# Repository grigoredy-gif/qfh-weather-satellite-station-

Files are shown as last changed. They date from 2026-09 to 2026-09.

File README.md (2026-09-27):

# QFH weather-satellite station: my own antenna and an all-discrete receiver

I'm Edy Grigore, an Electrical Engineering student at the University of
Twente. This is my personal project to receive weather satellites on 137 MHz
with hardware I designed myself: a QFH antenna and a superheterodyne receiver
built only from discrete parts (transistors, diodes, coils and capacitors, no
ICs in the signal path).

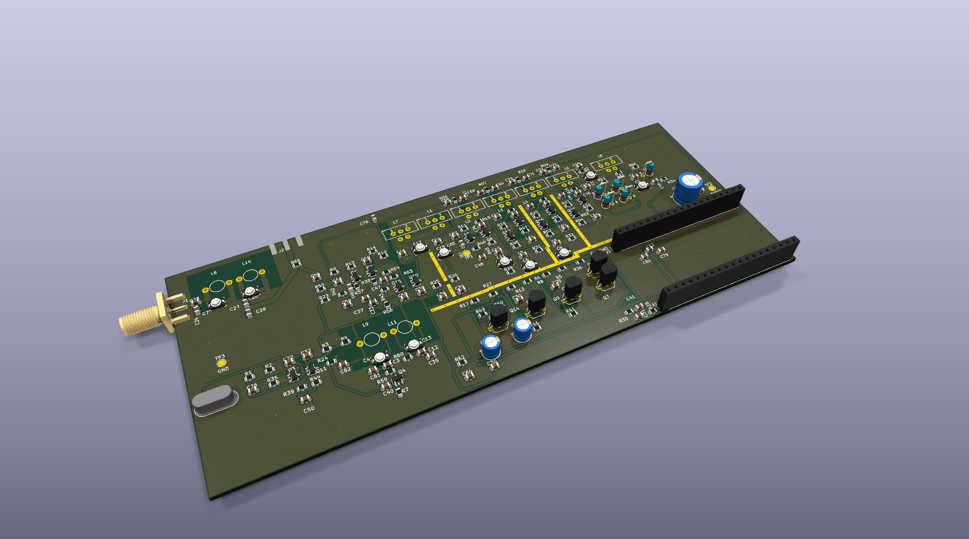
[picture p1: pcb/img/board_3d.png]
3D render of the receiver PCB


## Why I'm doing this

In my first year, the Module 4 project was to design an antenna and a
transmitter PCB. I really enjoyed that field, together with the High Frequency
Electronics, Electromagnetostatics and Electrodynamics courses, so I wanted to
go deeper: design my own antenna and my own receiver, and do the receiver fully
analog so I have to understand every stage at component level.

The NOAA satellites the receiver was designed for were switched off in 2025,
and the remaining Meteor-M satellites send a digital signal an analog FM
receiver cannot decode. So I test the antenna and the receiver separately: the
antenna with an SDR on Meteor-M, the receiver with recorded NOAA passes played
back through an ADALM-Pluto. More in the
[receiver README](fm_receiver/README.md#motivation).

## What's in here

| Folder | What it is | Status |
|---|---|---|
| [`qfh_matlab`](qfh_matlab) | MATLAB toolchain that designs the QFH antenna, exports it to NEC2 and prints a drilling template | antenna designed, simulated and built |
| [`fm_receiver`](fm_receiver) | the receiver design and its LTspice simulations, block by block up to the full chain | simulated from RF input to the ADC |
| [`pcb`](pcb) | the KiCad board for the receiver | designed and checked, ready to order |
| [`lrpt_decoder`](lrpt_decoder) | my own MATLAB analysis chain for Meteor-M LRPT recordings | working; taught me my signal was too weak |
| [`baseband_tools`](baseband_tools) | tools to check an SDR recording before decoding it | working |

## Highlights

- A superheterodyne receiver with about **130 dB** of gain: band-pass filter,
  LNA, mixer, a 25 MHz crystal oscillator multiplied ×5 to 125 MHz, a 12.9 MHz
  IF with four cascode stages, a limiter and a slope detector.
- Every block **simulated in LTspice** on its own, then connected, then the
  whole receiver from an FM input to the audio at the ADC.
- A **2-layer PCB** (180 × 75 mm, 196 parts) with the layout built around RF
  rules: an unbroken ground plane, a straight IF strip, tight tuned circuits
  and test points for block-by-block bring-up.
- The antenna toolchain reproduces its reference program **exactly** (all 127
  NEC wire cards identical) and adds a frequency correction found in simulation.

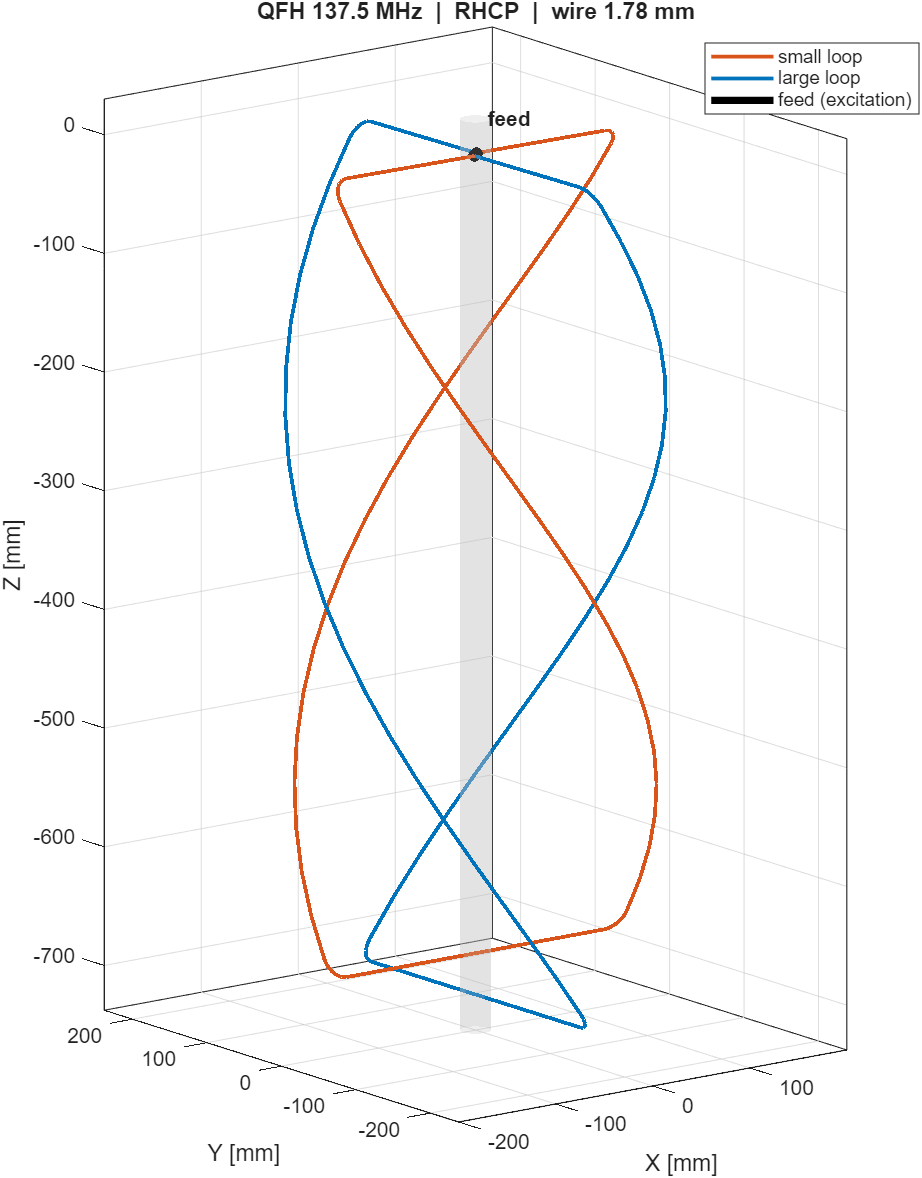
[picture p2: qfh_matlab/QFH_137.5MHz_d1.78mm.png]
QFH antenna model


## What's next

Order and build the PCB, align it one block at a time, and feed it a recorded
satellite pass. On the reception side: an LNA and a 137 MHz SAW filter in
front of the SDR, then another try at Meteor-M.

After that, I want to close the loop with my own hardware on both ends: build
a second QFH antenna and an FM transmitter on my own PCB, and send information
between the two stations, on a frequency I'm allowed to transmit on.

## Tools

LTspice, KiCad 10, MATLAB R2025a, 4nec2 / NEC2, SatDump, an ADALM-Pluto SDR
and a miniVNA Tiny.

## Credits and license

This is my project. I used Claude (Anthropic) as an AI assistant along the
way; each folder's README says exactly what it helped with. The antenna code
is a MATLAB port of John Coppens' online QFH calculator and of QFH2nec, both
GPL-licensed, so `qfh_matlab` is GPL-3.0. Everything else is MIT licensed
(see [LICENSE](LICENSE)).

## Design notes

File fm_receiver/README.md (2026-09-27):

# Discrete FM receiver for 137.9 MHz weather-satellite signals

This is the receiver half of my weather-satellite project. The antenna half (a
QFH antenna with a MATLAB design toolchain) is in [`../qfh_matlab`](../qfh_matlab),
and the circuit board for this receiver is in [`../pcb`](../pcb).

**Goal:** a superheterodyne receiver for the 137.9 MHz weather-satellite band,
built **entirely from discrete parts**: transistors, diodes, coils and
capacitors, with no ICs in the signal path. It demodulates the FM signal down
to the 2400 Hz APT audio tone, and an ESP32's ADC digitizes that audio so
software can turn it into an image. The NOAA satellites that sent APT were
switched off in 2025, so I test with recorded passes played back through an
ADALM-Pluto SDR.

## Motivation

In my first year of Electrical Engineering at the University of Twente, the
Module 4 project was to design an antenna and a transmitter PCB. I really
enjoyed that field, together with the courses that went with it: High Frequency
Electronics, and Electromagnetostatics and Electrodynamics. After the module I
wanted to go deeper than the project allowed, so I decided to design my own
antenna and my own receiver for the 137 MHz weather satellites.

I wanted to do everything analog, without any integrated circuits in the signal
path. That way I have to understand every stage at component level, instead of
letting a chip do the work for me.

The plan had to change along the way. The NOAA satellites whose analog APT
signal this receiver was designed for were switched off in 2025, and the
Meteor-M satellites that are still up send a digital signal that an analog FM
receiver cannot decode. So I test the two halves separately: the antenna with
an SDR on the Meteor-M satellites, and the receiver (once it is built) with
recorded NOAA passes played back into it through an ADALM-Pluto.

The next step is to close the loop with my own hardware on both ends. I want to
build a second QFH antenna and a transmitter, which should be easier than the
receiver, and send information between the two stations with frequency
modulation, using my own PCBs and my own antennas at both ends. That link has
to run on a frequency I'm allowed to transmit on, because 137 MHz is
receive-only for me.

## How it works

```
antenna
   |
band-pass filter 137.9 MHz ---- two coupled air coils, rejects the 112.1 MHz image
   |
LNA (BFR92P) ------------------ about 15 dB of gain, 50 ohm input
   |
mixer <---- LO 125 MHz <------- 25 MHz crystal oscillator > buffer > x5 multiplier
   |
IF filter 12.9 MHz ------------ two coupled toroid tanks, about 200 kHz wide
   |
IF amplifier ------------------ four tuned cascode stages, about 96 dB
   |
limiter > slope detector ------ FM becomes the 2400 Hz audio tone
   |
audio low-pass + level shift -> ESP32 ADC (44.1 kHz) -> APT image in software
```

| Parameter | Value | Why |
|---|---|---|
| RF input | 137.9 MHz | weather-satellite band |
| Crystal | 25 MHz | cheap and standard |
| LO | 125 MHz (25 × 5) | low-side injection |
| **IF** | **12.9 MHz** | 137.9 − 125 |
| Image | 112.1 MHz | lands in the quiet gap between FM broadcast (< 108 MHz) and airband (> 118 MHz) |
| FM deviation | ±17 kHz | APT specification |
| Audio | 2400 Hz subcarrier | the picture is in its envelope |

**The stages, in short:**

- **Band-pass filter.** Two tuned circuits with 82 nH air coils, coupled
  magnetically by their spacing. At 137.9 MHz a coil tap would sit at 0.65 of a
  turn, so a capacitive divider (8.2 pF over 56 pF) does the 50 ohm matching.
  Its main job is to remove the image at 112.1 MHz before it reaches the mixer.
- **LNA.** One BFR92P with shunt feedback and emitter degeneration. It sets
  the noise figure of the whole receiver.
- **Local oscillator.** A 25 MHz crystal Colpitts oscillator, a buffer, and a
  class-C stage that picks out the 5th harmonic (125 MHz) with two coupled
  tanks. A crystal plus a multiplier replaces a PLL: the crystal gives the same
  stability, and I avoid the programmable divider, which is the one block you
  cannot build without ICs.
- **Mixer.** One transistor turns the RF voltage into a current, and a
  transistor pair switched by the LO steers that current into the IF tank. It
  gives about 20 dB of conversion gain.
- **IF filter and amplifier.** Two coupled toroid tanks set the bandwidth, then
  four cascode stages with tapped toroids give about 96 dB of gain. The cascode
  blocks the feedback path through each transistor's collector-base
  capacitance, which is what makes four tuned stages at the same frequency
  possible at all.
- **Limiter and slope detector.** Diodes clip the IF so only the frequency is
  left. A tank tuned slightly off the carrier turns the frequency swing into an
  amplitude swing, and a Schottky diode (1N5711) recovers the audio.
- **Audio chain.** Two Sallen-Key sections built around emitter followers (a
  4th-order Butterworth low-pass), a gain stage, and a divider that centres the signal at 1.26 V in the ESP32 ADC's
  linear range (GPIO36). It has its own RC-filtered supply, so the ESP32's
  current bursts stay out of the audio.
- **Supply.** The ESP32-DevKitC's 5V pin, which is really about **4.6 V**
  (USB VBUS minus a Schottky diode on the module), through a ferrite bead and a
  1000 µF bulk capacitor. The whole receiver draws about 40.7 mA.

## Key design decisions

1. **IF = 12.9 MHz** so the image falls where nothing strong transmits. A simple
   two-resonator filter is then enough, instead of a complex front end.
2. **Crystal × 5 instead of a synthesizer**, to keep the "no ICs" rule without
   losing frequency stability.
3. **Capacitive dividers instead of coil taps** at 137.9 MHz, because the tap
   would need a fraction of a turn.
4. **Cascode IF stages**, because 96 dB of gain at one frequency oscillates
   easily, and the cascode removes the main internal feedback path.
5. **Limiter + slope detector** as the FM demodulator: the simplest discrete
   option, and the one I most wanted to understand.
6. **A fixed capacitor plus a trimmer in every tank**, split so that the trimmer
   lands mid-range even with ±10 % coils and the board's own parasitics.
7. **Design for the real rail.** When I found out the supply is 4.6 V and not
   5.0 V, I re-centred every bias network instead of accepting ~8 dB less IF
   gain.

## Simulations (LTspice)

I simulated every block on its own first, then the connections between blocks,
then the whole receiver. All files are in [`simulations/`](simulations); each sheet has a short
header saying what it tests.

| Sim | What it checks | Key result |
|---|---|---|
| SIM 1 | slope detector | S-curve peak at 12.95 MHz; ~60 mVpp of 2400 Hz, THD 0.78 % |
| SIM 2 | audio filter and ADC interface | flat to 0.70 dB, 45.7 dB down at 22 kHz |
| SIM 3 | IF filter | 200.5 kHz bandwidth at critical coupling |
| SIM 4 | IF amplifier + limiter | 95.8 dB gain; +20 dB in gives only +1.6 dB out |
| SIM 5 | ×5 multiplier | 1.68 V of 125 MHz; 4th and 6th harmonics −36.7 / −42.1 dB |
| SIM 6 | crystal oscillator + buffer | starts and limits at 409.7 mVpp; 2.33 Vpp from the buffer |
| SIM 7 | input band-pass filter | 39.5 dB image rejection, 2.4 dB loss |
| SIM 8 | mixer | 22.8 dB conversion gain |
| SIM 9 | LNA | S21 15.8 dB (about 14 dB expected with the board layout) |
| SIM 10–11 | block interfaces | +20.6 dB from the mixer to the first IF stage |
| SIM 12 | the full receiver on one rail | every bias point matches the block sims; 40.7 mA at 4.6 V |
| SIM 13 | FM in, audio out | a 20 dB input change becomes 0.5 dB at the detector; clean 2400 Hz at the ADC |

End to end the gain is about **130 dB** (−2.2 dB filter, +15.8 dB LNA,
+20.6 dB mixer and IF filter, +95.8 dB IF strip), so the limiter is fully
driven from about −106 dBm at the input. A QFH antenna delivers roughly
−90 dBm from a satellite pass. Most block simulations were run at 5.0 V
before I found the real rail; `sim12` is the one re-centred for 4.6 V and is the
design authority for the PCB.

## Status

- **Done:** every block simulated, the interfaces checked, and the full receiver
  simulated from FM input to the ADC.
- **Done:** the PCB is designed and checked (see [`../pcb`](../pcb)).
- **Next:** order the board, build it, align it one block at a time, and feed it
  a recorded APT pass from the Pluto.

## What I learned

- **A testbench only answers the question you ask it.** Blocks that looked
  finished on their own changed once they were connected: the IF tap had to be
  re-sized and the mixer delivered 4 dB more than the numbers on paper.
- **Check the real supply.** The "5 V" pin on the ESP32 board is 4.6 V, and that
  alone moved the transistor currents by about 16 %.
- **A catalogue beats a schematic.** Trimmer ranges I had specified do not exist
  as real parts, and the transistor I first picked (BFR93A) is obsolete.
- **At VHF the layout is part of the circuit.** A few nanohenries of copper
  moved a filter's trimmer out of range, and 20 mm of track in the LNA's
  emitter would have cost 4–5 dB of gain.
- **Tuned collectors swing above the supply rail.** My first multiplier design
  swung past the transistor's voltage rating.
- **Read the right number.** The wanted spectral line, not the raw
  peak-to-peak; and on the reception side, the mean SNR, not the peak.
- **Predictions can be wrong.** I expected over-coupling the input filter to
  improve image rejection. It made it worse, and I understood why only after
  the simulation.

## Files

| File | What it is |
|---|---|
| [`simulations/`](simulations) | the LTspice simulations `sim*.asc` (short header on each sheet) |
| `simulations/sim12_full_receiver.asc` / `.net` | the full receiver, the design authority for the PCB |
| [`DESIGN_LOG.md`](DESIGN_LOG.md) | the complete step-by-step design log, with every result and revision |
| [`sim_notes.md`](sim_notes.md) | the notes I first wrote on the simulation sheets |

## License / attribution

This is my project. I set the goals and the requirements (a fully discrete
receiver with no ICs in the signal path), I made or approved every design
decision, and the building and bench testing are mine. It builds on
well-documented amateur-radio practice; the references are in the design log.

I used Claude (Anthropic) as an AI assistant. It drafted most of the LTspice
schematics and testbenches from my requirements and helped me analyse the
results. I checked the results and decided what went into the design.

The antenna half of the project (`../qfh_matlab`) is different, because its
code is not originally mine. It is a MATLAB port of two programs that are
freely available online: John Coppens' QFH calculator
([jcoppens.com](https://www.jcoppens.com/ant/qfh/calc.en.php), `qfhcalc.js`,
released under GPL-2.0) and QFH2nec
([github.com/oceantrotter/QFH2nec](https://github.com/oceantrotter/QFH2nec),
GPL-3.0), which itself adapts the Coppens calculator code. That is why
`qfh_matlab` is published under GPL-3.0. The full credits are in its README.

Edy Grigore

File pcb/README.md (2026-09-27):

# PCB — discrete 137.9 MHz FM satellite receiver

This is the circuit board for the receiver I simulated in
[`../fm_receiver`](../fm_receiver). The board is built from that simulation:
its schematic was generated from the full-receiver netlist `sim12`, and if the
board and that netlist ever disagree, the netlist wins.

3D render of the receiver board

## The board at a glance

| | |
|---|---|
| Size | 180 × 75 mm, 2 layers, FR4 1.6 mm |
| Parts | 196, all on the top side |
| Bottom layer | one ground plane |
| Controller | ESP32-DevKitC V4 on a socket (its ADC digitizes the audio) |
| Supply | the DevKitC's 5V pin (really about 4.6 V), about 41 mA |
| Checks | KiCad DRC clean at a 0.254 mm clearance floor; schematic and board match pad for pad |

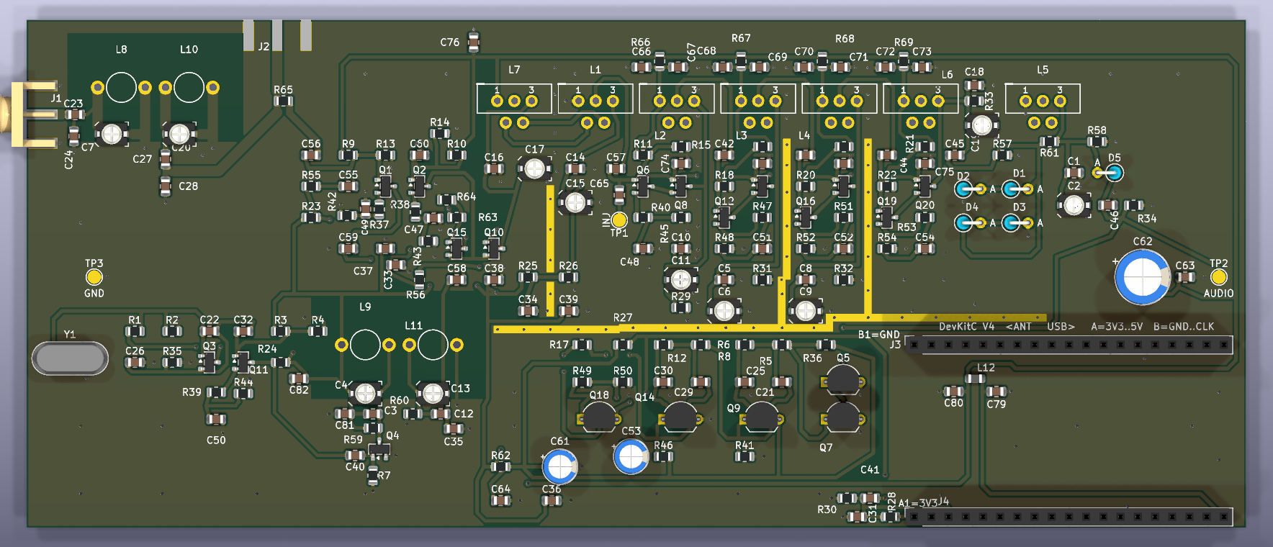
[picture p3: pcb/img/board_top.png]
Top view


## Floorplan

```
+--------------------------------------------------------------------------+
| [SMA ant] BPF (2 air coils, | LNA | MIXER | == IF STRIP, 96 dB, straight |
|  plane cutouts) [SMA test]  | SMD | +T1   |  T2 [1][2][3][4] lim | DET T7 |
|-------- via wall ----------------------------------------------- via wall|
| LO CHAIN: xtal 25MHz | buffer | x5 (2 air coils) -> up into mixer LO port |
|                      AUDIO chain (2400 Hz, folds freely) <- from detector |
|  power entry / bulk filter          ESP32 module socket [USB over edge] > |
+--------------------------------------------------------------------------+
```

The weakest signals (microvolts) start at the left edge and the strongest
(volts) end at the right. The IF strip runs in a straight line with its input
and output at opposite ends, because with 96 dB of gain even a little coupling
from the output back to the input would make it oscillate.

## Layout rules I followed

- **The bottom layer is ground.** Everything is routed on top. A few short
  bottom-layer hops were unavoidable where a trace had to cross another; each
  one is listed and justified in the design log.
- **Shielding provisions for free.** Rows of ground vias between the IF stages
  and between the RF and the LO/audio sections, with exposed ground strips so a
  brass shield can be soldered on later if the strip oscillates.
- **Tight RF loops.** Every tuned circuit's parts sit right at its coil, and the
  LNA's emitter bypass is within about 5 mm of copper of the transistor. At VHF
  a few nanohenries of track change the tuning and the gain.
- **A real 50 ohm antenna input.** The SMA feeds the filter through a 1.5 mm
  coplanar line with ground on both sides.
- **Decoupling everywhere.** Every IF stage has its own 100 nF capacitors on its
  supply and on its cascode bias, fed through its own 10 ohm resistor, so the
  stages cannot talk to each other through the supply.
- **Test points for bring-up.** A second, unfitted SMA with a 0 ohm link at the
  filter→LNA seam (to measure the filter and the LNA separately on a VNA), an
  injection pad at the first IF stage, and a monitor pad on the audio.
- **No parts on the back and no mounting holes**, both on purpose.

The toroids (T37-6, 27 turns) and the air coils (5 mm diameter) use my own
footprints in `qfh_receiver.pretty`. The air-coil footprint keeps copper away
from under the coil, because a ground plane there would kill its Q.

## How I checked it

KiCad's design-rule check is clean at a 0.254 mm clearance floor. The
schematic was generated from the simulation netlist and compared with the board
pad by pad (418 connections, no differences). Every part value was checked
against a real catalogue part at Farnell. I also had the board reviewed by
independent AI review passes, which is how several of the issues below were
found.

## Issues found and fixed

- **Two TO-92 transistor types had base and emitter swapped** because a
  generic symbol used the wrong pin order. Lesson: check each footprint's pinout
  against the datasheet, not against the symbol library.
- **The ESP32 socket would not have powered anything.** The 5 V feed landed on
  a GPIO pin and the enable pin was grounded. I fixed it after checking the
  DevKitC pinout from several sources and every way the module could be
  plugged in.
- **The "5 V" supply is really 4.6 V**, because the DevKitC puts a Schottky
  diode after USB. I re-centred every bias divider in the simulation for 4.6 V
  instead of accepting lower gain.
- **Some specified trimmers did not exist as real parts.** Together with the
  board's own parasitics this pushed three tuned circuits to the end of their
  trimmer range. I re-split the fixed capacitor and the trimmer in each one so
  the trimmer now lands mid-range.
- **The LNA's emitter bypass capacitor was 20 mm from the transistor.** That
  is about 12 nH, which would have cost 4–5 dB of gain. It is now within 5 mm.

## Bring-up plan

1. Power only: check every DC voltage against `sim12`.
2. Local oscillator: 25 MHz at the crystal, then 125 MHz at the mixer.
3. Filter and LNA: fit the test SMA, remove the 0 ohm link, sweep them on the
   VNA. Expect about 39 dB of image rejection and an LNA gain of at least
   13.5 dB.
4. IF strip: with no signal, the limiter output should show only noise (a
   steady tone means it oscillates). Then inject 12.9 MHz at the test pad and
   align the tanks.
5. The whole chain: a recorded APT pass from the Pluto into the antenna input.

Expected trimmer settings: band-pass filter about 6.5 pF, ×5 multiplier about
5.4 pF, LO output about 5.8 pF. If one lands far from that, its coil probably
came out wrong.

## Ordering

The bill of materials with Farnell order codes is `fabrication/qfh_receiver_bom.csv`, and the gerbers for JLCPCB are `fabrication/qfh_receiver_gerbers_jlc.zip`.
Every pF-range capacitor must be NP0/C0G, and the crystal must be a
fundamental-mode part. Both SMAs are edge-launch parts whose pads run to the
board edge on purpose, so the board house may ask about copper at the edge.

## Files

| File | What it is |
|---|---|
| `qfh_receiver.kicad_pro` / `.kicad_sch` / `.kicad_pcb` | the KiCad project, schematic and board |
| `qfh_receiver.kicad_dru` | custom design rules (edge clearance at the two SMAs) |
| `qfh_receiver.pretty/` | my footprints for the toroids and air coils |
| `fabrication/` | the bill of materials and the gerbers for ordering |
| `img/` | board renders |
| [`DESIGN_LOG.md`](DESIGN_LOG.md) | the complete step-by-step design log |

## Attribution

This board is my project: I set the requirements and the layout rules, and I
approved every change. I will assemble, align and measure it myself. I used
Claude (Anthropic) as an AI assistant for the KiCad work: following my
requirements and reviews, it did most of the placement and routing by script,
ran the design checks and did independent review passes. The full step-by-step
record is in [`DESIGN_LOG.md`](DESIGN_LOG.md). The motivation for the project is
in the [receiver README](../fm_receiver/README.md).

Edy Grigore

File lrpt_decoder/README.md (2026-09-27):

# lrpt_decoder — a from-scratch Meteor-M LRPT analysis chain in MATLAB

I wrote these tools in August 2026 to answer one question my station kept
raising: *SatDump's Viterbi locks on Meteor-M N2-3 (137.9 MHz) with BER 0.03,
so why does the deframer never sync and why are there no images?*

> **Correction (9 August 2026):** the first conclusion I drew from these tools
> was wrong. The satellite was fine. My signal was too weak. Details below.

## What I thought at first

Working one tool at a time, I found a fully standard CCSDS link layer (OQPSK
72k, K=7 r=1/2 convolutional coding 171/133 octal, NRZ-M, per-frame CCSDS
randomizer, ASM `1ACFFC1D`, AOS headers ver 1 / SCID 0 / VCID 5 with live
counters). But the frames seemed to come 424 bytes (counter +1) and 1148 bytes
(counter +2) apart instead of in standard 1024-byte CADUs, and the payload
looked like random data. So I concluded that the satellite was sending a
nonstandard mode that no public decoder could turn into images.

## What was actually going on

After searching some forums (r/meteorsatellites), I found out that the
satellite was online and working: other people were receiving images from
Meteor-M N2-3 and N2-4 in the same weeks. Several fellow enthusiasts gave me
the same answers:

- **My signal was too weak and too inconsistent.** The "~10 dB SNR" I trusted
  was SatDump's *peak* SNR, which includes noise spikes. The *mean* SNR was
  only **1.763 dB**, below the ~3–4 dB the deframer needs to lock. "Viterbi
  but no deframer" is the typical sign of a very inconsistent signal.
- **The strange frame sizes were not real.** The 424/1148-byte spacings were
  artifacts of an error-ridden stream, where many ASM detections were simply
  missed.
- **My gain was set badly.** The advice was to start low and raise the gain
  during the pass until the mean SNR is at its best.
- **My location was bad for reception, and the ADALM-Pluto is not ideal for
  this use.** Its input is unfiltered, so FM broadcast (88–108 MHz) overloads
  it and creates intermodulation products, and without an LNA it is quite deaf
  at 137 MHz. The fix is an LNA plus a 137 MHz SAW filter in front of it, which
  is exactly what the input stages of my own receiver do (see
  [`../fm_receiver/`](../fm_receiver/), SIM 7 and SIM 9).
- On top of that, N2-3 was reported to have a degraded antenna, so it is a
  weak satellite to start with.

So the station software and SatDump were fine; the signal was the problem.
The tools themselves still work and are useful for looking inside a weak or
strange recording. Only the conclusion I first drew from them was wrong.

## The tools (run them in this order)

| # | Tool | Question it answers |
|---|---|---|
| 1 | `lrpt_sync.m` | baseband → synchronized symbols. Doppler tracking, open-loop symbol timing from the 72 kHz clock line, OQPSK + plain-QPSK branches, constellation quality metrics |
| 2 | `lrpt_frame_hunt.m` | do CCSDS frames exist? Correlates the encoded-ASM 52-chip template across 96 demod-ambiguity variants; self-tests the encoder against SatDump's correlator constant |
| 3 | `lrpt_loop_test.m` | is it a repeating test loop or changing data? |
| 4 | `lrpt_viterbi_peek.m` | state-seeded Viterbi decode after each ASM; reads the AOS headers |
| 5 | `lrpt_deep_peek.m` | long decodes through whole periods; frame accounting via counters |
| 6 | `lrpt_hdr_scan.m` | exhaustive header scan (every byte offset × both randomizer conventions) |
| 7 | `lrpt_walk.m` | walks the frame chain with a size/step rule; M-PDU/APID census |
| 8 | `lrpt_frame_dump.m` | aligned hex dumps per frame class; finds constant fields by eye |
| 9 | `lrpt_prbs_test.m` | is the payload a modem test pattern? (all ITU O.150 polynomials) |

Everything is base MATLAB (R2025a, no toolboxes). The companion folder
`../baseband_tools/` has the recording-health tools (`baseband_check.m`,
`signal_id.m`, `cut_segment.m`). Run those on any capture first.

## Method notes (learned the hard way)

- **Check the mean SNR before anything else.** If the stream is below the
  decoding threshold, a deep analysis will find "structure" in its own errors.
  That is exactly what happened to me here.
- Never trust a single measurement window or a single timestep. Prove
  convergence/settling with two spaced windows.
- Anchor the analysis in the **densest-detection** region, not at the
  "strongest" correlation peak. Correlation saturates wherever the signal is
  good, so picking the strongest peak first lands on the noisy edge of the pass.
- When a decoder disagrees with the RF evidence, measure one layer deeper
  instead of re-running the decoder with one more setting. But first make sure
  the RF evidence is strong enough to mean something.

## Attribution

I (Edy Grigore) developed these tools together with **Claude (Anthropic)**,
which I used as a coding and DSP-reasoning assistant. The AI drafted the
scripts from hypotheses we came up with together, I ran them on my own
recordings, and each result decided the next step (including throwing out
several of our own wrong hypotheses along the way). The receptions, hardware,
measurements and accept/reject decisions are mine.
Protocol facts were cross-checked against: CCSDS 131.0-B / 732.0-B,
SatDump (Analog Devices / SatDump project sources), dbdexter's
`meteor_demod`, artlav's `meteor_decoder`, USRadioguy's Meteor-M pages and
the happysat status history. The correction of my first conclusion came from
the r/meteorsatellites community.

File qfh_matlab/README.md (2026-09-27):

# qfh_matlab — QFH antenna generator for 137 MHz weather satellites

This is a MATLAB toolchain that designs a **QFH (Quadrifilar Helix) antenna**.
It draws the antenna in 3D and exports a **`.nec` file for electromagnetic
simulation in [4nec2](https://www.qsl.net/4nec2/)**. I made it to receive
137 MHz weather-satellite images (RHCP) with an ADALM-Pluto SDR.

> **Satellite status (2026):** the NOAA POES satellites (analog APT) were
> switched off in June–August 2025 and **no longer transmit**. The
> 137 MHz satellites to target now are **Meteor-M N2-3 / N2-4 (digital LRPT)**
> on 137.1 and 137.9 MHz. They are also RHCP, so the antenna itself does
> not change. The decoding is done with SatDump. A 137.5 MHz design covers
> both frequencies without problems.

## Motivation

In my first year of Electrical Engineering at the University of Twente, the
Module 4 project was to design an antenna and a transmitter PCB. I really
enjoyed that field, together with the courses that went with it: High Frequency
Electronics, and Electromagnetostatics and Electrodynamics. After the module I
wanted to go deeper than the project allowed, so I decided to design my own
antenna and my own receiver for the 137 MHz weather satellites.

For the receiver I wanted to do everything analog, without any integrated
circuits in the signal path, so that I have to understand every stage at
component level. This toolchain is the antenna half of the project. The
receiver half is in [`../fm_receiver`](../fm_receiver).

The plan had to change along the way. The NOAA satellites whose analog APT
signal my receiver was designed for were switched off in 2025, and the
Meteor-M satellites that are still up send a digital signal that an analog FM
receiver cannot decode. So I test the two halves separately: this antenna with
an SDR on the Meteor-M satellites, and the receiver with recorded NOAA passes
played back into it through an ADALM-Pluto.

The next step is to close the loop with my own hardware on both ends. I want to
build a second QFH antenna and a transmitter, which should be easier than the
receiver, and send information between the two stations with frequency
modulation, using my own PCBs and my own antennas at both ends. That link has
to run on a frequency I'm allowed to transmit on, because 137 MHz is
receive-only for me.

## Attribution

This toolchain is my project, but I did not invent the design method, and the
original code is not mine. It is a MATLAB port of programs that are freely
available online:

- **[John Coppens' QFH calculator](https://www.jcoppens.com/ant/qfh/calc.en.php)**:
  the online QFH calculator on John Coppens' website. Its JavaScript source
  (`qfhcalc.js`) is released under **GPL-2.0**. The empirical design formulas,
  the conductor-diameter compensation tables and the dimension conventions all
  come from there. My printable mast-drilling template is also directly
  inspired by the one his design tool generates (wrap-around strips with
  real-size hole circles).
- **[QFH2nec](https://github.com/oceantrotter/QFH2nec)** (`QFH2nec.c`,
  **GPL-3.0**): the wire-by-wire geometry and the NEC2 card export are a
  direct port of this program, which itself adapts the Coppens calculator
  code.
- **[helix2nec](https://uuki.kapsi.fi/qha_simul.html)**: the original
  bifilar-helix-to-NEC generator that QFH2nec is based on.
- **NEC2**: the simulation engine underneath, developed by G. Burke and
  A. Poggio at Lawrence Livermore National Laboratory.

The port was validated against the original: `QFH2nec.c` was compiled with
gcc and the generated NEC geometry was compared line by line. **All 127 GW
cards match with exactly zero coordinate difference** (with
`freq_cal = 1.0`, `c_kms = 299792`, `feed_len_mm = 2`).

The MATLAB code was mostly written with **Claude (Anthropic)** as an AI coding
assistant: the port itself, the plotting/export code, the self-test suite and
the drilling-template generator. I checked the results against the compiled C
original, the output of the Coppens website and, in the end, the antenna I
built from these drawings and measured with a VNA. The antenna itself, its
construction, the measurements and every accept/reject decision are mine.

Edy Grigore

The code comments were first written in Romanian during development and later
translated to English for publication.

## What this port adds on top of the originals

- A modular MATLAB pipeline with parameters (each step is its own `.m` file)
- A 3D view of the antenna in MATLAB (+ PNG export)
- **Frequency calibration** (see the section below). The original
  formulas give a resonance ~2.2% below the requested frequency, and
  this port can correct for it
- A printable 1:1 A4 **drilling template** for the mast. MATLAB makes
  the PDF itself, with wrap-around strips, real-size hole circles and a
  calibration bar. The layout is inspired by the template of the Coppens
  design tool
- An automatic **self-test suite** with 62 checks. It reproduces the
  reference values from the Coppens website, checks that the geometry is
  continuous, validates the .nec structure, and checks the calibration
  math and the drilling-template geometry
- Extra geometry checks that the C original does not have (guards
  against degenerate geometry: `H > 2R`, feed length vs. loop size)
- Two bugs in `QFH2nec.c` that came up during porting (fixed here and
  described below)

## Frequency calibration (`freq_cal`)

**The problem.** The Coppens design formulas are empirical. When I
simulate the geometry they give in NEC2 (free space), the real resonance
is about **2.2% below** the design frequency. For example, a 137.5 MHz
design has its SWR minimum at ≈134.5 MHz.

**The fix.** The whole geometry scales with the wavelength. So if I
design at a slightly *higher* frequency, the resonance moves up
linearly. The `freq_cal` parameter does this internally:

```
effective design frequency = freq_mhz × freq_cal
freq_cal = 137.5 / 134.5 ≈ 1.0223     (derived from the NEC2 sweep)
```

**Verification.** With `freq_cal = 1.0223`, the 4nec2 simulation of the
137.5 MHz target design gives **SWR ≈ 1.05 at 137.5 MHz** (reflection
coefficient ≈ −33 dB), and the SWR minimum sits right on the target. I
checked the factor for both 1.78 mm and 7 mm conductors.

**Why I did not change the Coppens formulas themselves.** They were
calibrated on real, built antennas. Those include effects that a
free-space NEC2 model does not see (feedline, mast, insulation, real
corner shapes). So the difference is a *modeling offset*, not just an
error in the original formulas. I kept the correction as a separate,
documented factor (default **1.0** = the same output as Coppens/QFH2nec).
This way you can choose either convention, and `qfh_selftest` still
checks the port against the website values with `freq_cal = 1.0`. For a
real build, the final trim should be based on a VNA measurement at the
feedpoint.

## Usage

1. Open MATLAB and `cd` into this folder.
2. Edit the parameters in `qfh_main.m` (target frequency, wire diameter…).
3. Run:

   ```matlab
   qfh_main
   ```

   This gives you the dimension table in the Command Window, the 3D
   figure (+ PNG) and the `QFH_137.5MHz_dX.XXmm.nec` file.

4. Open the `.nec` file in 4nec2 (`File > Open 4nec2 in/out file`) and
   run the simulation with `F7` (choose *Far Field pattern*). Then check:
   - impedance / SWR at 137.5 MHz (main window + the SWR plot);
   - the far-field pattern: the main lobe should point to zenith (theta = 0);
   - polarization: the **RHCP** gain must be the strongest toward zenith
     (in 4nec2: *Far field > Polarization > LHCP/RHCP*).

## Files

| File | Role |
|---|---|
| `qfh_main.m` | main script, set your parameters here |
| `qfh_defaults.m` | fills in / validates parameters |
| `qfh_design.m` | dimension computation (port of `compute_design` / Coppens) |
| `qfh_report.m` | construction dimension table |
| `qfh_geometry.m` | 3D geometry: wire list (port of `make_helix`) |
| `qfh_plot3d.m` | 3D visualization in MATLAB |
| `qfh_write_nec.m` | `.nec` export (GW/FR/EX/RP cards) |
| `qfh_selftest.m` | automatic tests (design vs. website, geometry, .nec, calibration) |
| `qfh_drill_marks.m` | drill positions on the mast (wire + support-tube holes) |
| `qfh_write_template.m`| printable 1:1 A4 drilling template (PDF, Coppens-inspired) |
| `qfh_run_template.m`  | generates the template for your mast/support diameters |
| `qfh_wire_compare.m`  | generates two .nec files to compare conductor diameters |

## Verification

```matlab
qfh_selftest
```

Test A reproduces the exact values of the Coppens website calculator for
the reference configuration (137.5 MHz, 7 mm conductor): H1=731.8,
Di1=315, H2=695.8, Di2=299.1, etc. Tests B–E check geometry continuity,
the exported `.nec` structure, the frequency-calibration math and the
drilling-template geometry. As an extra check, the uncalibrated drill
depths (`freq_cal = 1.0`, 1.78 mm wire) match the values in the template
PDF that the Coppens website generates itself, to within 0.1 mm (e.g.
bottom station 687.8 mm, middle station 343.9 mm).

## Conductor diameter (solid copper installation wire)

| Cross-section (FY / H07V-U) | Diameter |
|---|---|
| 1.5 mm² | 1.38 mm  |
| 2.5 mm² | 1.78 mm  |
| 4.0 mm² | 2.26 mm  |
| 6.0 mm² | 2.76 mm  |

Measure your wire with a caliper (without the insulation) and set
`params.wire_d_mm`. The diameter goes into the compensation factor, so
all dimensions are recomputed correctly for your wire. When I simulated
1.78 vs 2.76 mm, the electrical difference was negligible for this
design. So you can choose the wire for mechanical reasons.

## Notes

- **Polarization**: weather satellites transmit RHCP. The QFH radiates
  in *backfire* mode (the lobe comes out of the feed end, upward), so
  the winding direction is opposite to the polarization. The code
  handles this automatically (negative `turns`), the same way as
  QFH2nec.c. You can switch to `LHCP` with `params.polarity`.
- **Bugs found in `QFH2nec.c` while porting** (fixed in this port):
  1. the wire radius is halved twice (once in `compute_design`, once in
     `main`), so the C program writes a radius of `d/4` instead of `d/2`
     into the .nec file;
  2. `h[0].Theta` is used uninitialized (stack garbage). The reference
     build used for the validation was patched with `Theta = 0`.
- **Speed of light**: the Coppens website uses c = 300000 km/s and the C
  code uses 299792. Here the website value is the default (0.07%
  difference). You can change it with `params.c_kms`.
- **Other intentional differences from the C original**: the diameter
  check also accepts thin wires (0.5–50 mm; C requires ≥ 1 mm). The feed
  length can be set (`feed_len_mm`, default 10 mm; C hardcodes 2 mm).
  There are also guards against degenerate geometry (H > 2R etc.) that
  do not exist in C.
- **Template top-hole convention**: the drilling template puts the top
  wire holes on the cardinal axes of the loops (0°/180° and 90°/270°).
  This matches the Coppens template and makes the build easier, and at
  the top the wires are bent a bit toward the offset feed point anyway.
  The *simulated* model keeps the exact QFH2nec feed geometry, where the
  slanted top radials cross the mast wall at ~11.6°/78.4° (default
  build). The difference is ~3 mm of arc at the mast wall (~0.0014 λ),
  which is electrically negligible. Set `params.top_marks = 'exact'` if
  you want to mark the simulated wall crossings instead.
- **Mast circumference**: measure it by wrapping a paper strip or a
  string around the mast. This is much more accurate than holding a
  ruler across a round pipe. Then set `params.mast_d_mm = circumference/pi`,
  and the template strips meet exactly on the seam.
- **Real feed**: when you build it, feed the antenna through an *infinite
  balun* (the coax goes up inside the mast) or add a common-mode choke
  (5–8 turns of coax, ~10–15 cm diameter, right below the feedpoint).
  The impedance of the antenna itself is close enough to 50 Ω, so no
  matching network is needed for reception.

## License

GPL-3.0. This project is a derivative work of GPL-licensed code
(`QFH2nec.c`, GPL-3.0; `qfhcalc.js`, GPL-2.0), so it is published under the
GPL as well. See [LICENSE](LICENSE).

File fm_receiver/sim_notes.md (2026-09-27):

# Simulation sheet notes (archive)

These are the long notes I originally wrote directly on the LTspice schematic sheets, while working through each simulation. In September 2026 I moved them here so the schematics are readable; each sheet now has a short header instead. The notes are kept as written at the time, so some numbers here are older than the current design (for example 5.0 V instead of the real 4.6 V rail, or old trimmer ranges). The current explanation and numbers are in `DESIGN_LOG.md` (full story) and `README.md` (overview).

## slope_tank_test.asc

*Now: Tank test - 12.9 MHz tank resonance sanity check. Explained in fm_receiver/DESIGN_LOG.md, table 'Simulation roadmap (LTspice)', row 0.*

Slope detector tank - .asc connectivity test Resonance ~12.90 MHz (L=2.2uH, C=69.2pF). Plot V(out): peak -6dB at resonance, BW ~210 kHz (Q~60).

## sim1a_slope_scurve.asc

*Now: SIM 1a - slope detector S-curve (rev 5). Explained in fm_receiver/DESIGN_LOG.md, section 'SIM 1 - slope detector'.*

SIM 1a rev2 - slope detector, static S-curve (detected DC vs carrier frequency) REV3: rev1 found the tank detuned low by the detector; rev2's -2.2p (datasheet Cjo) was not enough - measured peak 12.84 MHz -> total parasitic ~3.3p (junction plus diffusion capacitance while the diode conducts). C1 = 65.4p puts the tank at ~12.94 MHz, the optimum detune for the MEASURED Q~122. On the bench this is the trimmer alignment. Two stepped measurements now: Vtank (true tank resonance + drive level, separates tank problems from detector problems) and Vdet (detected DC = the S-curve). Run, then View > SPICE Error Log > right click > Plot .step'ed .meas data. Pass: Vtank peak clearly resolved; Vdet flank steep and quasi-linear through 12.90. REV4: maxstep 5n -> 1n + compression off + .save, after the timestep study (sim1c/1d) showed the 5n run inflated the response ~2x - the diode's conduction pulses and its nonlinear junction capacitance need ~80 points per carrier cycle to integrate honestly. REV5: the CONVERGED S-curve put the resonance at 13.08 MHz with a 520 mV peak - the diode really adds only ~1.9p (not the ~3.3p the coarse 5n run faked) and loads the tank lightly. C1 trimmed 65.4p -> 66.7p, target f0 = 12.955 MHz (+55 kHz above the carrier, the max-slope point for the measured Q ~80). Sweep narrowed to 5 kHz steps. Lesson kept for the README: never trim a design against an unconverged simulation.

## sim1b_slope_demod.asc

*Now: SIM 1b - slope detector FM demodulation (rev 4). Explained in fm_receiver/DESIGN_LOG.md, section 'SIM 1 - slope detector'.*

SIM 1b rev4 - slope detector, dynamic test: real FM in -> audio out REV4: C1 = 66.7p per the CONVERGED S-curve (sim1a rev5): the diode really adds only ~1.9p, so the tank sits at 12.955 MHz, +55 kHz above the carrier = max-slope point. maxstep 1n + compression off (the 5n/2n runs were shown unconverged by sim1d). Source: SFFM carrier 12.9 MHz, deviation +/-17 kHz at 2400 Hz (mod index 7.083). Expected on V(audio): ~0.24 V DC with ~45-55 mVpp of 2400 Hz on top. THD readout (.four, end of SPICE Error Log): use the PARTIAL figure = in-band harmonic distortion of 2400 Hz (target < 5 percent). The TOTAL figure also counts the residual 12.9 MHz ripple, which the stage-10 audio low-pass removes anyway.

## sim1c_debug_dc.asc

*Now: SIM 1c - debug run: modulated vs unmodulated carrier. Explained in fm_receiver/DESIGN_LOG.md, section 'SIM 1 - slope detector'.*

SIM 1c - A/B debug: why did sim1b read 88 mV DC when sim1a says ~245 mV at 12.9 MHz? Same circuit as sim1a/1b rev3. The source is stepped: M=0 (unmodulated carrier) vs M=7.083 (the real APT deviation). Measurement window = exactly one 2400 Hz period. Expected if everything is consistent: Vdc ~245m and Vtankpk ~420m for BOTH steps (the +/-17 kHz swing barely moves the average on the flank). If M=0 already gives ~88m -> file/version mismatch, re-open sim1b from disk. If M=0 gives ~245m but M=7.083 drops -> the modulation itself does it: plot V(tank) zoomed on 100 us to SEE the RF envelope and find out what the FM does to the tank.

## sim1d_timestep_check.asc

*Now: SIM 1d - solver timestep check. Explained in fm_receiver/DESIGN_LOG.md, section 'SIM 1 - slope detector'.*

SIM 1d - timestep convergence check. Same circuit, plain 12.9 MHz carrier. Context: identical circuit gave Vtank 412m / Vdc 245m at maxstep=5n (sim1a) but Vtank 224m / Vdc 87m at maxstep=2n (sim1c). One of them is a numerical artifact: at 5n only ~15 points resolve each carrier cycle and the diode's brief conduction pulses + its nonlinear junction capacitance (~40 uA reactive!) integrate poorly. REV: now at maxstep = 0.5n. Ladder so far: 5n -> 412m/245m, 2n -> 224m/87m,

1n -> 204m/76m. If 0.5n lands near the 1n values, 1n is converged enough.

If Vdc(1n) matches the 2n result (~87m) -> 2n was converged, the 5n run and the naive R_in=RE/2 theory were both optimistic, and the detector loads the tank much harder than designed -> lighter coupling or higher RE needed. Diode current avg/rms tell how.

## sim2a_audio_freq.asc

*Now: SIM 2a - audio low-pass filter (rev 3b). Explained in fm_receiver/DESIGN_LOG.md, section 'SIM 2 - audio filter and ADC scaling'.*

SIM 2a - audio low-pass filter and ADC scaling: FREQUENCY RESPONSE (.ac).

WHAT THIS STAGE IS FOR. The slope detector delivers ~60 mVpp of 2400 Hz on a 0.23 V pedestal, behind ~150k. That is the APT subcarrier, and its amplitude IS the picture: the ESP32 samples this audio at 44.1 kHz and software turns the envelope into pixels. So this block has exactly two jobs - anti-alias filtering before that sampler, and enough gain to use the ADC's range.

WHY ACTIVE AND NOT JUST RC. APT occupies 320-4480 Hz (2400 Hz subcarrier +/- the 2080 Hz pixel rate), and Nyquist for 44.1 kHz sampling is 22 kHz. Three cascaded passive RC poles at fc = 6 kHz only reach ~20 dB at 22 kHz - soft skirts, no resonant poles. Two Sallen-Key sections give a 4th-order Butterworth: ~-46 dB at 22 kHz with under 1 dB of passband ripple, using two transistors. Section 1 (Q2, NPN follower): 10k/10k with 2.7n/2.2n -> Q=0.55, fc 6.5 kHz. Section 2 (Q3, PNP follower): 7.5k/7.5k with 8.2n/1.2n -> Q=1.31, fc 6.8 kHz. Together: Butterworth, corner ~6.6 kHz.

WHY A DARLINGTON AT THE INPUT, AND WHY PNP. The detector's 150k source impedance is brutal: a single transistor's base current through it would shift the detector's own operating point by ~0.3 V - moving the carrier off the slope and wrecking SIM 1's linearity. A Darlington cuts that to ~2 mV. PNP because the chain is DC-coupled and a PNP follower shifts the level UP by one Vbe while an NPN shifts it DOWN. Alternating PNP-NPN-PNP keeps every stage biased inside a single 5 V rail with no coupling capacitors and no negative supply. Starting at 0.23 V: 1.36 V -> 0.74 V -> 1.41 V.

(Not 0.7 V per junction: Vbe = VT*ln(Ic/IS), and Q1a carries only Q1b's BASE

current - about 2 uA - so its Vbe is ~0.50 V while Q1b's, at 0.46 mA, is ~0.64 V. The Darlington shift is +1.13 V, not +1.30 V.)

NOTE ON THE DRAWING: LTspice's PNP symbol sits collector-up, so on Q1a, Q1b and Q3 the GROUND flag is above the device and the supply below it. That looks upside down next to the NPN stages but is electrically right - a PNP's emitter belongs at the positive end. Supply and ground are net labels throughout rather than long rails, which keeps the signal path readable.

GAIN STAGE Q4: common emitter, 150R unbypassed sets the gain by feedback. (REV 3b) Ic ~ 0.85 mA, re ~ 30 ohm, collector load 3.3k in parallel with the 10k/6.2k divider = 1.9k, so Av ~ 9.7. 120 mVpp in becomes ~1.17 Vpp at the ADC - about a third of the 3.3 V range, all inside the ADC linear window. Without this stage the ADC would see 60 mV out of 3.3 V: barely 6 effective bits. CC1/RD1/RD2 re-centre the signal on 1.26 V (the linear region of the ESP32's own 3.3 V rail) and CADC is the last anti-alias pole right at the pin.

CHANGED FROM THE .cir VERSION: supply 5 V -> 6 V, so the whole receiver runs off one rail, and RE4B 3.3k -> 2.7k. The second change came out of a review that actually ran the circuit: with 3.3k the collector sat at 3.69 V, high on a 6 V rail and lopsided for the swing. 2.7k lands it at 3.23 V and drops the in-band THD from 4.66 % to 3.73 % for free - the filter response is unchanged.

PASS (rev 3b): |V(adc)| flat within 1 dB over 400-4400 Hz; >= 30 dB down at 22 kHz (expect ~46-47); the 12.9 MHz IF ripple region annihilated (>100 dB). Gmid is the mid-band gain - it should read ~10-11 (~20 dB) into the ADC node.

REV 2 - BACK TO 5 V (see the README's supply-rail section: the .cir was 5 V, the .asc conversion inherited 6 V, and now the whole receiver runs 5 V). The bias ladder is anchored to the detector pedestal through junction drops, so it does not see the rail; only the PNP follower currents (0.46 -> 0.36 mA, harmless) and Q4's collector DC change. RE4B stays 2.7k rather than reverting to the .cir's 3.3k: THD is dominated by re modulation, which falls with bias current - 2.7k keeps Ic at 0.27 mA, and the swing still has 1.3 V of down-room against 0.76 V of need. Filter shape: rail-independent, unchanged.

REV 3 - THE ESP32 MODULE INTERFACE, and a re-characterization. Decision: the receiver feeds an ESP32 dev MODULE (USB, easy to program and procure), not a bare chip. Three consequences, all handled here. (1) ADC SOURCE IMPEDANCE. The old 47k/47k divider presented 23.5k. The ESP32 SAR ADC wants <10k: with 23.5k and CADC 470p the pin charges with tau = 11 us against a 22.7 us sample period - two time constants, i.e. a sample-dependent error landing straight on picture brightness. (2) ADC LINEARITY. On 1.65 V the old 1.5 Vpp swung to 2.4 V, hard against the ESP32 ADC nonlinear region above ~2.45 V. New divider 10k / 6.2k puts the pedestal at 1.26 V and the swing at 0.6-1.9 V - inside the linear part. Source impedance drops to 3.83k, and supply rejection at the ADC improves from 70 % to 28 % because the collector now works into a lower load. CADC 470p -> 2.2n: a bigger charge reservoir for the SAR, and a 26 kHz pole. (3) SUPPLY NOISE. The module 5 V pin is USB VBUS - laptop SMPS noise plus the ESP32 own 250-500 mA WiFi bursts through cable resistance, i.e. tens to hundreds of mV, with content in the audio band. This block has poor PSRR by construction (ripple reaches the collector through RC4), so it now gets its own rail: RSUP 100 + CSUP 100u = a 16 Hz corner, -43 dB at 2400 Hz, for 0.11 V of drop at the 1.1 mA this chain draws. On the PCB put 100n in parallel with CSUP (an electrolytic alone is useless above ~100 kHz), and keep WiFi off during a pass - record first, transmit afterwards. ALSO REV 3: the drive is now the level SIM 13 actually MEASURED at the detector with the real limiter driving it - 120 mVpp on a 0.31 V pedestal, not the 60 mVpp / 0.23 V that SIM 1 predicted from an idealized source. The real limiter drives the detector tank harder and the S-curve slope grows with drive. Gain therefore falls from ~28 to ~11, which is the point: the 2x overdrive found in SIM 13 is absorbed by the same divider change.

REV 3b - Q4 OPERATING POINT, after the rev 3 run measured 7.5 % THD. Root cause, from the numbers: with 120 mVpp in and re = 86 ohm against 150 ohm of degeneration, v_be swung +/-22 mV against a 25.8 mV V_T - the emitter current was modulated +/-85 %, so re itself swung 47..577 ohm. H2 7.46 % vs H3 0.78 % confirms re modulation, not clipping. WHAT IT ACTUALLY COSTS: the picture lives in the ENVELOPE of the 2400 Hz subcarrier, and H2 at 4800 Hz is outside the envelope band. The metric that matters is gain compression: 10.17 small-signal vs 9.83 large-signal = 3.3 % at full white, which the APT calibration wedge corrects anyway. So rev 3 was usable - but the operating point had become tight (V_CE fell to 0.46 V on negative peaks), so two resistors buy margin AND linearity: RC4 10k -> 3.3k and RE4B 2.7k -> 820. Q4 current rises 0.30 -> 0.81 mA, re falls 86 -> 32 ohm, v_be swing halves to +/-11 mV (0.43 of V_T), the collector sits at 2.2 V and V_CE bottoms at 0.83 V instead of 0.46. Gain is deliberately unchanged (~9.7, ~1.17 Vpp out) - this buys linearity and headroom, not level. Cost: 0.5 mA and 0.06 V more drop across RSUP.

## sim2b_audio_thd.asc

*Now: SIM 2b - audio levels, bias and ESP32 interface (rev 3b). Explained in fm_receiver/DESIGN_LOG.md, section 'SIM 2 - audio filter and ADC scaling'.*

SIM 2b - audio chain: LEVELS, BIAS AND DISTORTION (.tran).

Identical circuit to SIM 2a - see there for the full description. The .ac run proves the filter shape; this one proves the chain is actually biased and linear at the real signal level, which small-signal analysis cannot show.

DRIVE: the MEASURED SIM 13 detector output - 120 mVpp of 2400 Hz on a 0.31 V pedestal, behind 150k. The transient starts from the DC operating point (no uic), so the 100 uF emitter bypass and the 1 uF coupler are pre-charged and the run only needs 20 ms. Measuring from 10 to 20 ms is settled.

THE BIAS LADDER IS THE POINT OF Vef1/Vef2/Vef3. This chain is DC-coupled all the way, so every stage's operating point is inherited from the one before it - there are no coupling capacitors to hide a mistake. The alternating PNP/NPN followers should show the level bouncing rather than drifting: in ~0.31 V -> ef1 ~1.43 -> ef2 ~0.80 -> ef3 ~1.46 V. If any of those walks away, a later stage is starved or saturated and the distortion figure below is meaningless.

Vindc is the honesty check on the Darlington: it should read ~0.31 V, i.e. the amplifier has NOT dragged the detector's pedestal. A single transistor here would pull it by ~0.3 V and quietly move SIM 1's carrier off the straight part of the slope - the fault would look like distortion appearing in the detector, three blocks upstream of its real cause.

PASS (rev 3): Vadcavg ~ 1.26 V   (ESP32 ADC bias - see rev 3 note below) Vadcpp  1.1-1.6 Vpp (0.5-2.0 V window = the ADC's LINEAR region) THD at 2400 Hz < 5 % - read the PARTIAL figure, in band (expect 2-4 %, dominated by the CE stage's re modulation; if it fails, RE4A 150 -> 220)

Vcedc ~ 2.0-2.3 V  (gain stage, must stay >1.1 V for the negative peak) Vindc ~ 0.31 V     (detector pedestal undisturbed)

REV 2 - BACK TO 5 V. Only V2 changes: the DC-coupled ladder is anchored to the detector pedestal through junction drops and never sees the rail. RE4B stays 2.7k (not the old .cir's 3.3k): re modulation dominates the THD and falls with bias current, and Q4 still has 1.3 V of down-room for a 0.76 V swing. Expect the ladder within ~10 mV of the 6 V run, Vadcavg still 1.65 V (it comes from the ESP32's 3.3 V, not from VCC), and THD near 3.5-4.5 %.

REV 3 - THE ESP32 MODULE INTERFACE, and a re-characterization. Decision: the receiver feeds an ESP32 dev MODULE (USB, easy to program and procure), not a bare chip. Three consequences, all handled here. (1) ADC SOURCE IMPEDANCE. The old 47k/47k divider presented 23.5k. The ESP32 SAR ADC wants <10k: with 23.5k and CADC 470p the pin charges with tau = 11 us against a 22.7 us sample period - two time constants, i.e. a sample-dependent error landing straight on picture brightness. (2) ADC LINEARITY. On 1.65 V the old 1.5 Vpp swung to 2.4 V, hard against the ESP32 ADC nonlinear region above ~2.45 V. New divider 10k / 6.2k puts the pedestal at 1.26 V and the swing at 0.6-1.9 V - inside the linear part. Source impedance drops to 3.83k, and supply rejection at the ADC improves from 70 % to 28 % because the collector now works into a lower load. CADC 470p -> 2.2n: a bigger charge reservoir for the SAR, and a 26 kHz pole. (3) SUPPLY NOISE. The module 5 V pin is USB VBUS - laptop SMPS noise plus the ESP32 own 250-500 mA WiFi bursts through cable resistance, i.e. tens to hundreds of mV, with content in the audio band. This block has poor PSRR by construction (ripple reaches the collector through RC4), so it now gets its own rail: RSUP 100 + CSUP 100u = a 16 Hz corner, -43 dB at 2400 Hz, for 0.11 V of drop at the 1.1 mA this chain draws. On the PCB put 100n in parallel with CSUP (an electrolytic alone is useless above ~100 kHz), and keep WiFi off during a pass - record first, transmit afterwards. ALSO REV 3: the drive is now the level SIM 13 actually MEASURED at the detector with the real limiter driving it - 120 mVpp on a 0.31 V pedestal, not the 60 mVpp / 0.23 V that SIM 1 predicted from an idealized source. The real limiter drives the detector tank harder and the S-curve slope grows with drive. Gain therefore falls from ~28 to ~11, which is the point: the 2x overdrive found in SIM 13 is absorbed by the same divider change.

REV 3b - Q4 OPERATING POINT, after the rev 3 run measured 7.5 % THD. Root cause, from the numbers: with 120 mVpp in and re = 86 ohm against 150 ohm of degeneration, v_be swung +/-22 mV against a 25.8 mV V_T - the emitter current was modulated +/-85 %, so re itself swung 47..577 ohm. H2 7.46 % vs H3 0.78 % confirms re modulation, not clipping. WHAT IT ACTUALLY COSTS: the picture lives in the ENVELOPE of the 2400 Hz subcarrier, and H2 at 4800 Hz is outside the envelope band. The metric that matters is gain compression: 10.17 small-signal vs 9.83 large-signal = 3.3 % at full white, which the APT calibration wedge corrects anyway. So rev 3 was usable - but the operating point had become tight (V_CE fell to 0.46 V on negative peaks), so two resistors buy margin AND linearity: RC4 10k -> 3.3k and RE4B 2.7k -> 820. Q4 current rises 0.30 -> 0.81 mA, re falls 86 -> 32 ohm, v_be swing halves to +/-11 mV (0.43 of V_T), the collector sits at 2.2 V and V_CE bottoms at 0.83 V instead of 0.46. Gain is deliberately unchanged (~9.7, ~1.17 Vpp out) - this buys linearity and headroom, not level. Cost: 0.5 mA and 0.06 V more drop across RSUP.

## sim3_if_filter.asc

*Now: SIM 3 - IF filter at 12.9 MHz. Explained in fm_receiver/DESIGN_LOG.md, section 'SIM 3 - the IF filter'.*

SIM 3 - IF filter, 12.9 MHz double-tuned with MAGNETIC coupling. The two tanks share NO galvanic path - the only link is the K statement. That is deliberate: SIM 5 proved capacitive top-coupling has a trap (the coupling cap resonates in series with the below-resonance, inductive-looking second tank and peaks the transfer exactly where rejection was wanted).

DESIGN MATH. Target: 12.9 MHz centre, ~200 kHz -3 dB bandwidth. That is far wider than the 43 kHz the APT signal occupies (Carson: 2*(17k dev + 4.4k audio)), on purpose - the extra room absorbs the Doppler baked into the recording (+/-3.5 kHz), crystal tolerance and alignment error, and a slope detector needs the whole FM spectrum undistorted. L = 2.2 uH -> Z0 = w0*L = 178 ohm; C = 1/(w0^2 L) = 69.2 pF. Coil Q_unloaded ~ 178 (toroid) = Rser 1 ohm -> its own parallel loss is Q*Z0 = 31.7k. With 33k of source/load in parallel, each tank ends up at Q_loaded ~ 91, and BW(-3dB) = sqrt(2)*f0/Q = 201 kHz. Critical coupling is k = 1/sqrt(Q1*Q2) = 1/91 = 0.011.

THE .step IS THE POINT: k = 0.005 (undercoupled - narrow, low transfer), 0.011 (critical - flat top, maximum transfer), 0.022 (overcoupled - two humps, wider with steeper skirts). Plot all three on one graph: this is the coupled-resonator behaviour, measured instead of taken on faith, and it tells us how touchy the coupling adjustment will be on the bench.

REAL BOM (this is a PCB, so nothing exotic): L1,L2  = 27 turns of 0.4 mm enamelled wire on a T37-6 toroid (AL = 3.0 nH/N^2). Toroids are SELF-SHIELDING - important with 75 dB of IF gain on one board. Leads go straight through two PCB holes. C1,C2  = 56 pF NP0 fixed + 5-30 pF trimmer (target 69.2 pF, aligned). RS     = the mixer drain's own output resistance (~33k for a dual-gate MOSFET); no physical part, it is what loads tank 1. RL     = the first IF stage TAPPED DOWN, not a resistor: a 2N3904-class stage at 2 mA has r_pi ~ 1.3k, so the base connects to a tap at ~20% of the turns. SUPERSEDED at integration (SIM 11): the real cascode input is ~6.1k, so the BUILD tap is 13/27 = 48% (the same 0.507u+0.588u coil as every SIM 4 tank). Tapping down is what keeps a low-impedance transistor from destroying the Q. k      = a link winding of ~3 turns on each toroid, the two links wired together (still no galvanic path between the tanks). Turns are trimmed at alignment: one peak = critical, two peaks = too many.

PASS: centre within ~50 kHz of 12.9 MHz and symmetric; BW at k=0.011 in the 150-250 kHz band; >= 20 dB down at +/-500 kHz and >= 30 dB at +/-1 MHz; the three k values reproduce the three coupling regimes. Record V129 for the gain budget - the insertion loss here is paid back by the IF amplifier. If the BW measurement errors out (it references Vpk), read the -3 dB points off the plot with the cursors instead - the FIND measurements stand alone.

## sim4a_if_gain.asc

*Now: SIM 4a - IF amplifier chain (rev 3: four cascode stages, 5 V). Explained in fm_receiver/DESIGN_LOG.md, section 'SIM 4 - the IF amplifier and limiter'.*

SIM 4a rev 3 - IF amplifier chain: FOUR cascode stages on a 5 V rail.

TWO CHANGES FROM REV 2, made together on purpose.

(1) 6 V -> 5 V. Honest history: 6 V was never an architectural choice, it was a repair. In SIM 5 the multiplier's collector swung 17.5 Vpp, past a real BFR93A's 12 V Vceo (a tuned collector swings ABOVE the supply - flywheel effect), so the rail came down to 6 V and then got copied everywhere without being reconsidered. 5 V is the better rail: it is what USB delivers and what the ESP32 already runs on, so the whole receiver takes one cable and no extra regulator. Nothing in this block wanted 6 V.

(2) A FOURTH stage, +23 dB. With the mixer measured at 22.7 dB (not the 12 dB originally assumed), the end-to-end budget becomes -2.2 +15.9 +22.7 -6.2 +93 = ~123 dB at design time (SUPERSEDED: SIM 11 measured the seam in situ; final budget 130 dB / -106 dBm) - i.e. what a QFH actually collects from a decent Meteor pass. That closes the 23 dB gap rev 2 documented. A second LNA stage was considered and REJECTED: it would drop the threshold to -115 dBm, below the ~-113 dBm noise floor, so the limiter would be fully driven by noise alone. Gain past the noise floor buys nothing and costs stability margin.

WHY THE BIAS DIVIDERS CHANGED. This is the block that made 5 V risky: a cascode stacks two Vce plus the tank swing. Keeping rev 2's dividers at 5 V would have left the LOWER transistor only ~0.69 V of Vce - too close to saturation to trust. Two changes fix it, both toward standard values: cascode bias 22k/18k -> 8.2k/10k: unloaded 2.75 V, and a stiffer divider (4.5k Thevenin instead of 9.9k) so the four upper base currents only pull it down 0.19 V -> vb2 = 2.56 V, upper emitter 1.84 V. base bias 47k/13k -> 33k/12k: at 5 V the old divider gave only 0.53 mA; this restores Ic ~1.04 mA, so gm_eff = 4.9 mS, slightly BETTER than rev 2. Result: lower Vce = 1.84 - 0.53 = 1.31 V, MORE headroom than the 6 V version had (1.24 V), and upper Vce = 3.14 V with +/-2.4 V of tank swing available against the ~1.5 V the limiter needs.

PASS: peak within ~100 kHz of 12.9 MHz; total gain (Gout - Vb1) 88-98 dB; -3 dB bandwidth 120-250 kHz (four cascaded tanks narrow it vs three - expect ~200 kHz, still 3x what the signal needs); the four stage gains within a few dB of each other; and Vb1 BELOW 0 dB - the regeneration tell-tale that condemned rev 1 and that the cascode fixed.

STABILITY WARNING, louder than before: 93 dB at one frequency on one board is a lot. The cascode removes the in-device feedback path, but layout, shielding and supply decoupling now decide the outcome, and no simulation can tell you about those. Plan on a shielded compartment for the IF strip with filtered supply feed-through - the classic construction, and at this gain not optional.

## sim4b_if_limiting.asc

*Now: SIM 4b - IF chain + limiter (rev 3). Explained in fm_receiver/DESIGN_LOG.md, section 'SIM 4 - the IF amplifier and limiter'.*

SIM 4b rev 3 - four cascode stages on 5 V: DOES IT STILL LIMIT? (.tran)

Same circuit as SIM 4a rev 3. Limiting is a large-signal effect - an .ac run cannot show it. A limiter's whole job is to make the OUTPUT AMPLITUDE INDEPENDENT OF THE INPUT LEVEL, so the slope detector converts frequency only and fading or AM noise is thrown away instead of becoming picture content.

THE STEP LIST MOVED DOWN BY 26 dB. Rev 2 (3 stages, 70.5 dB) needed ~400 uV to reach the diodes; rev 3 (4 stages, 95.8 dB) needs only ~22 uV. That 26 dB IS the whole point of the fourth stage - it is what moves full limiter drive from -77 dBm to -102 dBm on paper (-106 dBm with the SIM 11 measured seam) at the antenna, i.e. from "bench playback only" to "what a QFH actually collects from a Meteor pass".

Expected: 1 uV -> ~0.05 V (linear), 5 uV -> ~0.27 V (linear), 30 uV -> ~1.2 V (limiting), 300 uV -> ~1.2 V (hard limiting, early stages saturating too). THE LAST TWO BEING NEARLY EQUAL IS THE PASS CRITERION: 20 dB of input change must produce about 1 dB of output change.

The run starts from the DC operating point (no uic), so the 100 nF bypasses and 1 nF couplers are pre-charged and only the RF settles - four tanks of Q ~ 34, tau = Q/(pi.f) ~ 0.84 us each. Two spaced measurement windows PROVE settling rather than assuming it (the SIM 5b rule). NOTE: .tran must start at Tstart = 0 - a non-zero Tstart makes every .meas silently FAIL in LTspice, which cost one full debugging round earlier in this project.

PASS: Voutpp at 30 uV and 300 uV within ~1 dB and >= 2 Vpp; Voutpp_mid == Voutpp; Vc1pp scaling perfectly linearly with the input (limiting belongs at the END of the chain, not the start); the four emitter DC voltages steady across the range - one that walks under overdrive is rectifying, not amplifying; and Vc1adc ~1.85 V, unmoved, which is the cascode holding its job - that node standing still is exactly why there is no Miller feedback.

## sim5_multiplier_x5.asc

*Now: SIM 5 - x5 frequency multiplier (rev 4, 5 V). Explained in fm_receiver/DESIGN_LOG.md, section 'SIM 5 - x5 frequency multiplier (the LO chain)'.*

SIM 5 rev3 - class-C x5 multiplier with MAGNETICALLY coupled double-tuned output. REV3: rev2's capacitive top-coupling barely helped H4 (-18.3 dB): the series coupling cap + the below-resonance (inductive) second tank form a spurious series resonance near ~117 MHz that peaks the transfer right where H4 needs rejection - a classic double-tuned-circuit trap. Fix: transformer coupling (K1 L1 L2 0.03, near-critical k = 1/sqrt(Q1*Q2)), no galvanic path - on the bench this is a link winding / two adjacent coils, exactly like a vintage IF transformer. RP2 raised to 6.8k (Q2~58) for margin on H6, the spur that would convert 137.1 MHz straight onto the IF. PASS: H5 >= 200 mV on V(lo); H4 <= -35 dB (got -36.7; the 40 dB paper target is waived - system-covered by the front BPF, see README), H6 <= -38 dB vs H5; Vt1pp < 12 V. Netlist check: Q1 tank1 base 0 QRF, K1 L1 L2 0.03 present, and tank2 (L2/CT2/RP2 on node lo) has NO wire to tank1 - the only link is the K (mutual inductance) statement.

REV 4 - THE 5 V RAIL. No bias divider here (self-bias), so the only change is V2. The rail cuts BOTH headroom edges: the flywheel top peak moves 1 V further from the 12 V Vceo (good), but the bottom of the swing moves 1 V closer to SATURATION - a class-C collector that touches saturation clips the tank and reshuffles the harmonic balance H5 lives on. Hence the new Vt1min measurement: it must stay well above ~0.5 V at nominal drive. The settled verdict comes from SIM 5b; this file is topology/spurs.

## sim5b_multiplier_drive.asc

*Now: SIM 5b - multiplier drive robustness (rev 3, 5 V). Explained in fm_receiver/DESIGN_LOG.md, section 'SIM 5b - multiplier drive robustness'.*

SIM 5b - drive-robustness check of the class-C x5 multiplier (SIM 5 rev3 circuit, unchanged) driven the way the real buffer drives it: RSRC = 330 ohm source impedance (the rev-2 buffer's collector resistor) instead of an ideal 0-ohm source, and the amplitude stepped 0.65 / 0.75 / 0.95 / 1.15 V around the buffer's measured 2.33 Vpp (A = 1.15 ~ nominal, 0.95 ~ the -20 %

corner). A class-C base is not a polite load - it draws

current pulses on the positive peaks only, and every pulse through 330 ohms bites into the peak exactly when it matters. Vdrvpp measures the actual (sagged) drive after RSRC. REV2: rev1 measured at 4 us and caught the self-bias mid-charge (tau ~ CC*RB = 10 us): the LO was still drifting 10-12% between windows - and it exposed that SIM 5's own 2 us figure (H5 = 4.65 V) was itself measured mid-transient. Rev1's real finding: H5 collapses 8x between A = 0.95 and A = 0.75 - a conduction cliff (self-bias keeps the base at the edge of conduction; the resistive sag itself is a mild 4-8%). Rev2 runs 40 us = 4 tau (settled) and adds A = 0.65 to map the knee. PASS (rev2): Vlopp_mid (20-25 us) == Vlopp (35-40 us) within ~2%, i.e. settled; then judge the H5-vs-drive curve: the operating point must not sit on the cliff - if it does, the fix is more buffer drive and/or softer self-bias (smaller RB), decided from the curve, not guessed. Netlist check: RSRC between nodes in and drv, V1 = SINE(0 {A} 25Meg), the

REV 3 - THE 5 V RAIL. No divider to recompute (self-bias), so V2 is the only electrical change - plus RSRC 270 -> 330, because the rev-2 buffer's actual collector resistor is 330 now (the 270 premise went stale; the curve stays comparable because it is read via the MEASURED Vdrvpp, not via A). The 5 V question is the BOTTOM of the collector swing: the flywheel top gains 1 V of Vceo margin, but the swing minimum drops 1 V toward saturation, and a saturating class-C collector clips the tank and reshuffles the harmonics H5 lives on. Hence Vt1min: at nominal drive it must stay well above ~0.5 V. PASS (rev3, 5 V): settled (mid == final <= 2%); nominal off the cliff; H5 at the -20% corner >= 3x (accepted: 3.4x = 1.02 V) the mixer's 0.3 V need; Vt1min > 0.5 V.

## sim6_xtal_oscillator.asc

*Now: SIM 6 - 25 MHz crystal oscillator (rev 2, 5 V). Explained in fm_receiver/DESIGN_LOG.md, section 'SIM 6 - 25 MHz crystal oscillator'.*

SIM 6 - 25 MHz Colpitts crystal oscillator (common collector, one transistor). The crystal is built from its EQUIVALENT CIRCUIT, visible on the schematic: LM = 2.0265 mH, CM = 20 fF, RSX = 15 ohm (series resonance exactly 25.000 MHz, Q ~ 21000) plus CP = 5p holder capacitance. The huge-L / tiny-C ratio IS the reason quartz is a frequency standard. LTspice's [Misc] xtal symbol is the same thing drawn prettier (a capacitor with Lser/Rser/Cpar). Feedback: C1/C2 capacitive divider (82p/180p) around the emitter follower; the crystal parallel-resonates with the ~61p effective load. Bias: 11k/10k, Ie ~ 3 mA.

REV 2 - THE 5 V RAIL (see the README's supply-rail section). One resistor: R1 15k -> 11k restores the base to 2.38 V so Ie stays at 2.8 mA - the old divider at 5 V would have dropped it 23%, and the limiting amplitude (which the whole LO chain's cliff margin hangs on) would have sagged with it.

STARTUP: simulators have no thermal noise, so a real oscillator sim can sit dead at its DC point forever. The .ic V(b)=0 line yanks the base at t=0 as a kick. Growth is SLOW because Q is huge - expect visible RF only after ~100-300 us and limiting near ~0.5-1 ms. The run takes minutes; that is the crystal's physics. PASS: Vpp_early clearly smaller than Vpp (growth); Vpp stable (limiting reached);

~2 Vpp drive - if the bare oscillator gives less, the next stage is a buffer.

## sim6b_osc_buffer.asc

*Now: SIM 6b - oscillator buffer / multiplier driver (rev 3, 5 V). Explained in fm_receiver/DESIGN_LOG.md, section 'SIM 6 - 25 MHz crystal oscillator' (SIM 6b part).*

SIM 6b - crystal oscillator (SIM 6, unchanged) + buffer/driver stage. The bare oscillator limits at 410 mVpp - deliberately gentle (real crystals carry a max drive-level rating, ~0.1-0.5 mW; overdriving ages them), but the class-C x5 multiplier (SIM 5) was characterized with ~2 Vpp of drive. REV2 (after SIM 5b): the settled drive-vs-H5 curve showed 1.9 Vpp parks the multiplier on its conduction cliff (-18% drive = -7x LO). Fix read off the curve: move the operating point one notch up. RC 270->330 (gain ~6, so 0.41 Vpp -> ~2.3 Vpp) and RE2 100->68 (Ic ~4.1->~5 mA, so the positive peak clears cutoff). Worst -20% corner then lands on the MEASURED 1.76 Vpp point of the curve: H5 = 1.18 V, still 4x what the mixer needs. The 47R unbypassed emitter resistor still sets the gain by feedback; RE2 is bypassed by CE2. The load CC2/RB2 replicates the multiplier's real input network (1n + 10k self-bias), so Vpp_buf is measured into the load it will actually drive. The buffer also ISOLATES the crystal: its ~2.2k input impedance barely touches the osc node (impedance there is tens of ohms), and the multiplier's nonlinear base-current pulses now land on RC, not on the crystal loop. maxstep is 1 ns here (40 pts/cycle) vs SIM 6's 2 ns - comparing Vpp_osc with the earlier 410.6 mVpp doubles as a free convergence check (standing rule: never trust a single timestep). PASS (rev3, 5 V): Vpp_buf ~ 2.2-2.4 Vpp, stable (mid == final window); 25 MHz dominant in .four V(drv) with H2 no worse than rev1 (~-10 dB, else the peak is clipping); Vpp_osc unchanged vs SIM 6; Vbufc_dc ~ 3.2-3.6 V.

REV 3 - THE 5 V RAIL (see the README's supply-rail section). Two resistors, both dividers recomputed to hold the operating points: R1 15k -> 11k keeps the oscillator's Ie at 2.8 mA, and R3 15k -> 12k keeps the buffer's Ic at ~4.9 mA. The buffer one is NOT cosmetic: at 5 V the old divider would give Ic = 3.4 mA, but the positive peak of 2.35 Vpp into the 330||10k load needs 3.7 mA - the stage would clip through cutoff, exactly the defect rev 2 fixed. Headroom at 5 V is fine: collector at ~3.4 V swinging +/-1.2 V stays between 2.2 and 4.6 V, far from both rails.

## sim7_input_bpf.asc

*Now: SIM 7 - input band-pass filter, 50 ohm in and out (rev 2, Sept 2026). Explained in fm_receiver/DESIGN_LOG.md, section 'SIM 7 - the input filter'.*

SIM 7 - input band-pass filter, 137.9 MHz, 50 ohm in and 50 ohm out.

WHAT IT IS FOR. Two jobs, and only one of them is obvious. The obvious one: keep strong out-of-band transmitters out of the LNA - FM broadcast sits at 88-108 MHz and airband at 118-137, both far stronger than a satellite. The one that decides the frequency plan: IMAGE REJECTION. With LO = 125 MHz and IF = 12.9 MHz, the mixer converts BOTH 125+12.9 = 137.9 (wanted) and 125-12.9 = 112.1 (the image) onto the same IF. Nothing downstream can tell them apart afterwards - whatever arrives at 112.1 MHz is inside the receiver forever. This filter is the ONLY defence, which is why 112.1 MHz was chosen to land in the quiet gap between FM broadcast (ends 108) and airband (starts 118) - see the frequency plan in the README.

DESIGN MATH. L = 82 nH -> Z0 = w0*L = 71 ohm at 137.9 MHz; the tank needs 16.24 pF total. That total is split on purpose: 7.15 pF comes from a CAPACITIVE DIVIDER (8.2 pF in series with 56 pF) and ~8.7 pF from a trimmer (~6.7 on the board). The divider does double duty - it is part of the tuning AND it is the impedance transformer: the 50 ohm port sits at the junction, where the tap ratio is 8.2/64.2 = 0.128, so 50 ohm appears across the tank as 50/0.128^2 = 3.05 k (rev 1 had 15p/100p, ratio 0.130, 2.94 k). (A tapped COIL would need a tap at 13% of five turns - i.e. 0.65 of a turn, which does not exist. Capacitors divide continuously, so at VHF the divider replaces the tap. Same idea as SIM 3 and SIM 4, different hardware.)

With coil Q_unloaded ~ 150 (air core, Rser = 0.47) contributing 10.6 k, each tank ends up at Rp = 2.94k || 10.6k = 2.30 k, so Q_loaded = 32 and the coupled-PAIR bandwidth ~6 MHz (sqrt2*f0/Q; measured 6.0). Enormous next to the 43 kHz the signal occupies - deliberately: this filter is not there to be selective, it is there to reject a band 26 MHz away. A narrow front end would only add loss where loss costs noise figure directly, and would need retuning to move anywhere else in the 137-138 MHz satellite band. Critical coupling for Q = 32 is k = 1/Q = 0.031.

MAGNETIC coupling again, no galvanic path between the tanks - the SIM 5 lesson. The .step through k = 0.015 / 0.031 / 0.062 shows under-, critical and over-coupling, exactly as in SIM 3. A prediction written here before the run - that overcoupling would buy image rejection for free through steeper skirts - turned out WRONG: measured rejection at 112.1 MHz was 42.0 dB undercoupled, 37.6 dB critical, 31.6 dB overcoupled. Far from centre the attenuation is set by LOADED Q, not by skirt shape; overcoupling widens the response, which is the same as lowering the effective Q, so the whole curve moves outward. The skirts really are steeper - they just start further out. CHOSEN: critical coupling. Undercoupling buys 4.4 dB more rejection but costs 1.9 dB more insertion loss, and loss ahead of the LNA goes straight into the noise figure. 37.6 dB is already past the 30 dB target.

REAL BOM: L1, L2 = ~5 turns of 0.8 mm enamelled copper wound on a 5 mm former, air core, then squeezed or spread to trim (that is how you tune a VHF coil). Mount them about one coil diameter apart and with axes aligned; that spacing is what sets k ~ 0.03, and it is adjustable by sliding them. Ct1, Ct2 = 3-10 pF trimmer (Murata TZC3; ~8.7 pF here, ~6.7 pF on the board where the layout adds ~8.6 nH + 0.5 pF). C1a/C2a = 8.2 pF NP0, C1b/C2b = 56 pF NP0 - same 0.128 tap ratio as the 15p/100p of rev 1 (Sept 2026, README SIM 7 rev 2).

THIS ONE YOU CAN MEASURE. It is 50 ohm in and 50 ohm out, which is exactly what a miniVNA presents. Build it, sweep it, and compare the trace with this simulation directly - the first block of the receiver that can be verified on the bench with instruments you already own, instead of taken on trust.

PASS: centre within ~2 MHz of 137.9; IMAGE at 112.1 MHz down >= 30 dB from centre; 137.1 MHz (the other Meteor) within ~1 dB of centre; FM broadcast (108) and airband (118) well down; insertion loss at centre small enough that it does not eat the noise figure - record V1379 for the budget.

## sim8_mixer.asc

*Now: SIM 8 - mixer (rev 2, 5 V). Explained in fm_receiver/DESIGN_LOG.md, section 'SIM 8 - the mixer'.*

SIM 8 - the mixer: a single-balanced SWITCHING mixer (half a Gilbert cell, i.e. the top half of the classic SA602), built from three of the same QRF transistors validated in six other simulations.

WHY NOT A BF998 MODEL. The plan called for a dual-gate MOSFET, but LTspice has no BF998 model, and writing one by hand would make the simulation confirm whatever number was typed into it. A switching mixer's conversion gain comes from STRUCTURE instead: chopping the signal current with the LO multiplies it by a square wave whose fundamental is (4/pi)*0.5, so conv gm = gm_eff/pi,  Av_conv = gm_eff*Rp/pi with gm_eff = 1/(re+100) = 8.7 mS and Rp = 6.8k: ~19x = ~25 dB. A formula checkable against the run, not a datasheet act of faith. On the PCB either build it as drawn (3 transistors) or drop in a BF998 - RF, LO and IF interfaces are the same.

HOW IT WORKS. Q1 is a degenerated common-emitter transconductor: RF voltage in, RF current out of its collector (100R unbypassed keeps it linear and predictable, same philosophy as every stage in this receiver). Q2/Q3 sit on top as a differential SWITCH: the LO on Q2's base (Q3's base is the same DC bias, AC-grounded through Cb2) steers Q1's current left-right 125 million times a second. The signal current arrives at the IF tank chopped by the LO - and chopping IS multiplication: 137.9 x 125 -> 12.9 (+262.9, killed by the tank). Q3's collector goes straight to VCC: that half of the current is thrown away (the -3 dB a single-balanced design accepts for simplicity).

THE TANK stands in for SIM 3's first filter resonator: 2.2u + 69.2p at 12.9 MHz, damped to Rp 6.8k (loaded Q ~30, settles in ~0.7 us). The switch collector looks like tens of k - consistent with the 33k source SIM 3 assumed for the real filter.

THE DOUBLE .step ANSWERS TWO QUESTIONS IN ONE RUN (8 combinations): (1) ALO 0.1..0.8 V maps conversion gain vs LO drive. Expect a rise, then a PLATEAU once switching is complete (~0.2-0.3 V) - the SIM 5b lesson: park the operating point on the flat part, not on a cliff. Our LO chain delivers 1.68 V nominal on 5 V (1.02 V at the -20% corner), tapped to ~0.39 V on the board. (2) FRF 137.9 vs 112.1 MHz is the IMAGE demonstration: both are 12.9 MHz away from the 125 MHz LO, so both convert onto the IF with nearly EQUAL gain. The mixer cannot tell them apart, no mixer can - which is the entire reason SIM 7's front filter exists and why its 37.6 dB is the receiver's whole image defence.

BIAS (5 V rail): Q1 base 1.33 V (33k/12k), Ie ~1.7 mA through 100+220 (220 bypassed by 10n - low X at 137.9 AND 12.9 MHz); pair bases at 2.5 V (15k/15k, bypassed), so e23 sits near 1.8 V and Q1 keeps ~1.2 V of Vce. RLO 10k isolates the LO injection from the bypassed bias node.

PASS: conversion gain (from .four: fundamental amplitude / 5 mV) reaching ~19x = 25 dB and FLAT for ALO >= 0.4 (plateau, not cliff); image gain at 112.1 within ~1 dB of 137.9 (proves the point); Vifpp_mid == Vifpp (settled); Ve23dc ~1.8 V and steady across ALO (bias not rectifying).

REV 2 - THE 5 V RAIL. The 6 V figure was never a design decision (see the README); the whole receiver now runs from 5 V. In a STACKED stage the rail change cannot just be typed into V2: both dividers are ratios of VCC, so at 5 V the old values would drop Q1's base to 1.08 V (Ie down ~35%, conversion gain down ~2 dB) and the pair bases to 2.1 V (Q1's Vce squeezed under 0.9 V, flirting with saturation on LO downswings). Fix: recompute the dividers to hold the OPERATING POINT, not the resistor values - RB 47k/13k -> 33k/12k (1.33 V, the same pair used by every IF stage in SIM 4) and RT 18k/13k -> 15k/15k (2.5 V exactly). Same currents, same gm, same Vce as before.

## sim9_lna.asc

*Now: SIM 9 - LNA (rev 2, 5 V). Explained in fm_receiver/DESIGN_LOG.md, section 'SIM 9 - the LNA'.*

SIM 9 - LNA, 137.9 MHz, an EMRFD-style FEEDBACK AMPLIFIER: 50 ohm in and out.

WHY THIS TOPOLOGY AND NOT ANOTHER TUNED STAGE. Two reasons. (1) The SIM 7 filter was designed AND will be aligned against 50 ohm terminations - so whatever follows it must actually present 50 ohm, or the filter's response (and its image rejection) warps. This amplifier's input impedance is set by RESISTOR feedback, not by transistor parasitics, so it holds near 50 ohm across the band and from part to part. (2) Stability by construction: SIM 4 showed what parasitic feedback does to tuned gain stages. Here the deliberate NEGATIVE feedback through Rf swamps the parasitic path - the classic homebrew building block from EMRFD (Hayward/Campbell/Larkin), used by the dozen in every design in that book.

HOW IT WORKS. Two feedbacks set everything: Rf = 470 (collector to base, through Cf so it carries only RF, the DC bias staying independent) and RE1 = 2.2 unbypassed in the emitter. Gain ~ sqrt-of-neither: with the 120 ohm collector load and 50 ohm output termination, Av ~ 33/5 ~ 6.6, and the shunt feedback makes Zin ~ Rf/(1+Av) ~ 63 ohm, trimmed toward 50 by the bias divider's ~347 ohm (910||560) across the input. Expected S21 ~ 16-17 dB into 50 ohm (a couple more into the mixer's high-Z gate).

BIAS (5 V rail): Ie ~ 21 mA (LNAs run hot - large-signal handling for the FM broadcast leftovers that make it past the filter). Divider 910/560 -> Vb 1.83 V loaded, Ve 1.03 V across RE1+RE2 = 49.2 ohm, collector at ~2.5 V (check the DC op point: hover the collector node - it should read ~2.4-2.6 V).

MEASUREMENTS. G1379 is the 137.9 MHz transfer; S21 = G1379 + 6.02 dB (the AC-1 source behind 50 ohm delivers 0.5 V to a matched load, so 0 dB gain reads as -6 dB here). Vb1379 is the INPUT MATCH gauge: exactly 0.5 means a perfect 50 ohm input; 0.42-0.58 keeps VSWR under ~1.5:1, good enough for the filter. Zin = 50*Vb/(1-Vb) if you want the number itself. G20/G300/G700 map the frequency response: a feedback amplifier should be broadband and MONOTONIC - Gpk noticeably above G1379 would mean peaking somewhere, i.e. a resonance that has no business existing in this circuit.

NOISE, honestly: a feedback amp is not the lowest-noise topology (~4-5 dB NF), and LTspice NF numbers would not be trusted anyway (see README). At 137 MHz the galactic background (>1000 K) exceeds the receiver's own noise, and the bench goal - decoding a REPLAYED recording through attenuators - does not depend on NF at all. Match, gain, stability: those it delivers.

REAL BOM: all E24 (470/120/2.2/47/910/560), Q = BFR93A, caps 1n + 100n NP0/X7R. 50 ohm in/out = the second block directly measurable with the miniVNA, sweep against this plot after building.

PASS: S21 15-18 dB at 137.9 (G1379 between 9 and 12 dB); Vb1379 0.42-0.58; response monotonic, Gpk within ~1 dB of the low-frequency plateau; smooth rolloff at 300/700 MHz with no resurgence.

REV 2 - THE 5 V RAIL (see the README's supply-rail section). One resistor: RB1 1.2k -> 910, restoring Vb to 1.90 V so Ie stays at 21 mA - the old divider at 5 V would have dropped it to ~15 mA, costing ~1 dB of S21 and, worse, shifting the 50 ohm input match the SIM 7 filter depends on. The price of 5 V is headroom: collector at 2.5 V, V_CE 1.47 V (was 2.5 V). That is >300x margin over the worst signal this stage ever sees (strong local FM broadcast after the filter's -40 dB: ~4 mVpp at the output), and 31 mW of dissipation - cool for a BFR93A. Compression drops but stays tens of dB above anything the front end can deliver.

## sim10_limiter_detector.asc

*Now: SIM 10 - integration: limiter into detector. Explained in fm_receiver/DESIGN_LOG.md, section 'Integration: SIM 10, 11, 12 - where the standalone testbenches lied'.*

SIM 10 - INTEGRATION: the real limiter driving the real slope detector. SIM 1 characterized the detector from an ideal sine behind an abstract 33k. The real source is SIM 4's limiter: a hard-clipped +/-1.2 V waveform behind the diode clamp (low impedance while clipping) in parallel with Rout 100k. INTERFACE DECISION UNDER TEST: RS 33k becomes a PHYSICAL series resistor between limiter and tank. Then the source impedance the tank sees is 33k + (clamp || 100k || 10k) ~ 33.2k - i.e. SIM 1's characterization holds by construction, and the S-curve centre should NOT move. THE DRIVE REPLICA: SINE 4 V behind RDRV 10k (stage 4's tank damping) into the exact clamp from SIM 4 (DX diodes, Rout 100k) - deep overdrive, like a limiting IF chain delivers. The clipped wave carries harmonics of 12.9 MHz; H3 lands at 38.7 MHz, far outside the tank's Q~80 window - the tank itself is the harmonic filter, which is why slope detectors tolerate square drive. PASS: Vlimpp ~ 2.3-2.7 V (clamp clipping as in SIM 4b); S-curve (Vdet vs F) peak at 12.95 MHz +/- one 5 kHz step (centre unmoved => C1 66.7p alignment target survives integration); Vtank at the peak >= 0.5 V (detector driven at least as hard as in SIM 1); flank through 12.90 quasi-linear. If the peak DOES move, the bench trimmer absorbs it - this sim documents the corrected alignment target, which is exactly its job.

## sim11_mixer_filter_if.asc

*Now: SIM 11 - integration: mixer into IF filter into first IF stage. Explained in fm_receiver/DESIGN_LOG.md, section 'Integration: SIM 10, 11, 12 - where the standalone testbenches lied'.*

SIM 11 - INTEGRATION: mixer -> real double-tuned IF filter -> tapped tank 2 -> first cascode IF stage. Resolves two interface questions the standalone sims left open. (1) TANK 1 IS THE MIXER'S COLLECTOR LOAD. SIM 8's standalone Rp 6.8k was a testbench convenience (fast settling, defined load). Here the filter's first resonator (Ltank/Ctank, the same parts) hangs directly on Q2's collector, loaded only by coil loss and the mixer's own output resistance - loaded Q ~100+, so settling takes ~2.5 us and the run is 12 us with spaced windows. (2) THE TAP WAS RE-SIZED - a real integration catch. SIM 3's BOM note assumed the IF stage input is r_pi ~ 1.3k (bare 2N3904 at 2 mA) and put the tap at 20% of the turns. The REAL SIM 4 stage input is the 33k||12k divider in parallel with a DEGENERATED cascode base (r_pi + beta*180 ~ 20k): ~6.1k total. Through a 20% tap that reflects 152k - the filter would sit nearly unloaded, Q2 ~147, bandwidth ~124 kHz: too narrow, wrong shape. Fix: tap at 13/27 (48%), i.e. THE SAME 0.507u + 0.588u split every SIM 4 tank uses - one coil recipe for the whole IF strip. 6.1k / 0.481^2 = 26k across the tank, Q2 ~81, geometric-mean Q ~95, k crit ~ 0.011 - the 3-turn link and the ~200 kHz design bandwidth survive. Tank 2 cold end grounds; its two sections carry Rser 0.5 each (~1 ohm total, the same Q_U ~178 budget as SIM 3). Coupling: K2/K3 tie tank 1 to both sections of tank 2 at k = 0.011 (one physical link winding); K1 = 0.999 makes the two sections one tapped coil. Stage 1's own tap (tap1) is left unloaded here - its gain reads slightly high, documented, irrelevant to the filter question. The cascode bias divider 8.2k/10k feeds ONE upper base instead of four, so vb2 sits at ~2.70 V (vs 2.56 in SIM 4) and c1a lands near 1.9 V - expected, not a fault.

PASS: Vifpp_mid == Vifpp within ~3% (settled); Ve23dc ~1.78 V and Ve1bdc ~0.328 V (mixer bias untouched by the new load); Vc1adc ~1.9 V, Ves1dc ~0.34 V = Ie 1.04 mA x 330 (stage bias healthy); V(b1) fund. at FRF=138.4 (IF 13.4 MHz, +500 kHz) at least 20 dB below the 137.9 run (SIM 3 alone said -27.9 dB). Record the 137.9 V(b1) fundamental: it is the MEASURED mixer+filter interface gain that replaces the -6.2 dB paper figure in the budget. Gear integrator: hard-switching mixer, the SIM 8 lesson.

## sim12_full_receiver.asc

*Now: SIM 12 - the full receiver: design authority, the PCB is built from this netlist (4.6 V rail since Sept 2026). Explained in fm_receiver/DESIGN_LOG.md ('Integration' and 'The supply rail') and in pcb/README.md.*

SIM 12 - THE FULL RECEIVER. Master schematic, assembled PROGRAMMATICALLY from the verified block files (each band is a pure vertical translation of its source; test sources removed; blocks joined by net labels, never wires). BAND MAP (dy): 0=sim7 BPF | +800=sim9 LNA | +1600=sim11 mixer+IF filter+IF1 | +2400=sim4a IF stages 2-4 + limiter + vb2 divider + V2 | +3300=sim10 detector | +4100=sim2b audio | +4900=sim6b xtal osc + buffer | +5700=sim5 x5. SEAMS (net labels): ant>BPF; n_rf1 BPF>LNA; n_rf2 LNA>mixer RF; n_lo x5-tank tap>mixer LO port; n_t1 IF1 tap>Cc1>IF2 base; out limiter>RS 33k>detector; audio detector>audio chain; bufc buffer>multiplier; vb2 = shared cascode bias, 8.2k/10k feeding FOUR upper bases (the SIM 4 design point); vcc/0. LO TAP (new here, from SIM 5b rev 3): the x5 output tank cap splits 14p (hot to tap) + 47p (tap to gnd): series 10.79p keeps 125 MHz, ratio 14/61 = 0.23 -> 1.68 V x 0.23 ~ 0.39 V at the mixer = its measured plateau point. Real BOM: 12p + 1-10p trimmer on top, 47p NP0 bottom. AUDIO SUPPLY (rev 3): the audio block hangs on net vaud behind RSUP 100 + CSUP 100u - a 16 Hz corner, -43 dB at 2400 Hz. That is not cosmetic: this receiver is powered from an ESP32 module 5 V pin (USB VBUS), and the module own 250-500 mA WiFi bursts would otherwise reach the ADC through RC4. RUN .op FIRST. Expected DC: vcc 5.000; LNA ln_b 1.82 / ln_c 2.58 / ln_e 1.01; mixer brf 1.20, e1b 0.328, e23 ~1.68 STATIC (no LO at .op), if ~5.0; IF strip b1..b4 1.243, c1a..c4a 1.855, es1/e2b/e3b/e4b 0.341, e2/e3/e4 0.527, taps and collectors ~5.0; limiter out 0.00; detector dtank 0, audio 0 - NO CARRIER AT DC, so the audio ladder sits ~0.31 V below its operating values; adc ~1.26 (from the ESP32 3.3 V through RD1/RD2, immune to VCC), adcref 3.30; oscillator o_b ~2.24, osc ~1.50, bufc ~3.42; multiplier DEAD at DC (class C with no drive): xbase ~0, xtank1 ~5.0, lo/n_lo 0. Total draw 41.6 mA measured (~208 mW). FOR TRANSIENT RUNS a full-chain tran is impractical (2400 Hz audio needs 400 us; 137.9 MHz needs 0.1 ns steps; the crystal needs ~1 ms to start). Substitute the crystal with SINE(0 0.205 25Meg) - the measured 410 mVpp - and run sub-chains; SIM 13 does exactly that for the IF-to-ADC half. NET-NAME NOTE: LTspice canonicalises each net to ONE name, so two seam labels are shadowed - the BPF>LNA node reads tapB (not n_rf1) and the IF1>IF2 node reads b2 (not n_t1). Connectivity is correct (see the generated

VERIFICATION: this file is checked with LTspice.exe -netlist and the netlist audited line by line - definitive, and it supersedes coordinate re-derivation. A wire spanning EXACTLY a part two pins is ABSORBED by the part, not a short.

## sim13_fm_endtoend.asc

*Now: SIM 13 - FM in, audio out (end to end). Explained in fm_receiver/DESIGN_LOG.md, section 'SIM 13 - the money shot: FM in, audio out'.*

SIM 13 - THE MONEY SHOT: a true APT-format FM signal in, audio out at the ADC. Source SFFM(0 A 12.9Meg 7.083 2400) = 12.9 MHz carrier, FM by 2400 Hz at +/-17 kHz deviation - exactly what NOAA APT puts on the IF after the mixer. Injected at the IF-chain input because FM survives frequency conversion untouched; the RF half (+20.6 dB) is already measured in SIM 11, and putting 137.9 MHz in a 2 ms run would need 0.1 ns steps = 4e9 points, impossible. Chain under test: 4 cascode IF stages -> limiter -> RS 33k -> slope detector -> full audio chain -> ADC node. 1 ns steps, 2 ms, two amplitude steps. THE POINT OF THE TWO STEPS: 100 uV and 1 mV are 20 dB apart, both far past the ~22 uV limiting threshold. If the receiver works, V(adc) reads the SAME 2400 Hz at the SAME amplitude in both - limiting has erased the AM, which is why FM survives fading and why this architecture exists at all. THE ACQUISITION TRANSIENT (found by rev 1, kept as a documented finding). Starting from the no-carrier DC point, the pedestal steps 0 -> 0.31 V; the audio gain stage 100 uF emitter bypass holds the old bias, the whole step lands on the emitter degeneration and the stage saturates for the entire window (rev 1 read V(adc) = -0.55 V) while everything upstream was perfect. That is REAL receiver behaviour - the first ~50-100 ms of audio after a carrier appears are garbage while CC1/CE4 find the new pedestal, irrelevant in a 10-minute pass. Here .ic V(audio)=0.31 presets the settled state. EXPECTED (audio chain at rev 3b): Voutpp ~2.3-2.5 V both steps (clamped); Vauddc ~0.31, Vaudiopp ~110-130 mVpp; Vadcpp ~1.1-1.3 Vpp EQUAL between the two steps within ~1 dB - that equality is the whole point; Vadcavg ~1.26.

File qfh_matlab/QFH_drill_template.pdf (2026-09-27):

# QFH mast drilling template - target 137.500 MHz

Layout inspired by the ON6JC/LW3HAZ QFH design tool by John Coppens - jcoppens.com/ant/qfh
Mast dia. 32.6 mm (circumference 102.5 mm) | support tube dia. 15.9 mm | wire dia. 1.78 mm | generated by qfh_matlab
1. Print at 100% / "Actual size" (never "fit to page"). Check: the calibration bar below must measure exactly 100.0 mm.
2. Draw a straight SEAM line along the mast. On it, mark the depth of every station (table below), measured from the antenna top plane (depth 0 = feed level).
3. Cut out each strip and wrap it around the mast, printed side out: 0-deg edge on the seam, station line(s) on the matching depth mark(s). The strip ends must meet on the seam.
4. WRAP DIRECTION MATTERS: seen from the TOP of the mast, angles must increase counter-clockwise. Wrapping the other way mirrors the antenna (LHCP instead of RHCP!).
5. SANITY CHECK after wrapping: deeper station lines must sit LOWER on the mast (large-loop middle below small-loop middle). If inverted, the strip is wrapped the wrong way.
6. Drill through the center of every circle: small circles = wire holes (dia. 1.78 mm), large circles = support-tube holes (dia. 15.9 mm).
7. Equal letters = same helix arm (A/B = small loop, C/D = large loop).

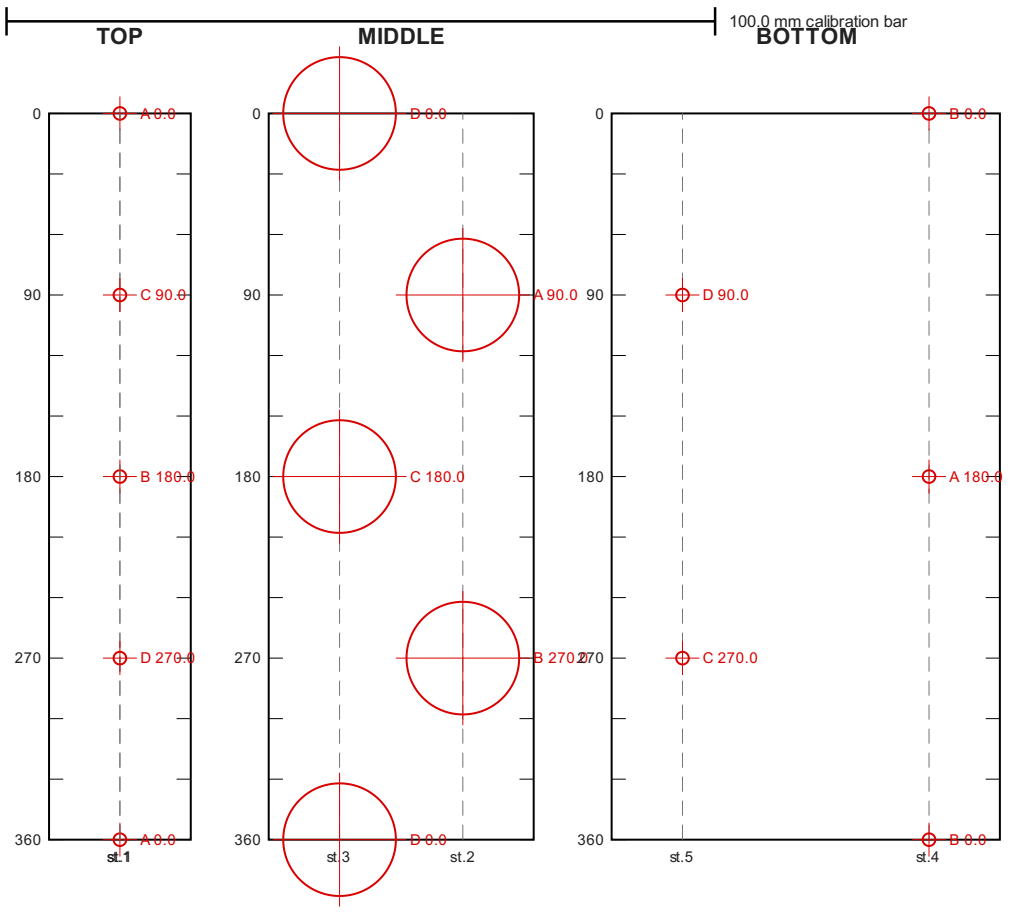
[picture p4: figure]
100.0 mm calibration bar TOP; MIDDLE; BOTTOM

st. loop | position | depth [mm] | hole dia. [mm] | angles [deg] | arms
1 | small | top | 0.0 | 1.78 | 0.0 / 180.0 | A / B
1 | large | top | 0.0 | 1.78 | 90.0 / 270.0 | C / D
2 | small | middle | 336.5 | 15.90 | 90.0 / 270.0 | A / B
3 | large | middle | 353.9 | 15.90 | 180.0 / | 0.0 | C / D
4 | small | bottom | 672.9 | 1.78 | 180.0 / | 0.0 | A / B
5 | large | bottom | 707.7 | 1.78 | 270.0 / 90.0 | C / D

Depths are to HOLE CENTERS, measured from the antenna top plane. Angles: 0 deg = seam line, increasing counter-clockwise seen from the top.

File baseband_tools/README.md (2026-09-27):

# baseband_tools — check the recording before you fight the decoder

Small base-MATLAB tools (no toolboxes) that came out of a hard lesson. When a
decoder says "no sync", it cannot tell you whether the signal is weak, the file
is broken, or the settings are wrong. These tools separate those cases in
minutes.

| Tool | What it does |
|---|---|
| `baseband_check.m` | health + signal check of a raw IQ recording (cs8/cs16/cf32): clipping, dead samples, quantisation vs dropout diagnosis, waterfall, in-band SNR vs time, Doppler signature |
| `signal_id.m` | identifies what a signal *is* without any decoder: occupied bandwidth, **symbol rate from the cyclostationary clock line** (|x|² spectrum), modulation hints from the x⁴ signature |
| `cut_segment.m` | cuts a time segment out of a recording for sharing (chunked, RAM-safe) |

What I learned in the field and built into these tools: on a Pluto, record
cs16, never cs8 (12-bit ADC + weak satellite signal + cs8 = 1.5 effective bits
and a dead file). Never record into a cloud-synced folder. Run `baseband_check`
right after every pass, before any decoding.

## Attribution

I (Edy Grigore) developed these tools iteratively with **Claude (Anthropic)**
as a coding/DSP assistant. All recordings, measurements and field debugging are
my own.

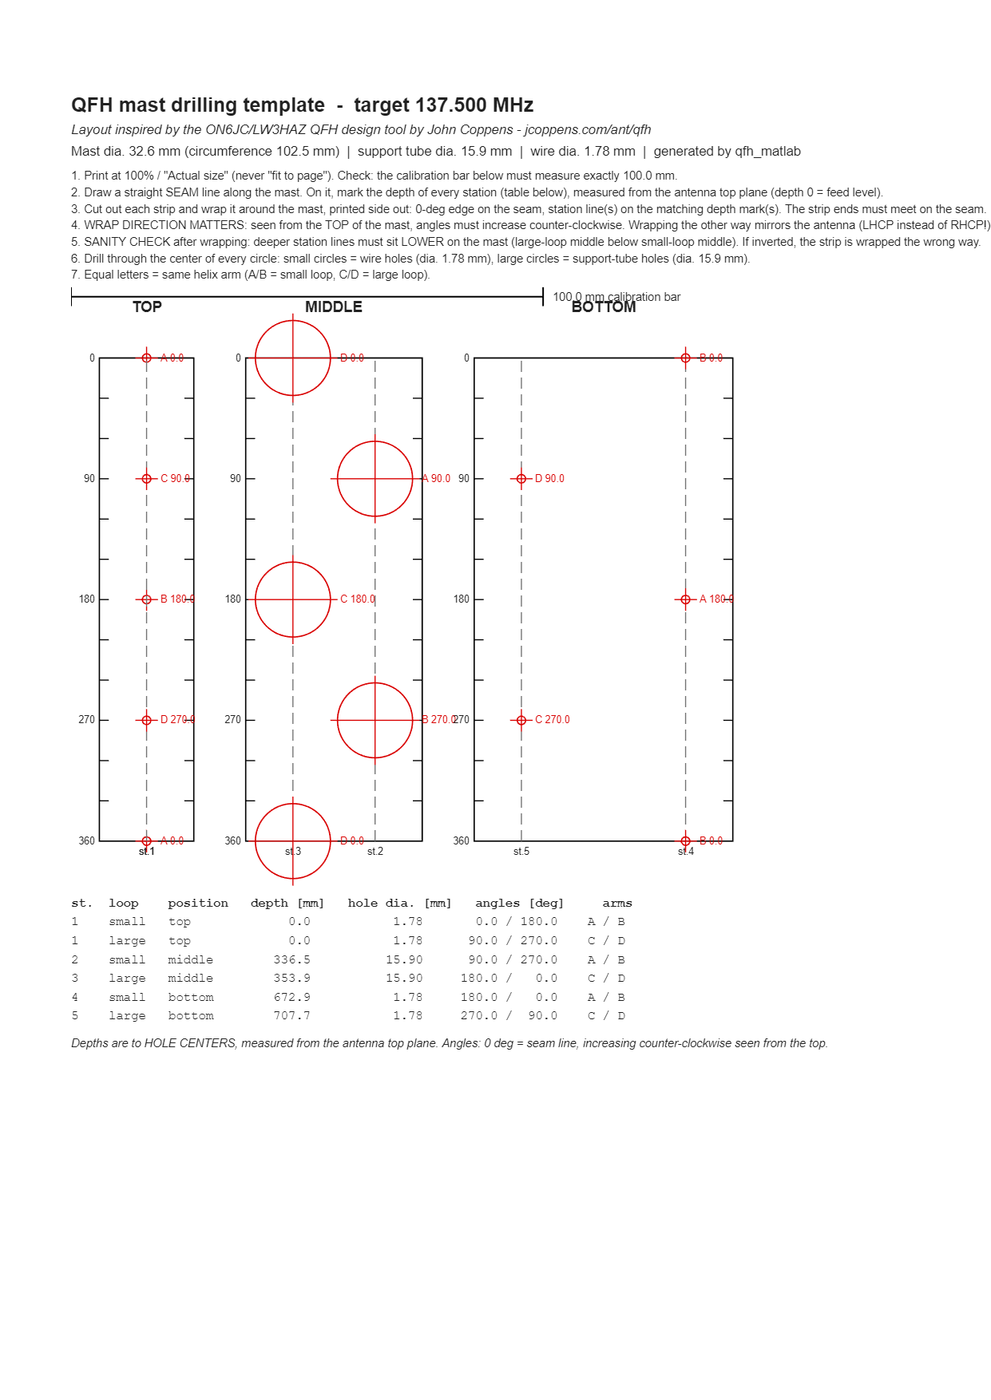
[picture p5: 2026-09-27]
qfh_matlab/QFH_drill_template_preview.png

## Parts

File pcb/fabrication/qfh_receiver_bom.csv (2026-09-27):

Refs | Value | Spec | Footprint | MPN | Farnell | Qty | DNP
C1,C5,C8,C10,C14,C16,C18,C24,C28 | 56p | NP0/C0G ceramic 0805, 50 V | Capacitor_SMD:C_0805_2012Metric |  |  | 9
C2,C6,C9,C11,C15,C17,C19 | 6.5-30p | Murata TZC3 film trimmer, top adjust | Capacitor_SMD:C_Trimmer_Murata_TZC3 | TZC3P300A110R00 | 2456139 | 7
C3 | 3.3p | NP0/C0G ceramic 0805, 50 V | Capacitor_SMD:C_0805_2012Metric |  |  | 1
C4,C7,C13,C20 | 3-10p | Murata TZC3 film trimmer, top adjust | Capacitor_SMD:C_Trimmer_Murata_TZC3 | TZC3R100A110R00 | 2456140RL | 4
C12 | 5.6p | NP0/C0G ceramic 0805, 50 V | Capacitor_SMD:C_0805_2012Metric |  |  | 1
C21 | 2.7n | X7R ceramic 0805, 50 V | Capacitor_SMD:C_0805_2012Metric |  |  | 1
C22 | 82p | NP0/C0G ceramic 0805, 50 V | Capacitor_SMD:C_0805_2012Metric |  |  | 1
C23,C27 | 8.2p | NP0/C0G ceramic 0805, 50 V | Capacitor_SMD:C_0805_2012Metric |  |  | 2
C25,C31 | 2.2n | X7R ceramic 0805, 50 V | Capacitor_SMD:C_0805_2012Metric |  |  | 2
C26 | 180p | NP0/C0G ceramic 0805, 50 V | Capacitor_SMD:C_0805_2012Metric |  |  | 1
C29 | 8.2n | X7R ceramic 0805, 50 V | Capacitor_SMD:C_0805_2012Metric |  |  | 1
C30 | 1.2n | X7R ceramic 0805, 50 V | Capacitor_SMD:C_0805_2012Metric |  |  | 1
C32,C33,C47 | 10n | X7R ceramic 0805, 50 V | Capacitor_SMD:C_0805_2012Metric |  |  | 3
C34,C36-C39,C48-C52,C54,C63,C64,C66-C82 | 100n | X7R ceramic 0805, 50 V | Capacitor_SMD:C_0805_2012Metric |  |  | 30
C35,C46 | 47p | NP0/C0G ceramic 0805, 50 V | Capacitor_SMD:C_0805_2012Metric |  |  | 2
C40,C42-C45,C55-C60,C65 | 1n | X7R ceramic 0805, 50 V | Capacitor_SMD:C_0805_2012Metric |  |  | 12
C41 | 1u | X7R ceramic 0805, 16 V or more | Capacitor_SMD:C_0805_2012Metric |  |  | 1
C53,C61 | 100u | electrolytic 10 V, radial D5 P2.5 | Capacitor_THT:CP_Radial_D5.0mm_P2.50mm |  |  | 2
C62 | 1000u | electrolytic 10 V low ESR, radial D8 P3.5 | Capacitor_THT:CP_Radial_D8.0mm_P3.50mm |  |  | 1
D1-D4 | 1N4148 | DO-35 | Diode_THT:D_DO-35_SOD27_P2.54mm_Vertical_AnodeUp |  |  | 4
D5 | 1N5711 | Schottky, DO-35 | Diode_THT:D_DO-35_SOD27_P2.54mm_Vertical_AnodeUp |  |  | 1
J1 | SMA antenna | Amphenol edge-launch SMA | Connector_Coaxial:SMA_Amphenol_132289_EdgeMount | 132289 | 2112467 | 1
J2 | SMA test (DNP) | Amphenol edge-launch SMA | Connector_Coaxial:SMA_Amphenol_132289_EdgeMount | 132289 | 2112467 | 1 | DNP
J3 | ESP32 row B | female header 1x19, 2.54 mm, 8.5 mm stand-off (socket for ESP32-DevKitC V4 38-pin) | Connector_PinSocket_2.54mm:PinSocket_1x19_P2.54mm_Vertical |  |  | 1
J4 | ESP32 row A | female header 1x19, 2.54 mm, 8.5 mm stand-off (socket for ESP32-DevKitC V4 38-pin) | Connector_PinSocket_2.54mm:PinSocket_1x19_P2.54mm_Vertical |  |  | 1
L1 | 2.2u tap13/27 | T37-6 toroid: 27 t 0.4 mm enamelled, tap at turn 13, plus 3 t link winding on pads 4/5; mount on edge | qfh_receiver:TOROID_T37-6_UNIVERSAL |  |  | 1
L2-L4 | 2.2u tap13/27 | T37-6 toroid: 27 t 0.4 mm enamelled, tap at turn 13; mount on edge | qfh_receiver:TOROID_T37-6_UNIVERSAL |  |  | 3
L5,L6 | 2.2u | T37-6 toroid: 27 t 0.4 mm enamelled; mount on edge | qfh_receiver:TOROID_T37-6_UNIVERSAL |  |  | 2
L7 | 2.2u | T37-6 toroid: 27 t 0.4 mm enamelled, plus 3 t link winding on pads 4/5; mount on edge | qfh_receiver:TOROID_T37-6_UNIVERSAL |  |  | 1
L8,L10 | 82n | air coil: 5 t 0.8 mm enamelled on a 5 mm former, one diameter from its pair | qfh_receiver:AIRCOIL_5MM |  |  | 2
L9,L11 | 150n | air coil: 7 t 0.8 mm enamelled on a 5 mm former, one diameter from its pair | qfh_receiver:AIRCOIL_5MM |  |  | 2
L12 | FB 600R@100MHz | ferrite bead 0805, 600 ohm at 100 MHz, >= 200 mA | Inductor_SMD:L_0805_2012Metric |  |  | 1
Q1-Q4,Q6,Q8,Q10-Q13,Q15-Q17,Q19,Q20 | BFR92P | Infineon SOT-23 (min 5, multiples of 5 at Farnell) | Package_TO_SOT_SMD:SOT-23 | BFR92PE6327HTSA1 |  | 15
Q5,Q7,Q14 | 2N3906 | TO-92, E-B-C pinout | Package_TO_SOT_THT:TO-92_Inline_Wide |  |  | 3
Q9,Q18 | 2N3904 | TO-92, E-B-C pinout | Package_TO_SOT_THT:TO-92_Inline_Wide |  |  | 2
R1 | 9.1k | thick film 0805, 1 % | Resistor_SMD:R_0805_2012Metric |  |  | 1
R2,R5,R7,R8,R26,R28,R29,R31-R33,R36,R46,R56 | 10k | thick film 0805, 1 % | Resistor_SMD:R_0805_2012Metric |  |  | 13
R3,R14,R15,R18,R20,R22 | 11k | thick film 0805, 1 % | Resistor_SMD:R_0805_2012Metric |  |  | 6
R4 | 5.1k | thick film 0805, 1 % | Resistor_SMD:R_0805_2012Metric |  |  | 1
R6,R12 | 7.5k | thick film 0805, 1 % | Resistor_SMD:R_0805_2012Metric |  |  | 2
R9,R50 | 820 | thick film 0805, 1 % | Resistor_SMD:R_0805_2012Metric |  |  | 2
R10,R11,R16,R19,R21 | 27k | thick film 0805, 1 % | Resistor_SMD:R_0805_2012Metric |  |  | 5
R13,R35 | 560 | thick film 0805, 1 % | Resistor_SMD:R_0805_2012Metric |  |  | 2
R17 | 1k | thick film 0805, 1 % | Resistor_SMD:R_0805_2012Metric |  |  | 1
R23 | 120 | thick film 0805, 1 % | Resistor_SMD:R_0805_2012Metric |  |  | 1
R24,R45,R48,R52,R54 | 330 | thick film 0805, 1 % | Resistor_SMD:R_0805_2012Metric |  |  | 5
R25,R60 | 6.8k | thick film 0805, 1 % | Resistor_SMD:R_0805_2012Metric |  |  | 2
R27 | 3.3k | thick film 0805, 1 % | Resistor_SMD:R_0805_2012Metric |  |  | 1
R30 | 6.2k | thick film 0805, 1 % | Resistor_SMD:R_0805_2012Metric |  |  | 1
R34 | 220k | thick film 0805, 1 % | Resistor_SMD:R_0805_2012Metric |  |  | 1
R37 | 2.2 | thick film 0805, 1 % | Resistor_SMD:R_0805_2012Metric |  |  | 1
R38,R62 | 100 | thick film 0805, 1 % | Resistor_SMD:R_0805_2012Metric |  |  | 2
R39,R42 | 47 | thick film 0805, 1 % | Resistor_SMD:R_0805_2012Metric |  |  | 2
R40,R47,R51,R53 | 180 | thick film 0805, 1 % | Resistor_SMD:R_0805_2012Metric |  |  | 4
R41 | 4.7k | thick film 0805, 1 % | Resistor_SMD:R_0805_2012Metric |  |  | 1
R43 | 220 | thick film 0805, 1 % | Resistor_SMD:R_0805_2012Metric |  |  | 1
R44 | 68 | thick film 0805, 1 % | Resistor_SMD:R_0805_2012Metric |  |  | 1
R49 | 270 | thick film 0805, 1 % | Resistor_SMD:R_0805_2012Metric |  |  | 1
R55 | 470 | thick film 0805, 1 % | Resistor_SMD:R_0805_2012Metric |  |  | 1
R57 | 100k | thick film 0805, 1 % | Resistor_SMD:R_0805_2012Metric |  |  | 1
R58 | 47k | thick film 0805, 1 % | Resistor_SMD:R_0805_2012Metric |  |  | 1
R59 | 2.2k | thick film 0805, 1 % | Resistor_SMD:R_0805_2012Metric |  |  | 1
R61 | 33k | thick film 0805, 1 % | Resistor_SMD:R_0805_2012Metric |  |  | 1
R63 | 13k | thick film 0805, 1 % | Resistor_SMD:R_0805_2012Metric |  |  | 1
R64 | 15k | thick film 0805, 1 % | Resistor_SMD:R_0805_2012Metric |  |  | 1
R65 | 0R link | thick film 0805, 1 % | Resistor_SMD:R_0805_2012Metric |  |  | 1
R66-R69 | 10R | thick film 0805, 1 % | Resistor_SMD:R_0805_2012Metric |  |  | 4
TP1 | inject 12.9M |  | TestPoint:TestPoint_Pad_D2.0mm |  |  | 1
TP2 | audio mon |  | TestPoint:TestPoint_Pad_D2.0mm |  |  | 1
TP3 | gnd |  | TestPoint:TestPoint_Pad_D2.0mm |  |  | 1
Y1 | 25.000MHz | HC-49/S, FUNDAMENTAL mode (not overtone), CL 18-20 pF | Crystal:Crystal_HC49-4H_Vertical |  |  | 1

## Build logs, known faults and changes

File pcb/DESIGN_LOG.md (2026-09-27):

# PCB — discrete 137.9 MHz FM satellite receiver

> This is the complete, step-by-step design log of the PCB, kept as I wrote it along the way. For the short overview, start with [README.md](README.md).

This is the board-level design for the receiver that is simulated and verified in
[`../fm_receiver/`](../fm_receiver/). The electrical reference for this board
is **`../fm_receiver/simulations/sim12_full_receiver.net`**. It is the LTspice-generated
netlist of the full receiver, and it was checked line by line against every block
simulation. If this folder and that netlist ever disagree, the netlist wins.

## Frozen decisions

1. **One board.** 180 × 75 mm (Edge.Cuts (50,50)–(230,125)), 2 layers, FR4
   1.6 mm. I planned it at ~70 mm, but the south 5 mm went to the ADC network
   and the socket row. I considered putting RF+LO on a shielded daughterboard
   and left it for later: coax joints and a two-stage alignment cost more than
   they give at rev 1. If bring-up shows an isolation problem, rev 2 can split.
2. **Bottom layer = unbroken ground plane.** No routing on the bottom in the
   IF-strip region. Every trace over the plane is a slot, and a slot under a
   96 dB strip is a shared-impedance feedback path. All routing goes on top, and
   the top ground pour is stitched to the plane.
3. **Via-stitching walls as free shielding provision.** A row of ground vias
   at ~5 mm pitch under an exposed top copper strip. One wall goes between the IF
   row and the bottom row, and one between the mixer and the IF strip. Nothing is
   soldered at assembly. If the strip oscillates at bring-up, I can solder a strip
   of brass sheet vertically onto the exposed copper and get a real shield wall
   without a respin. Cost: zero.
4. **A test SMA with a 0 Ω bridge.** The antenna SMA J1 is fitted, because it is
   the receiver input (net tapA, no link). A second SMA footprint J2 (DNP on
   board and schematic) sits at the BPF→LNA seam on tapB, with the 0 Ω link
   R65 (tapB → lna_in) in the signal path. At bring-up I fit J2, remove R65,
   and sweep J1→J2 on the miniVNA against SIM 7 (rev 2: 39.5 dB image
   rejection, 6.1 MHz passband). Then I drive J2 into the LNA and check it
   against SIM 9. After the step F emitter re-placement I expect S21 ≥ 13.5 dB
   and VSWR ≤ 1.3 (the layout's remaining ~4.4 nH of emitter inductance costs
   ~1.6 dB against the 15.8 dB of the ideal netlist). Then R65 goes back.
5. **Alignment pads.** An injection pad through 1 nF to the first IF base
   (drive it at 12.9 MHz, which skips the RF front end completely) and a monitor
   pad on the detector's audio output. The eleven trimmers get aligned with a
   procedure (inject, turn, maximize), not by guessing.
6. **ESP32 dev module on a socket header** in the bottom-right corner. The USB
   face is flush with the east board edge, and the module's WiFi-antenna end sits
   *over* the board at the socket's west end (x ≈ 174–180). The module ground is
   tied to the plane at two points (J3.1 by the socket's west end, J4.14 by the
   power pin). WiFi stays **off** during a pass: record first, transmit after.
   The 5 V comes from the module's `EXT_5V` header pin, which on the DevKitC V4 is
   **USB VBUS minus a BAT760 Schottky (D3)**. At the ~100–125 mA that the module
   and receiver draw together, that is 0.32–0.35 V, so I expect **4.6–4.7 V at L12**,
   not the 5.0 V the simulations used (checked, see the Sept 2026 audit note).
   The receiver takes it through a **ferrite bead (600 Ω @ 100 MHz) +
   1000 µF bulk + 100 nF**. I considered a series resistor and rejected it:
   4.7 Ω at 41.6 mA would drop the rail by 0.2 V and shift every ratiometric
   bias by ~4 %, while the bead costs ~12 mV and still blocks RF. The audio
   chain keeps its own RC-filtered rail (RSUP 100 Ω + CSUP 100 µF + 100 nF),
   as in SIM 2 rev 3.

## Generated schematic — `qfh_receiver.kicad_sch`

The schematic is **generated by a script** from the golden netlist, with
`assemble`-style tooling (see the project history). Every simulated part is
placed on a grid with **global labels bound directly at its pins**. On top of
that come the board-only additions: SMAs, 0 Ω link, trimmers, the real crystal in
place of the simulated equivalent circuit, ESP32 socket, supply filters and test
points. It is a *netlist-correct master*, not a drawing to read. The readable
schematics are still the LTspice files. To verify it, `kicad-cli sch export netlist`
was compared pin by pin against the transformed golden netlist: **376 pins, 0
mismatches**. Every part has a `SimRef` field with the name of its LTspice
instance, so every board part can be traced back to its simulation.
Tapped toroids are single 3-pin parts (`qfh:L_TOROID_TAP`). The two IF-filter
toroids have link-winding pins (4/5) joined by nets `lnk_a`/`lnk_b`.

## Floorplan (top view)

```
+--------------------------------------------------------------------------+
| [SMA ant] BPF (2 air coils, | LNA | MIXER | == IF STRIP, 96 dB, straight |
|  plane cutouts) [SMA test]  | SMD | +T1   |  T2 [1][2][3][4] lim | DET T7 |
|-------- via wall ----------------------------------------------- via wall|
| LO CHAIN: xtal 25MHz | buffer | x5 (2 air coils) -> up into mixer LO port |
|                      AUDIO chain (2400 Hz, folds freely) <- from detector |
|  power entry / bulk filter          ESP32 module socket [USB over edge] > |
+--------------------------------------------------------------------------+
```

- IF strip: 7 toroids on edge, alternating up/down, 12 mm pitch, input and
  output at opposite ends. It is never folded (96 dB = 63 000:1, and the straight
  layout keeps the limiter→input coupling ~24 dB below the oscillation
  threshold).
- Microvolts are on the left edge, volts on the right. The LO's 1.68 V at
  125 MHz enters the mixer over a ~5 mm trace.
- Audio (2400 Hz) does not care about layout and can be routed wherever it fits.

## Footprint library — `qfh_receiver.pretty`

| Footprint | Used for | Notes |
|---|---|---|
| `TOROID_T37-6_UNIVERSAL` | all 7 toroids | pins: 1 = cold end, 2 = tap (empty on plain coils), 3 = hot end, 4/5 = link (3 turns of 0.4 mm over the main winding, fitted on **L1 and L7 only**: the two IF-filter tanks, k = (3/27)² ≈ 0.012; drop to 2 turns if the filter comes out over-coupled, see SIM 3). One winding recipe for all: 27 turns of 0.4 mm, and L1–L4 get a twisted loop at turn 13. Which coil gets what is in the schematic symbol names (`L_TOROID`, `_TAP`, `_LINK`, `_TAP_LINK`) and in the BOM's Spec column. Mount on edge with nylon M3 or RTV, never hot glue. |
| `AIRCOIL_5MM` | BPF L8/L10 (5 turns = 82 nH), ×5/LO tanks L9/L11 (7 turns = 150 nH) | includes a copper-pour keepout on both layers, because a plane under an air coil kills its Q. Coupled pairs sit ~one diameter apart, and that spacing is what sets k ≈ 0.03. |

Everything else uses stock KiCad libraries: SOT-23 (BFR92P, because BFR93A is
obsolete, see the sourcing pass), TO-92 (2N3904/6), SOD-323/DO-35 (1N4148,
1N5711), 0805 R and C (every passive on the board is 0805), HC-49/S crystal,
Murata TZC3 trimmers,
`Connector_Coaxial` SMA, and two 1×19 socket rows for the ESP32-DevKitC.

## Known constraints carried from simulation

- **LNA emitter bypass is layout-critical**: RE1 (R37, 2.2 Ω) and CE2 (C49,
  100 nF) are soldered tight to the transistor, with CE2 on its own via straight
  into the plane. What series emitter inductance costs (SIM 9 with L stepped in
  the emitter): 1.2 dB of S21 at 3.5 nH, 2.4 dB at 6 nH, 4.2 dB at 10 nH. At
  10 nH it also turns the input from 35 − j15 Ω capacitive to 66 + j27 Ω inductive.
  The board as routed in August had CE2 20 mm from the emitter (~12 nH: S21 ~11 dB,
  not 15.8). Step F re-placed R37/C49/R42 so the emitter-to-plane copper is
  5.2 mm (~4.4 nH with the via and the cap's ESL). I expect S21 ~14.1 dB, Zin
  ~47 + j9 Ω, VSWR ~1.2.
- Every IF stage gets local 100 nF decoupling on **both** VCC and vb2. The
  shared cascode bias rail becomes a feedback path at 96 dB if it is only
  decoupled at one end.
- Tank trimmer targets (from simulation, taken up at alignment; the trimmers
  are the real Murata TZC3 parts, 6.5–30 pF and 3–10 pF): detector 66.7 pF,
  IF stages 68.7 pF, IF filter 69.2 pF (all built as 56 pF NP0 + 6.5–30 pF).
  BPF: 8.2 pF + 56 pF tap caps and a 3–10 pF trimmer that I expect at **6.3–6.7 pF
  on the board** (5.2–8.1 pF over ±10 % coils and 0.5–1 pF of stray). In the ideal
  netlist it reads ~8.7 pF, because the layout's 8.6 nH and 0.5 pF are not in it
  (see step E values). ×5 tank: 10.8 pF total as 3.3 pF fixed + 3–10 pF trimmer,
  expected at ~5.4 pF (4.6–6.5 over ±10 % coils). LO tap: 14 pF total as 5.6 pF
  fixed + 3–10 pF trimmer, expected at ~5.8 pF (4.6–7.5), over 47 pF fixed.
- Total draw: 40.7 mA from the real 4.6 V rail (~187 mW). It was 41.6 mA at the 5.0 V that the early simulations assumed.

## Routing — pass 1 (scripted, critical signal path)

This pass was routed by script (0.5 mm tracks, F.Cu only, as in frozen decision 2).
Every endpoint was checked against the extracted pad table before writing, and
the result was validated with `kicad-cli pcb drc --refill-zones`: **DRC identical to the
pre-routing baseline (65, all known waivers/cosmetics), zero new violations.**

Routed:

- **IF strip**: every tap → coupling cap → next base (tap1/b2, st2/b3,
  st3/b4), every cascode collector → tank toroid (c1–c4), and the c4 → output
  coupling. Where a tap trace and a collector trace would have to cross
  (the tap pad sits left of the hot pad on every toroid), the tap goes *over the
  toroid* through the empty y=58.8 strip and the collector takes a vertical
  channel beside the cluster. No bottom-layer hops, so the plane stays whole.
- **LNA → mixer**: LNA out → mixer RF coupling (n_rf2, routed around the
  *left* of the LNA cluster to avoid interleaving with ln_c), collector → Cout
  (ln_c), mixer base (brf), test-link input (lna_in).
- **LO → mixer**: the 21 mm LO delivery from the ÷tap (n_lo) up the free
  corridor at x=111.5, the mixer LO base (blo) with a dogleg that clears the
  SOT-23 emitter pad, and the bias-feed leg over the top of the transistor row.
- **11 ground vias** (0.8/0.4) with short stubs at every emitter bypass and
  tank cold end: CE2_L (the layout-critical LNA bypass), CE1i/CE2–4_S,
  Ct1–4 cold pads, Rout_S, Cbot_X.

Later passes finished the detector/limiter corner, the IF1 stage and mixer-filter
interface, and the mixer core. Each time the fix was to re-place a few parts along
the signal flow, not to bend traces around a bad orientation. Three findings kept
coming back:

- When a cluster is hard to route, the parts are usually facing the wrong way.
  Swapping the two IF1 transistors (the cluster was mirrored compared to stages
  2–4), swapping the limiter diodes, and rotating the LO bias resistor 90°
  (its two nets crossed *at the pad* while it lay horizontal) each solved a
  knot that no amount of trace shaping could.
- Courtyards, not pads, set the spacing: 3.3 × 1.9 mm for an 0805 against
  ~3.9 × 3.2 mm for a SOT-23. Column pitch under ~3.5 mm will not pass.
- Check the pad *edge*, not its centre. A bias trace cleared the vcc pad
  centre by 0.9 mm and still failed at 0.067 mm from its corner.

**One approved exception to decision 2**: the LO base feed (`blo`) and the LO
bias junction (`vb2n`) each take a ~6 mm hop on B.Cu with two vias. Q2's base
and emitter share one face of the SOT-23, but their nets arrive from opposite
directions, and the e23 corridor blocks the region. Eight single-layer
topologies were checked on coordinates (every rotation of Q2, moving it east,
moving the pair south, moving the injection cap to the base), and each one only
moved the crossing somewhere else. The two slots are in the mixer corner, >20 mm
from the 96 dB IF strip that the rule is there to protect, and they carry LO drive
and bias, not IF signal.

## Routing complete

Every signal and supply net is routed: 753 track runs (105 of them mitred to 45°),
183 vias and 188 footprints. Every footprint is on the front, and the back is a plane. The ratsnest went from 271 connections to 0, and DRC
is at 12 violations, all of them silkscreen cosmetics.

*(These counts include the post-verification fixes and the decoupling addition below.
Before them the board had 724 segments / 168 vias / 175 footprints. The
"619 / 170" figure in earlier versions of this file was from before the chamfer
pass, which splits segments at every mitre.)*

The same thing happened again and again: **when a cluster resists
routing, the parts are facing the wrong way.** Swapping the two IF1 transistors,
swapping the limiter diodes, rotating the LO bias resistor 90°, swapping both
audio divider pairs, and moving the ADC divider to the socket each solved a
knot that no amount of trace shaping could. Six clusters had the same cause.

### Bottom-layer exceptions

Decision 2 (unbroken bottom plane) holds everywhere except the vb2 bias rail
under the IF strip (see the caveat below). 27 segments across 11 nets take a
short B.Cu hop, 136.5 mm in total (state after step F; it was 35 segments /
14 nets before the September 2026 cleanup). I list them here so a reviewer does
not have to search for them:

| Net | Length | Why |
|---|---|---|
| `vcc` | 44.0 mm (8 segments) | Supply pockets fully enclosed by signal routing (LO pair, oscillator collector, ×5 damping resistor). Two of the hops run 10–16 mm; step D2 removed the mixer-tank hop and step E2 shortened the oscillator feed. |
| `vb2` | 27.9 mm | The collector channels form north–south walls every 12 mm along the IF strip, and a DC bias rail cannot cross them on the front. **See the caveat below: these four are the ones that are not clear of the strip.** Measured in step F: hop 1 (131.75,74.65)–(141.6,73.05) 10.5 mm under b1; hops 2–4 (148.9→153.9 / 159.7→165.9 / 171.7→177.9, y ≈ 73) 5–6.2 mm each under b2/b3/b4 and the c1/c2/c3 risers. Every crossing pairs a riser with the base that the riser's own tank already drives through its tap, so it is feed-forward, not a loop. No slot is crossed by both an early and a late stage node. The return-current detour is 1.3–4.3 mm per crossing (< 3 nH, < 0.03 Ω at 12.9 MHz). |
| `n_rf2` | 23.3 mm | Its original west detour was a wall that would have forced **five** LNA nets to hop. One hop for this net is better than five for the others. |
| `blo`, `vb2n` | 6.1 / 6.9 mm | Q2's base and emitter share one SOT-23 face, but their nets arrive from opposite sides, and the e23 corridor blocks the region. Eight single-layer topologies were checked on coordinates, and each one only moved the crossing. |
| `a_e4b` | 7.5 mm | Local: every gap in the audio component row already had a net through it. |
| `audio`, `ln_c`, `ef3`, `y4` | 2.5–4.3 mm each | Same reason, one hop each. |
| `a_ce` | 6.4 mm | Two hops (2.9 + 3.5 mm) under the ESP32 socket, outside the IF strip. Step E3 removed the `vin5`, `adcref` and `adc` hops when it rebuilt the power entry and the ADC divider. |

All are DC or audio except `n_rf2`. **One correction to what this section used to
say:** the four `vb2` hops are *not* clear of the 96 dB IF strip. They run
at y ≈ 73, inside the SOT-23 row, and each one passes under a stage's input and output
traces, so they cut the plane exactly at the stage interfaces. That is a real weakness
against frozen decision 2, and I write it down here instead of hiding it. The
decoupling half of the problem was fixed by the per-stage 100 nF of step C and
the `vcc_if` split of step E3. The four hops themselves stay, measured and
justified in the table above (routing vb2 on the front would need the whole
SOT-23 row moved, which is a rev 2 job).

## Finishing

- **Corners** mitred to 45° where two segments meet at a right angle and nothing is
  anchored at the vertex. At 137.9 MHz the wavelength in FR4 microstrip is ~1.2 m,
  so a 0.5 mm corner is λ/2400. This is convention, it does nothing electrically.
- **Silkscreen**: the toroid outline crossed its own link pads, and its pin labels
  were 0.7 mm against a 0.8 mm minimum. The air-coil outline circle sat on its pad
  ring. Both are fixed in the library files and in every placed copy. Reference
  designators flagged by DRC were moved by a solver that scores candidate spots
  against pads, tracks, vias, other labels *and* footprint silkscreen. This took
  the silkscreen violations from 71 down to 12.
- **DRC rules** (`qfh_receiver.kicad_dru`): edge-launch SMA pads and their launch
  tracks are allowed to reach the board edge, but only inside two small named rule
  areas, so the check still works everywhere else. Library-sync mismatch is set to
  ignore, because it is a housekeeping check, not a manufacturing one.

### The test SMA "self-short" — a real bug, not a waiver

For most of the layout's history DRC reported that the test SMA's centre pad was
shorted to its own shell pads, and this was dismissed as an edge-launch artifact.
That was wrong. When the actual pad rectangles were computed, the pads turned out
to be **90° off**: the placement script had rotated the footprint without updating
the pads' stored angles (which in KiCad are absolute). The antenna SMA has the same
hidden error, but it looks correct, because at its 180° placement the wrong angle
and the right one give the same rectangle. The test SMA at 90° was really broken:
the pads overlapped each other, lay along the edge instead of across it, and could
not be soldered as drawn. The fix was to set the five pad angles to 180°. Each
shell also has a via now, tying its front and back faces to the plane (before,
they were "connected" only through the short).

I took two things from this. First, a violation that survives every pass is not
automatically a waiver: compute the geometry before classifying it. Second, a
script that rotates a footprint must rotate the pad angles too (the same bug was
caught and fixed for two other parts earlier, but the SMAs were placed before that
fix).

**DRC now: 11, unconnected 0.** The board is fully connected. The eleven remaining items are silkscreen cosmetics (labels in the mixer's densest column and in the cascode column, where three labels per 12 mm stage do not fit, plus D5's polarity marker).

## Sourcing pass — the catalogue check that found two bugs

I order the components from Farnell NL. Checking the board against a real
distributor catalogue, instead of against the values written in the schematic,
changed four things, and two of them were hidden design errors, not supply
problems.

**BFR93A is obsolete.** NXP does not make it anymore, and Farnell NL gives no
exact match for it at all. That is 15 parts: the LNA, the mixer, the oscillator
and the whole 96 dB IF strip. I replaced it with **BFR92P** (Infineon, order code by
manufacturer part `BFR92PE6327HTSA1`): same SOT-23 package, same B-E-C pin order
on pins 1-2-3, 5 GHz f<sub>T</sub>, and 15 V V<sub>CEO</sub> instead of 12 V. The
simulations never modelled a BFR93A in the first place. They used a generic
`NPN(BF=100, CJC=0.7p, TF=28p)`, which is an RF NPN of about 5.7 GHz, so nothing had
to be re-simulated. BFR92P is actually the better fit: BFR93A was optimised for
5–30 mA, BFR92P for 0.5–20 mA, and this board runs about 2 mA per stage.

**The specified trimmer ranges do not exist as products.** The schematic asked
for 1–10 pF and 5–30 pF parts. The real Murata TZC3 ranges are 3–10 pF and
6.5–30 pF. Checking every tuned circuit against the ranges you can actually buy
showed two capacitors whose fixed value was chosen as if a trimmer could
remove capacitance as well as add it:

| Tank | Needs | Was | Reachable? | Now |
|---|---|---|---|---|
| ×5 multiplier, 125 MHz | 10.8 pF total | `C3` = 10p | no, the floor is 11 pF | `C3` = **4.7p** |
| LO output, 125 MHz | 14 pF total | `C12` = 12p | only at the stop | `C12` = **8.2p** |

*(Replaced on 2026-09-25 by the values pass after layout step E, once the
board's own parasitics were measured: `C3` = **3.3p**, `C12` = **5.6p**, and
the BPF tap caps `C23`/`C27` = **8.2p**, `C24`/`C28` = **56p**. Order these,
not the values in the table above. The reasoning is in the Step E section.)*

The ×5 tank could not be reached even with the idealised 1–10 pF part. This
error stayed invisible as long as the BOM had a trimmer that nobody sells.

With the real parts and the corrected fixed values, every tuned circuit ends up
mid-range:

| Tank | Tuning range | Target | Trimmer sits at |
|---|---|---|---|
| Input BPF ×2 | 115.8 – 138.8 MHz | 137.9 | 3.20 pF, near the low stop |
| ×5 multiplier | 107.2 – 148.1 MHz | 125.0 | 6.11 pF |
| LO output | 113.5 – 136.6 MHz | 125.0 | 5.83 pF |
| IF ×7 | 11.6 – 13.6 MHz | 12.9 | 13.19 pF |

*(Trimmer positions above are for the pre-step-E values and an ideal netlist. On
the built board I expect ×5 ~5.4 pF, LO ~5.8 pF, BPF ~6.5 pF, each ≥ 1.9 pF from
either stop (see "Known constraints" and step E).)*

**Ordering data lives on the symbols now (step F).** Every schematic symbol
has hidden `MPN` / `Farnell` fields where a catalogue part was confirmed
(Murata TZC3P300A110R00 = Farnell 2456139 for the seven 6.5–30 pF trimmers,
TZC3R100A110R00 = 2456140RL for the four 3–10 pF ones, but confirm the cut-tape
code before ordering; Infineon `BFR92PE6327HTSA1` for the 15 BFR92P; Amphenol
132289 = 2112467 for the SMAs). It also has a `Spec` field for what a distributor
needs beyond the value: **every pF-range capacitor is NP0/C0G** (an X7R 56 pF would
drift the IF tanks by ~±260 kHz over a room's temperature swing), nF-range
parts are X7R, the electrolytics 10 V (D5/P2.5 for the 100 µF, D8/P3.5 for the
1000 µF), the crystal is a **fundamental-mode** HC-49/S (a 3rd-overtone 25 MHz part
would run at 8.3 MHz in this Colpitts), and each coil has its winding recipe. The BOM
is exported from those fields: `pcb/fabrication/qfh_receiver_bom.csv` (71 lines; the
four toroid variants stay on separate lines).

The BPF pair was the only position still close to a mechanical stop. Its
trimmer is the *only* capacitance across the tank. The divider (13.04 pF then,
7.15 pF since step E) is fixed by the impedance match and cannot be traded
against it. So the coarse adjustment there is the coil, exactly as SIM 7 says:
wind five turns and squeeze or spread them. If a coil comes out with too much
inductance, the trimmer cannot compensate, and I have to stretch the coil instead
of turning the trimmer. This block can be swept on its own on a miniVNA, so it is
also the block where this problem is easiest to catch.

**Trimmer footprints unified.** Seven positions had a Sprague-Goodman SGC3
footprint and four a Murata TZC3, but only Murata is stocked. The two footprints
are geometrically identical apart from the pads (±1.8375 mm / 1.075 × 1.4 mm
versus ±2.075 mm / 0.85 × 1 mm) and 0.12 mm of courtyard. All eleven are now
TZC3. No re-routing was needed: the pads move 0.24 mm outward, and the existing
track endpoints stay inside the new rectangles with 0.188 mm of margin. This was
checked geometrically on all 22 pads and confirmed by DRC: 12 violations and 0
unconnected, the same as before.

**Not available from Farnell:** the T37-6 iron powder cores (7 needed). Micrometals
amateur-radio core sizes are not in the catalogue, so I get them separately from
kitsandparts.eu or rf-microwave.com. Avoid UK suppliers because of post-Brexit
customs into NL.

This is the same kind of mistake as the SMA one above. A value in a schematic is
only a guess until something outside the design confirms it. An idealised trimmer
range hid a tank that could never have been tuned, and I would only have found it
on the bench, after paying for the board.

## Independent verification pass — two board-killing defects

Before releasing gerbers, I had the finished board verified again from scratch by eight
independent checks that ran against the files, not against the design intent:
schematic↔PCB net consistency, board netlist versus the golden LTspice netlist,
raw copper geometry (shorts and connectivity computed without DRC), footprint
fidelity against the library sources, zones and keepouts, component values and
polarity, RF layout quality, and a DRC/ERC/gerber export dry run. Every finding
was then given to a separate check that tried to disprove it by recomputing the
numbers behind it.

Thirty-three findings came back. Two of them meant the board could not work.

### The TO-92 transistors had base and emitter swapped

The schematic was generated by a script using KiCad's generic
`Q_NPN_BEC` / `Q_PNP_BEC` symbols for **every** transistor. For the fifteen
SOT-23 parts that is correct, because a BFR92P really is base-emitter-collector on
pins 1-2-3. For the five TO-92 parts it is not: a 2N3904/2N3906 is pin 1 = emitter,
pin 2 = base, pin 3 = collector, which is why KiCad's own `2N3904` symbol extends
`Q_NPN_EBC`. So the board sent the base net to the left hole and the
emitter net to the middle one.

This cannot be fixed at assembly time. **The base is the middle lead on
every TO-92 transistor made**, so no insertion angle and no substitute part can
save it. Rotating the device 180° only puts the collector on the base net. All
five audio stages (the Q5/Q7 differential pair, Q9, Q14 and the Q18 output)
would have been in reverse-active bias, and the ESP32 would have received silence.

Three independent sources agreed before anything was changed: KiCad's
own symbol inheritance, the datasheets of the real parts, and the board's own topology
(pad 2 of each part runs to an emitter resistor: R41 and R49 to ground for the
NPNs, R36 and R46 to `vaud` for the PNPs).

The fix swaps pads 1 and 2 on all five and reroutes both nets at each one. Four of
the five could be rerouted on the front layer with no via and no bottom-layer copper.
The emitter nets at Q9 and Q14 pass *through* the transistor pad as a junction, so
deleting the stub would have split the net in two, and those were rerouted around
the package instead. The schematic symbols were changed to the `EBC` variants,
which fixes the root cause: the two symbols have **identical pin
positions** and differ only in pin numbering, so not one wire moved.

There was one trap here. The five reroutes were designed separately and in
parallel, and two of them share a net: `a_b1` ties Q5's emitter to Q7's base.
Each design assumed the *other* transistor stayed broken, so when both were applied
they shorted `a_b1` to Q7's pad and left a dangling stub. Parallel design is safe
when the geometry does not overlap, and unsafe as soon as two workers touch the same
net. The combined route had to be drawn once, by hand, afterwards.

### The ESP32 socket could not have powered anything

J3/J4 are a 2×19 header at 25.4 mm, the DevKitC 38-pin footprint. Only five pads
were wired, and two of them were wrong. The board's whole 5 V feed was on the
module's **GPIO23**, and a ground landed on **EN**, which keeps the chip in
reset all the time. The module's real 5 V pin (row-A position 19) was not connected.

Before anything moved, the pinout was checked against the Espressif ESP-IDF DevKitC
V4 guide, a second pinout reference and the ESP32-WROOM-32 module pin list. All four
possible insertion orientations were also listed. Only one is physically possible
for a socketed module, and with it the three remaining anchors (3V3, GPIO36, GND)
are all correct. So the defect was certain and did not depend on orientation.
`vin5` now lands on row-A pin 19 and a second ground on row-A pin 14, with EN left
floating (the DevKitC has its own pull-up).

The root cause is still visible in the file: J3 and J4 were labelled "row A" and
"row B" the wrong way round, and that is almost certainly how the two wrong pins were
picked. Those labels are corrected too, otherwise the bug would come back on the
next edit.

Two notes for the firmware, not the board. GPIO36 is on ADC1, which is the unit
that keeps working while WiFi is on (ADC2 does not), so the pin choice is right.
And the 10k/6.2k divider sits at 1.26 V quiescent, which needs
`ADC_ATTEN_DB_6` or `DB_11`, because the default 0 dB range tops out at 950 mV.

### Also fixed

The default netclass track width was 0.2 mm, but the board minimum is 0.25 mm, so
any track drawn by hand in the GUI would have failed DRC as soon as it was drawn.
J2 now has a real `dnp` attribute instead of only saying so in its value field.

## IF strip decoupling — the constraint that only existed in prose

The "Known constraints carried from simulation" section above has always said:
*every IF stage gets local 100 nF decoupling on BOTH vcc and vb2*. The board did
not do it, and neither does `sim12`: it has exactly one `Cbyp_S` and one
`Cb2_S`. In a lumped netlist, eleven ideal 100 nF in parallel are electrically
the same as one. That is how a layout rule can stay unimplemented in a document
for months without any simulation catching it. As built, the four tank cold ends
were 34–49 mm from the nearest vcc-to-ground capacitor, and the four cascode bases
were 30–62 mm from the nearest vb2 one.

**Thirteen 100 nF 0805 capacitors closed it** *(as first placed in August 2026;
this changed twice since. C74/C77/C78/C75 moved to the front at (146.6 | 158.6 |
170.6 | 182.6, 71.25) in step C, and C66–C73 moved to y = 57 at x = tap − 5.24 /
+ 0.16 on the new nets `vcc_if1..4` behind the series parts R66–R69 in step E3.
C76 is unchanged)*:

| Part | Where | Why there |
|---|---|---|
| C66–C73 | front, y = 53.35, straddling each stage's vcc drop | two per stage, at x = tap ± 1.1 mm, in the empty 5.5 mm strip between the board edge and the vcc trunk |
| C76 | front, x = 115.99 | the corner where the vcc feed to the mixer tank leaves the trunk |
| C74, C77, C78, C75 | **back**, directly under Q8/Q13/Q17/Q20 | the shortest possible loop from each cascode base to the ground plane |

Two things about how this was decided. First, the initial proposal put vb2
capacitors at stages 1 and 4 only, saying that stages 2 and 3 were "not worth
rerouting". But when the two skipped sites were measured, they were geometrically
identical to the two that were accepted, so leaving them out was a choice and not
a real limit. All four stages get one.

Second, the proposal said the back-side ground pads would connect to the plane
"by thermal spokes, which is what makes this the lowest-inductance mounting
available anywhere on this board." **Both ground zones on this board are
`connect_pads no`**: the plane never connects to a pad, and that is exactly why
every ground pad here has its own stub and via. Built as proposed, those
four capacitors would have had a floating ground terminal and done nothing at all.
Each one now gets a short back-side stub to its own via, at positions found by
searching for clearance, not assumed (margins 0.35–0.60 mm).

A note for the bench: with a single 0805 and its via, the mounting loop is about
3.5 nH, so a 100 nF is already past self-resonance at 12.9 MHz and looks like
roughly 0.16 Ω. Two in parallel per stage is what gives the margin. It is not the
capacitance that helps (it does not matter this far above resonance) but the
halved inductance.

### The vb2 hop under the strip

The first of the four `vb2` bottom-layer hops ran at y ≈ 73.05–73.45, straight
through the transistor row, and crossed **b1** twice (b1 is the strip input, a
microvolt-level node). It now drops to y = 74.65, below the row.

This one was close, and the numbers decided it: the reroute halves the crossings
of b1 from two to one, but makes the plane slot longer, from 7.01 mm to 10.51 mm.
A slot forces a return-current detour of about its own length, so two crossings of
a 7 mm slot cost more detour (≈14 mm) than one crossing of a 10.5 mm slot
(≈10.5 mm). On top of that, the broadside overlap with b1 falls about four times.
Hops 2, 3 and 4 stay where they are. With a 100 nF now at each cascode base, the
vb2 rail between stages carries almost no signal current, so only the plane slot
is left, and moving those hops would make the slots longer without removing
crossings.

### Still open

- **No mounting holes**, on purpose. A 180 mm board with an edge-launch SMA
  taking cable torque and a plug-in module taking insertion force has nothing to
  bolt it down. A four-corner pattern is possible geometrically, but the top-left
  candidate would put steel hardware 7 mm from the L8 tank coil, and every
  position near the module ends up underneath it once the module is plugged in.
  Left out at my request; I will revisit it if the board goes into an enclosure.

## September 2026 audit — step A (hygiene, no copper moved)

After the decoupling and socket fixes, a second independent audit by AI review
agents ran over the board (six of the eight review lenses finished before a usage
limit paused it). The free, deterministic items were applied right away:

- **Pad metadata** on Q5/Q7/Q9/Q14/Q18 now says E/B/C in the right order
  (the nets were already right; the labels were the last leftover of the BEC error).
- **J2 is DNP in the schematic too**, so an Update-PCB-from-Schematic no longer
  clears the board's flag. J3/J4 `SimRef` fields follow their corrected row
  labels.
- **ESP32 legend and envelope**: `B1=GND` / `A1=3V3` silkscreen cues at the
  socket's west end and a one-line row map north of J3 (a reversed module
  would short EXT_5V to GND, so the marking is cheap insurance). The module outline,
  WROOM antenna overhang, WROOM body and micro-USB position are on `Dwgs.User`
  and `F.Fab` for the assembly drawing.
- **Collinear runs merged**: only two existed (763 → 761 segments). The
  "stitched" look comes from jogs and stacked runs, not chains, and those are for
  the next pass.
- Socket geometry checked again against Espressif's DevKitC V4 drawing:
  2×19, 2.54 mm pitch, 25.40 mm rows, pin 1 square at the antenna end,
  1.0 mm holes for 0.64 mm square pins. Correct. Nothing under the module is
  taller than 1.4 mm, against an 8.5 mm stand-off.

**The rail is 4.6 V, not 5.0 V.** The DevKitC's 5V header pin is `EXT_5V` =
USB VBUS through a BAT760 Schottky. At the ~110 mA that the module and receiver
draw together, the diode drops 0.32–0.35 V. `sim12` was re-run at the real rail
(`.op`, LTspice batch):

| supply | Ic shift, median of 20 transistors | IF cascode Ic | vb2 | cascode mid-node |
|---|---|---|---|---|
| 5.0 V | — | 1.013 mA | 2.570 V | 1.855 V |
| 4.6 V (typical) | −16.5 % | 0.846 mA | 2.379 V | 1.669 V |
| 4.4 V (worst case) | −25 % | 0.763 mA | 2.284 V | 1.576 V |

This is more than the "0.2 V → 4 %" estimate in frozen decision 6, because V_BE is
not ratiometric. No stage loses headroom, but gain follows Ic: about −1.6 dB per IF
stage, roughly −8 dB over the chain, so full limiting moves from ~−106 dBm to
~−98 dBm, against a ~−100 dBm horizon signal. The pending decision was made, see below.

**Re-centred (my decision, same day).** Every bias divider hangs on `vcc`,
so the fix is ratiometric. Each upper resistor was recomputed so that the base
voltage at 4.6 V equals the 5.0 V design value, rounded to E24, and the whole
receiver was re-run. `sim12`, the design reference, now has `V2_S = 4.6` and
these values (schematic and board updated, old values in `.bak_recentre`):

| where | resistors (board) | was | now |
|---|---|---|---|
| IF stage bases b1–b4 and mixer RF base | R10 R11 R16 R19 R21 / R14 R15 R18 R20 R22 | 33k / 12k | **27k / 11k** |
| cascode upper-base rail vb2 | R25 | 8.2k | **6.8k** |
| mixer switch-pair bias vb2n | R63 | 15k | **13k** |
| oscillator base | R1 | 11k | **9.1k** |
| buffer base | R3 | 12k | **11k** |
| LNA base | R9 | 910 | **820** |

Result at 4.6 V: every current-setting stage is within +2.5 % of its 5.0 V design
current (IF cascodes 1.037 mA, mixer 1.504 mA, oscillator +2.3 %); LNA −3 %,
buffer −4 %. I left the audio pair on the RC-filtered `vaud` rail alone at
−10 %, because SIM 13 had already found the audio chain running at twice its
design drive, so a bit less gain there is good. Total draw 40.7 mA. The block-level
simulations (SIM 1–11, 13) still show 5.0 V. They were not re-run, because `sim12`
is the reference and now matches the hardware.

Still open after the audit, all of it needing copper to move (a design pass by AI
agents, then my go-ahead): the four back-side vb2 capacitors (done in step C below); IF tank capacitors 22–31 mm
from their toroids; the promised via-stitching walls; no capacitor at L12's own
pads; the ADC network under the WiFi antenna; BPF/×5/LO loop inductance
pushing trimmers to their 3 pF floor; the 57–72 mm BPF→LNA run; and the
cascade noise figure (6.6–7.8 dB, 8.5–9.9 dB with image noise). The receiver,
not the sky, sets the noise floor.
### Step C — the last parts leave the back side

My rule: no components on the back. The four vb2 decoupling capacitors
placed on B.Cu in September were the only ones there. There was no front-side spot
within 4 mm of the cascode bases without moving something, so the fix is the same
at every stage: **R15/R16/R19/R21 slide 1.25 mm north** (R16/R19/R21
also rotate 180° so the base pad faces west and the b_n trace leaves on a single
45° diagonal). The capacitor sits between resistor and cascode with its vb2 pad
2.4 mm from the base, and one GND via per stage serves both the resistor and the
capacitor. The vcc pass over each stage drops to y = 67.3, so the closest
rail-to-base-pad gap is 0.50 mm instead of 0.30.

The spec came from the audit. An independent adversary (an AI agent whose job is
to try to break a design) recomputed it against the live file. It found three
deletions the spec had forgotten (its new vcc horizontals would have been laid on
top of the old ones, which is exactly the "stitched over one another" look this
pass is meant to remove) and two deletions written in reverse orientation. It also
made the y = 67.3 variant the default, because it costs nothing. Before anything
was written to the file, each of the 48 deletions was checked to match exactly once.

Cost and benefit, measured: the base-to-plane loop goes 3.2 → 4.2 nH (remaining
base impedance 0.14 → 0.22 Ω at 12.9 MHz, ~1 % of the upper device's 1/g_m, so
negligible). In exchange, 8 vias and ~11.6 mm of bottom-layer slots leave the
plane under the 96 dB strip. Board: 753 segments, 183 vias, **0 footprints on
B.Cu**; DRC 12, all silkscreen, 0 unconnected.

Two more tooling traps showed up in this step, both of the same kind.
`R` and `Clear` are PowerShell aliases (`Invoke-History`, `Clear-Host`),
and an alias wins over a function with the same name. So a helper called `R`
never runs, and a placement solver whose test is called `Clear` rejects every
candidate without reporting anything. Also, `[regex]::Replace(s, p, r, 1)` has no
"count" overload: the `1` is `RegexOptions.IgnoreCase`, and it replaces
every match. Applied to a footprint block, it moved every pad onto the footprint
origin. DRC caught it, the file was restored from the pre-edit backup, and the fix
was a string edit that only touches the first match.
### Step D — the IF strip: measure first, then only what the numbers justify

**D1: tanks and risers.** The audit had asked for every tank capacitor,
trimmer and damping resistor to be pulled up to its toroid (they sat 22–31 mm
south, joined by long collector risers), because the risers ran 1.3–2.3 mm from
base nodes. The AI designer agent was told to measure again before designing, and
the numbers had changed. Step C had already put the base resistors' base pads on the
far side of the risers, so the same-stage riser→base coupling was 41–58 fF
(|T| 0.15–0.21), not the 81–119 fF / 0.43 the audit measured. In the remaining
1.85–2.25 mm parallel runs, each riser runs next to the *next* stage's base. Its
tank already drives that base through its tap, in phase, so this is feed-forward,
not a loop. Also, the full "tanks to toroids" pattern turned out to be impossible
on one layer for stages 1–3 (0.2 mm between consecutive toroid courtyards, and each
hot pad is boxed in on the north and east by its own tap line).

Only what the numbers justified was done. Stage 4 has a real free pocket east of
L6 and got the full pattern (c4 53 → 28 mm, tank loop 38 → 10.5 mm). Stage 1's
damping resistor R29 moved away from the injection leg (c1 copper now
≥ 8 mm from b1). The stage 2/3 risers were tucked into the resistor column, which
freed clean 2.55 mm corridors for the walls. Every collector stub now leaves
its SOT-23 along the pad axis, and the trimmer entries are centred. In total: 47
deletions, 32 additions, 4 vias, 4 moves, all reviewed by the adversary first (it
added a track endpoint at the stage-4 trimmer pad, where the spec's bus only
passed through it).

**D2: the walls, finally.** Frozen decision 3 promised via-stitching walls
with exposed copper strips for an optional brass sheet, and the audit found the
stitching was sparse exactly at the stage interfaces. Now they are built: an
east–west wall of 19 ground vias between the IF strip and the audio row (three
collinear runs at y 95.75 / 95.5 / 94.0, ≤ 5 mm pitch), a north–south wall of 10
between the mixer tank T1 and the IF filter T2, and stage-boundary columns of
9 / 8 / 9 vias at x ≈ 149.1 / 162.2 / 174.2. That is 60 new ground vias, each one
checked against **both** copper layers (a via through a bottom-layer signal hop is
a short) and against hole-to-hole spacing. Nine solder-mask openings expose the
ground pour along the walls. Each one was checked to lie on continuous ground and
to stay ≥ 0.5 mm from any signal copper, because a brass strip soldered over
an exposed signal track would short it.

The mixer|IF wall that the audit sketched at x = 117.5 could not be built (a 0.41 mm
corridor). Instead, the mixer-tank hot node was rerouted through the gap between
two toroid pads (51 → 39 mm), so that vcc can drop straight into the tank's
cold pad from the trunk. This also removed one more bottom-layer hop. The
b1 injection leg was also cut from 30 to 15 mm by moving C65 and TP1 next to the
first IF base. Together: **727 segments, 243 vias, bottom-layer exceptions
down to 30 segments / 144.7 mm, nothing on the back, DRC 11 (all silkscreen),
0 unconnected.**

### Step E — front end, LO chain and supply: the last copper pass

This step covered three regions, each with its own independent AI designer agent.
Each design was then reviewed by an adversary agent that recomputed every number
from the file before anything was applied (all three verdicts: sound with
corrections, none blocking). The changes were applied by script in the order
E1 → E2 → E3, with a DRC after each one. Every deletion was checked to match
exactly one existing item, so nothing could be removed by accident.

**E1: RF front end (x 50–96).** The two BPF tank loops were the largest
current loops on the board. The trimmer and 15 pF cap were 22 mm from their coil,
and the return went through the plane hole under the air coils (the keepout
forbids pour on *both* layers, so a via return must go around a 26 × 16 mm
hole). Now the trimmer + 15 pF sit directly south of each coil. A 1.5 mm hot run
drops from the coil's hot pad to the trimmer, and a 1.5 mm ground strap runs
from the trimmer's ground pad back to the coil's cold pad, with one reference
via per tank just outside the keepout. The loop is now a 7 × 6.9 mm rectangle of
1.5 mm strips, ~12.6 nH total (≈ 8.6 nH on top of the coil itself), against 20–25
nH before. Hot-node copper is 9.9 / 9.7 mm (was 32.5 / 29.6), and the stray is
~0.5 pF (was ~1.6). The antenna launch is now one straight 5.45 mm coplanar line,
1.5 mm wide with the pour 0.3 mm on either side (50.8 Ω; 68.9 Ω where there is no
pour), and C23 is turned so its pad faces J1. Before, it was 17.7 mm in seven
segments. The BPF → LNA seam keeps the 50 Ω line and the R65 / J2 test topology.
The J2 launch narrows to 1.0 mm where it enters R65's 1.025 mm pad. The minimum
clearance of all new copper is 0.575 mm. After the refill, the front pour was
confirmed on both sides of the launch (point tests at x 51–55, y 62.6 / 65.4),
broken only by C24's stub at the C23 end.

**Values decided: C23/C27 15p → 8.2p and C24/C28
100p → 56p.** The layout showed a problem. With the real 3–10 pF trimmer,
82 nH coils and the loop's 8.6 nH + 0.5 pF, the trimmer that centres the filter
is 0.7 pF, and a +10 % coil cannot reach 137.9 MHz at any setting. The
designer agents offered two ways out: wind 4-turn coils (~55 nH), or drop the top
tap cap to 10p. Both were run, together with three more options, through the SIM 7
circuit with the layout parasitics, at critical coupling and with ±10 % coils
(`fm_receiver/DESIGN_LOG.md`, SIM 7 rev 2, has the full table). The 4-turn coil
puts the trimmer at 6.8 pF, but it costs 0.7 dB of extra loss before the LNA
(loaded Q rises, and a 4-turn coil has less unloaded Q than the 150 assumed).
It also leaves only 1.3 pF to the top stop for a −10 % coil, and it changes the
winding recipe that the footprint, keepout and coupling spacing were designed
around. 10p over 100p changes the tap ratio to 0.091, and that has a price:
4.1 dB loss and the other Meteor frequency 3 dB down. Scaling *both* tap caps
keeps the ratio (8.2/64.2 = 0.128 against 15/115 = 0.130). So the loaded Q, the
5.5 MHz passband, the 2.2 dB loss and the 40 dB image rejection stay the same as
the rev 1 filter. The divider's series capacitance just falls from 13.0 to 7.15 pF
and gives the difference to the trimmer: **6.7 pF nominal (6.3 pF with the 1 pF of
stray that step F recomputed from the copper widths), 5.6–8.1 pF across ±10 % coils**.
That is at least 1.9 pF from either stop, with 1 pF still in hand if the stray
copper is 1 pF instead of 0.5 (the 10p/68p split, the other option that keeps the
ratio, would sit on the 3 pF floor in that case). sim12 and `sim7_input_bpf.asc`
have 8.2p/56p. Their ideal-netlist trimmer reads ~8.7 pF because the parasitics
are not in the netlist. A second-order note for alignment: the 56 pF tap caps'
ground returns through the plane around the hole (10.6–12.3 mm, ~1.5–2 nH in
series with −j20.6 Ω), so the effective tap-arm capacitance is ~60–61 pF and
the tap ratio is ~0.12 instead of 0.128.

**E2: LO chain (x 84–120).** Both LO tanks became mirror-image "two-rail"
stacks hanging straight off their coil pads, with every part just outside the coil
courtyard. The ×5 trimmer C4 is 7.3 mm from each coil pad (was 12.9 / 13.8),
C3 and R59 bridge the same two rails, and Q4 is turned so its collector points
2.2 mm up the hot rail. xtank1 copper went 35.7 → 15.1 mm, stray 1.96 → 0.85 pF,
and the closed tank loop 24.7 → 17.0 nH. There are two new parts. **C81** (100 nF,
`Cbyp_X`) sits on the ×5 tank's vcc node, so the class-C collector current now
closes in a ~6 × 9 mm loop instead of running 20 mm along vcc (12.4 nH, 9.8 Ω at
125 MHz) into the LNA's decoupling. **C82** (100 nF, `Cbyp_O`) sits where the
oscillator/buffer supply enters. The adversary caught a ground stub drawn 0.2 mm
short of C81's pad (the designer agent used the wrong 0805 pitch). That would have
been one unconnected pad on a supply bypass, and it was fixed before applying.
Minimum clearance is 0.53 mm; bufc grew from 11 to 25 mm (base network, accepted);
vcc's bottom-layer share fell 46.2 → 44.0 mm.

**Values decided: C3 4.7p → 3.3p, C12 8.2p → 5.6p.** The tank totals
that SIM 5/6 tune to (10.8 pF on the ×5 tank, 14 pF over 47 pF at the LO tap)
are what the trimmer is *turned to*, so the simulations do not change. Only
the split between the fixed cap and the trimmer changes, and that split has to
leave the trimmer inside its 3–10 pF window for any coil I actually wind. The
layout adds ~11 nH of coil legs (161 nH effective instead of 150), Q4's ~0.5 pF
Ccb and the 0.85 pF of stray copper measured in E2. Counting all of that, the ×5
tank needs 8.7 pF of external capacitance at 125 MHz. With C3 = 4.7p the trimmer
would sit at 4.0 pF (3.0 pF for a +10 % coil, on the stop). With 3.3p it sits at
5.4 pF, 4.6–6.5 pF across ±10 % coils. At the LO tap the same calculation gives
9.2 pF total through the 47 pF bottom cap, so 11.4 pF for the top arm. With
C12 = 8.2p the trimmer would need 3.2 pF (~2 pF for a +10 % coil, out of reach);
with 5.6p it needs 5.8 pF, 4.6–7.5 pF across ±10 % coils. One consequence for
alignment: the parasitics now supply part of the tank capacitance, so the top arm
at resonance is ~11.4 pF instead of the 14 pF the sim assumes. This makes the LO
tap ratio ~0.195 instead of 0.23, and the mixer sees ~1.4 dB less LO drive than
SIM 8 modelled. That is still inside the 0.1–0.8 V window SIM 8 stepped through.

**E3: power entry, ADC network, IF supply.** L12 is rotated 180°, so EXT_5V
comes straight up from the socket's run and vcc leaves the bead to the west. The
vin5 bottom-layer hop is gone. **C79** (100 nF, `Cbyp_in`, vin5) and **C80**
(100 nF, `Cbyp_L12`, vcc) sit as mirror images on either side of the bead, 2.2 mm
from its pads (4.4 mm apart), each with its own via. The ADC divider (R30, C41, C31, R28) had
been sitting *inside* the WROOM antenna rectangle. It moved to the strip
between the vcc feed and the south edge (two rows, y 120.65 / 123.4). The
`adc` net is now 21 mm, all on the front, the `adc` and `adcref` hops are gone, and
`a_ce` takes a second 3.5 mm hop under the socket instead.

The IF strip's supply was rebuilt around **four new nets, `vcc_if1..4`**. The vcc
trunk at y = 55.5 feeds each stage through an 0805 series part **R66–R69** (0 Ω when
E3 was drawn; **10 Ω since step F**, see there; a 22 Ω or a ferrite bead can
still go in at bring-up without a respin). Each net contains exactly the toroid cold end (L2/L3/L4/L6
pin 1), the bias divider top (R11/R16/R19/R21 pin 1), the stage's two 100 nF
(C66–C73 pin 1) and the series part's pad 2, nothing else. So the per-stage current
flows only through the series part, and the decoupling is downstream of it.
The eight caps moved up to y = 57, straddling their stage taps, with ground stubs at
y = 57.1 into the existing wall vias at x ≈ 149.1 / 162.2 / 174.2. *Straddle
rule:* a series part sitting on the trunk keeps the trunk as one segment, with its
pad 1 placed so the trunk runs inside the pad (centre 0.26 mm north). Centring
it would overlap the toroid courtyard by 0.09 mm. Every cold-pad continuation
was re-drawn as a true 45° piece (the designer agent's were 110–116°). Minimum
clearance is 0.325 mm (C41 vs the adc bus). The cap courtyards are 0.02 mm from the
toroid courtyards, on purpose.

**Keeping the schematic in sync.** The eight new parts (C79–C82, R66–R69) were
added to the schematic by script with their footprint UUIDs linked. The 16
`vcc` labels that became `vcc_if1..4` were renamed by finding the one label on
each pin. A pad-by-pad comparison of the exported schematic netlist against
the board gives 418 nodes, 0 mismatches (the 46 board-only pads are the socket's
unused pins and the toroids' empty tap/link pins). None of the board-only
parts (C66–C82, R66–R69: series resistors and 100 nF bypass) exist in sim12.
They have no effect there and stay on the whitelist. The full list of SimRefs
that do not name a sim12 element (step F count): the board-only parts above,
TP1–TP3, J1–J4, the eleven trimmer halves `*_TR` (sim total = fixed + trimmer),
the bulk/rail caps C62 `C_BULK`, C63 `C_B100`, C64 `C_VA100`, the injection cap
C65 `C_INJ`, the bead L12 `FB_5V`, the link R65 `R_LNK`, and Y1 `Y_XTAL` (the
sim uses the motional model LM_O/CM_O/CP_O/RSX_O); the toroids L1–L4 (`T_FILT2`,
`T_IF1..3`) stand for the coupled pairs La/Lb the sim uses for a tapped coil.
Everything else matches value for value (121 R/L/C, 0 mismatches).

**Silkscreen.** The label solver now knows the board edge, can place a label
vertically, treats the exposed-copper wall strips as obstacles, and searches up to
9.5 mm. Every label found a place except **Q13, Q17 and C77**, which are boxed in
the cascode column between two via walls. Their silk references are hidden (the
fab layer still has them). The `A1=3V3` marker moved above socket pin 1.
D5's anode marker, which had landed on C1 after the diode's 180° turn, was
moved above its pad and the duplicate was removed.

Together: **687 segments, 233 vias, 196 footprints (all front), bottom-layer
exceptions 27 segments / 136.2 mm across 11 nets, DRC 0, 0 unconnected.**
Still left for later: an image-noise trap between LNA and mixer (SIM 7's 39.5 dB is
enough for rev 1).

### Step F — the finished board, verified by strangers, and what it changed

I had the finished files checked by six independent AI verification agents, each
looking through one lens (connectivity and netlist truth; clearance
and manufacturability; RF, impedance and noise; document consistency; ESP32
and mechanical fit; assembly, silkscreen and fab outputs). Each one read the
files with its own parsers. Every finding rated major or above was then given to
two more agents, which were told to disprove it or to judge its consequence.
Result: 41 findings, none critical, for 3.3 M tokens. The checks that passed are as
useful as the defects, so I summarise them first.

**Confirmed clean (numbers recomputed from the files, not from this README):**
one B.Cu plane island (11 839 mm², 87.7 % of the board), zone fills current
(the `.kicad_pro`/`.kicad_dru` must travel with the board, because refilling without
them moves the plane edge by 0.2 mm); 117 nets each one copper component, 0
dangling ends, 0 shorts; every GND pad on its own stub and via (median 1.9 mm);
schematic ↔ board 418 nodes / 0 mismatches, the 46 board-only pads being the
socket's unused pins and the toroids' empty tap/link pins; `vcc_if1..4`
membership exact; 121 R/L/C values identical to sim12; no via in an air-coil
keepout; hole-to-hole ≥ 0.70 mm; copper ≥ 0.30 mm from the edge except inside
the two SMA rule areas; 0 courtyard overlaps; the nine F.Mask ground strips on
continuous ground only; the socket matches the DevKitC V4 38-pin pinout (3V3 /
EN / GPIO36 / GND / 5V on row A pins 1 / 2 / 3 / 14 / 19, GND on row B pin 1;
EN floats safely on the module's own pull-up); gerber, drill and BOM exports
run.

**What was wrong, and the fixes applied:**

- **The LNA emitter bypass was 20 mm from the transistor.** This was the one
  finding that changed the receiver. The "Known constraints" bullet asked for
  RE1/CE2 tight to Q1, but the August routing had C49 at (92,83.8) with 8.1 mm of
  emitter track to R37 and 10.3 mm more to the cap: ~12 nH in series with 3.5 Ω.
  SIM 9 with that inductance gives S21 10.6–11.6 dB instead of 15.75, and an input
  of 66–73 + j27–31 Ω (VSWR 1.7–1.9) instead of 35 − j13. The BPF would have been
  terminated wrongly, and the bench acceptance test of frozen decision 4 could not
  have been passed.
  Fixed: R37 rotated under the emitter at (102.06,78.0), C49 beside it at
  (100.05,77.96) with a new via at (100.05,75.35), R42 moved west to
  (97.3,78.91) with its own via at (96.39,77.3), and the old runs and stubs deleted.
  Emitter-to-plane copper is now 5.2 mm (~4.4 nH with via and ESL), so I expect
  S21 ≈ 14.1 dB and Zin ≈ 47 + j9 Ω. The numbers are in `fm_receiver/DESIGN_LOG.md`,
  SIM 9 layout note.
- **Both SMAs sat with the pad centre on the board edge**, so half of every 5.08 mm
  land was outside the board, and the connector's 4.45 mm legs would have reached
  C24's copper. J1 moved to (52,64) and J2 to (87,52), so the lands end 0.54 mm past
  the edge (JLC's ±0.2 mm outline tolerance never leaves a land short). C24
  moved to (57,67.2) with its via at (57,69.6) and a 45° stub from C23's pad.
  The J1 shell vias sit just past the pad ends at x = 55.0 (first placed at
  54.3, inside the pads, and moved in the re-check below). The SMA footprints'
  silk outlines were removed (they were off the board or over the launch parts),
  and the shell pads now connect solid to both pours (`zone_connect 2`) instead of
  through two half-wrapped vias. Expect a JLC DFM query about copper on the
  board edge at (50, 59–69) and (83–91, 50). The answer is "edge-launch SMA, by design".
- **Clearance floor raised to 0.254 mm** (project rules and Default netclass;
  hole-to-hole 0.5 mm; text stroke 0.15 mm). The eight gaps between 0.20 and
  0.25 mm that the old 0.2 mm rule allowed were cleaned up: the three vb2 vias
  beside R18/R20/R22 moved to (153.9 | 165.9 | 177.9, 73.2) with their hops
  re-anchored, the two vb2n segments past C37/C33 were narrowed to 0.35 mm, the
  lnk_b link route was re-drawn with true 45° jogs at y = 63.6 (0.45 mm to L1's
  pads), and C37's ground via moved to (103,82.4). The board-wide minimum
  different-net gap is now 0.269 mm, and DRC is 0 at the new floor.
- **Same-net notches** (sub-0.1 mm re-entrant gaps at width steps and chamfer
  corners that a fab's DFM flags as slivers) removed at seven places: a single
  straight vcc segment into the via at (116.5,89.3); the blo corner at R56
  re-drawn at 45°; the vcc corner at C63 rerouted from the corner instead of the
  pad; the bb entry at R3 made a pad stub plus a true 45° diagonal; the ef2 and
  vcc chamfers lengthened to 1.1 mm. The three "notches" at pads bridged by a
  narrower piece (R65, C7/C20, C23) are artefacts of the checker, so I left them.
- **R66–R69 fitted as 10 Ω, not 0 Ω.** The four `vcc_if` nets are fed from one
  0.5 mm trunk (0.6 Ω per 12 mm at 12.9 MHz). The reverse path stage-4 tank →
  trunk → stage-1 tank then has a loop gain of about −53 dB when each stage's cap
  pair looks like ~0.025 Ω, but only −10 dB if it were 0.2 Ω (a dry joint, a
  missing cap). With 10 Ω the trunk path no longer matters (−124 dB), and it costs
  only ~10–20 mV per stage, which is inside the ratiometric bias tolerance.
- **Silkscreen.** All 922 footprint silk lines were widened 0.12 → 0.15 mm (JLC's
  legend minimum), and the toroid pin labels "1"/"3" got a 0.15 mm stroke. The
  label solver learned two rules a fab cannot check: a reference may not sit inside
  another part's courtyard, and labels keep 0.3 mm from each other. With that, 62
  labels were re-placed (the IF caps' labels had been printing inside the toroid
  frames as "1 C67 3"; the re-check below found the solver had over-corrected
  and fixed 42 more). References with no legal spot are hidden: **Q13, Q17,
  C77, R16, R19, C78, C43** (the fab layer has them, and the custom toroid and
  air-coil footprints now have a `${REFERENCE}` on F.Fab too). Test-point
  legends added: GND at TP3, AUDIO at TP2, INJ (12.9 MHz injection) at TP1.
- **Fab settings.** Solder-mask expansion 0.05 mm (was 0; smallest mask dam
  left 0.555 mm); drill marks off in the plot parameters (they had put 114
  0.35 mm flashes on the paste and mask layers); assembly drawing:
  `kicad-cli pcb export pdf --layers F.Fab,Dwgs.User,Edge.Cuts`.
- **BOM.** See the sourcing section: MPN/Farnell/Spec fields on the symbols,
  `pcb/fabrication/qfh_receiver_bom.csv` exported from them.
- **Documents.** Frozen decisions 1 and 4, the footprint text (all 0805; the
  3-turn link on L1 and L7 only), the IF-decoupling table, the exceptions
  table (with the measured vb2 crossing inventory), the sourcing tables, the
  step E numeric drifts (LO tap 2 pF, C4 7.3 mm, C79/C80 2.2 mm) and the SimRef
  whitelist were corrected where the files contradicted them.

**Measured, recorded, not changed:**

- The ×5/LO coil pair (7 turns at 10 mm centre spacing) calculates to **k ≈
  0.05**, not the 0.03 the tanks were simulated with, because the coils are longer
  and their ends closer. SIM 5 re-run with K stepped: LO output 9.39 / 9.57 / 9.09 V pp at k =
  0.03 / 0.05 / 0.06 (±0.3 dB), while the ×5 collector swing *drops* 8.7 → 6.9 V
  pp, which means more breakdown margin, not less. The 5-turn BPF pair stays at k ≈
  0.03–0.04. If the LO tank shows a double hump at alignment, I can tilt or spread
  L11 on its legs.
- The WROOM antenna sits ~13 mm above both ground planes (Espressif asks for
  15 mm of clear space) and directly over the a_ce audio line and the vaud
  rail. The ADC parts are 1–4 mm south of its rectangle. This comes with frozen
  decision 6. WiFi stays off while recording, and if I ever want WiFi on during
  operation, a second 8.5 mm socket stack lifts the antenna to ~22 mm.
- Rail sharing with the ESP32: the bead + 1000 µF entry attenuates a 300 mA
  WiFi burst's ~0.2 V sag by only ~6 dB at 1–10 kHz (≈100 mV on vcc, 0.4 %
  of the rail, ~−48 dB AM-equivalent at the detector, a further −36 dB through
  the audio rail's RC). Fallback if a recording with a busy CPU shows kHz ripple:
  a low-ESR 1000 µF at C62.
- The four vb2 hops (27.9 mm) are still the only bottom copper under the IF strip
  (measured as feed-forward only, see the exceptions table). The n_rf2 hop (23.3
  mm, LNA → mixer) passes under two ground stubs whose return current goes
  around the slot. That is acceptable: one hop instead of five.
- BPF hot-node stray recomputed from the copper widths is 0.9–1.0 pF, not
  0.5 pF, so the trimmer nominal is 6.3 pF instead of 6.7, still ≥ 2 pF from either stop.
- No mounting holes (my decision). The board rests on adhesive standoffs
  or an edge-supported tray, and the micro-USB cable at x ≈ 229 needs strain
  relief at the enclosure, otherwise the socket pins would carry the lever load.
- The trimmer-position tables of the sourcing pass and the 37.6 dB of SIM 7
  rev 1 are kept as history. The current expectations are in "Known
  constraints".

**The re-check (26 September).** The AI agents that were supposed to review the
fixes above stopped on a spend limit, so at first the fixes were checked only by
the fix author's own scripts. Then one more independent AI agent recomputed every
changed area with its own parser and kicad-cli on copies. Its verdict: *ready with
minor fixes*. It confirmed with its own numbers: every net is one component; the
LNA emitter copper is 5.21 mm, with S21 **14.12 dB** at 4.4 nH in its own SIM 9 run
(15.75 at 0 nH, 10.71 at the old 12 nH); SMA lands 0.54 mm past the edge, legs
≥ 1.3 mm from foreign copper, shells joined to both refilled pours; board-wide
minimum different-net gap 0.269 mm; mask webs ≥ 0.555 mm; board, schematic and
sim12 values agree on every SimRef. What it found, and the fixes:

- **The BOM file was out of date.** It was exported before R66–R69 went to 10 Ω,
  so it would have bought 0 Ω links. Re-exported (and R49 is now 270 Ω, see below).
- **Labels.** The courtyard-aware solver had pushed 19 references 2.8–7.5 mm
  away from their parts (with another part nearer), six were still inside a coil or
  toroid outline (C7, C20, C4, C13, R15, C19), and three were off the board (R28,
  C31, J4). 35 were re-placed at the checker's positions. The four that its own
  positions made collide (R33/C19, C44 and R8 over a wall mask strip), plus three
  more found by a final audit (C18, C24, Q14), were placed by a nearest-legal-spot
  search. An audit of all 189 visible labels found none centred inside another
  part's outline, none with another part clearly nearer, and none off the board.
- **Solder wicking at J1:** the shell vias at x = 54.3 had their drills inside
  the exposed shell pads, under the leg tips. Moved to (55.0, 59.75 / 68.25),
  0.26 mm clear of the pad. J2 (DNP) has the same geometry, so move its vias to
  y = 55.0 if it is ever fitted.
- **Two re-drawn corners were not 45°** (37.7° and 43.6° vcc diagonals at
  (116.5,89.3) and (220.05,89.5)): re-drawn as true 45° pieces.

**R49 (RE4A) 150 → 270 Ω.** The TODO's "2× audio overdrive, raise RE4A to
330 Ω" turned out to be out of date, because SIM 2 rev 3b had already fixed that
in August. But at the real 4.6 V rail, Q4 came within 0.43 V of saturation at the
high end of the detector's level range. 270 Ω doubles the headroom (≥ 0.92 V worst
case) and keeps ≥ 380 ADC counts at the lowest drive. The full table is in
`fm_receiver/DESIGN_LOG.md` under SIM 13. SIM 13 re-run with 270 Ω: THD 1.1 / 1.8 %, 0.45 Vpp at the ADC.

**State after step F and its re-check: 683 segments, 235 vias, 196 footprints
(all front), bottom-layer exceptions 27 segments / 136.5 mm on 11 nets, DRC 0
at a 0.254 mm clearance floor, 0 unconnected, schematic ↔ board 418 nodes /
0 mismatches, every pad angle matching its library footprint.** Next: gerbers.

## Attribution

This board is my project: I set the requirements and the layout rules, and I
approved every change. I will assemble, align and measure it myself. I used
Claude (Anthropic) as an AI assistant for the KiCad work: following my
requirements and reviews, it did most of the placement and routing by script,
ran the design checks and did independent review passes, as described in the
sections above. The motivation for the project is in the receiver README.

Edy Grigore

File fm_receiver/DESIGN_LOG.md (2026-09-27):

# Discrete FM receiver for 137.9 MHz weather-satellite signals

> This is the complete, step-by-step design log of the receiver, kept as I wrote it along the way. For the short overview, start with [README.md](README.md).

This is the receiver half of my weather-satellite project. The antenna half (a
QFH antenna with a MATLAB design toolchain) is in [`../qfh_matlab`](../qfh_matlab).

**Goal:** an analog superheterodyne receiver for the 137.9 MHz weather-satellite
band, built **entirely from discrete parts**: transistors, diodes and LC
networks, with no ICs in the signal path. The demodulated audio is in NOAA APT
format. The NOAA satellites were decommissioned in 2025, so I play recordings
back through an ADALM-Pluto. A microcontroller ADC digitizes the audio and
software decodes it into an image.

**Constraints:** a student budget (~30–45 EUR of parts). The "no ICs" rule is on
purpose, because I want to learn every stage at component level. Test gear:
miniVNA Tiny, ADALM-Pluto (signal source / spectrum check), a homemade RF probe,
and sometimes access to the university RF lab (spectrum analyzer, calibrated
FM generator, noise-figure meter).
> **Supply-rail caveat (September 2026).** Every block simulation below
> (SIM 1–11, SIM 13) was run at **5.0 V**. The hardware rail is **4.6 V**,
> because the ESP32-DevKitC feeds its 5V pin through a BAT760 Schottky. `sim12`,
> the design authority, has been re-centred for that rail (bias dividers recomputed,
> all stages back within +2.5 % of their design currents, 40.7 mA total). So
> read the block-sim numbers as topology and behaviour, not as the exact
> operating point of the built board. The real numbers are in `sim12`. Details
> are in "The supply rail" section and in `../pcb/DESIGN_LOG.md`.

## Motivation

In my first year of Electrical Engineering at the University of Twente, the
Module 4 project was to design an antenna and a transmitter PCB. I really
enjoyed that field, together with the courses that went with it: High Frequency
Electronics, and Electromagnetostatics and Electrodynamics. After the module I
wanted to go deeper than the project allowed, so I decided to design my own
antenna and my own receiver for the 137 MHz weather satellites.

I wanted to do everything analog, without any integrated circuits in the signal
path. That way I have to understand every stage at component level, instead of
letting a chip do the work for me.

The plan had to change along the way. The NOAA satellites whose analog APT
signal this receiver was designed for were switched off in 2025, and the
Meteor-M satellites that are still up send a digital signal that an analog FM
receiver cannot decode. So I test the two halves separately: the antenna with
an SDR on the Meteor-M satellites, and the receiver (once it is built) with
recorded NOAA passes played back into it through an ADALM-Pluto.

The next step is to close the loop with my own hardware on both ends. I want to
build a second QFH antenna and a transmitter, which should be easier than the
receiver, and send information between the two stations with frequency
modulation, using my own PCBs and my own antennas at both ends. That link has
to run on a frequency I'm allowed to transmit on, because 137 MHz is
receive-only for me.

## Architecture

```
antenna ──► ESD ──► BPF 137.9 ──► LNA ──► mixer ──► IF filter ──► IF amp (~75 dB)
(or Pluto            LC, image    1x BF998/  ▲        12.9 MHz         │
 + attenuator)       rejection    BFR93A     │                         ▼
                                        LO 125 MHz               limiter ──► slope
                                        (25 MHz crystal                      detector
                                         oscillator + x5                        │
                                         multiplier)                            ▼
                                                            ESP32 ADC ◄── LPF + scaling
```

## Frequency plan

| Parameter | Value | Why |
|---|---|---|
| RF input | 137.9 MHz | Meteor-M / NOAA band |
| Crystal | 25 MHz | cheap, standard |
| LO | 125 MHz (25 × 5) | low-side injection |
| **IF** | **12.9 MHz** | 137.9 − 125 |
| Image | 112.1 MHz | falls in the quiet gap between FM broadcast (<108) and airband (>118), so it is easy to filter |
| FM deviation | ±17 kHz | APT specification |
| APT subcarrier | 2400 Hz AM | image brightness = subcarrier envelope |
| ADC sampling | 44.1 kHz, decimated in software | lets a cheap 3-pole anti-alias filter work |

I picked this exact plan because of the image frequency. With a 12.9 MHz IF the
image lands at 112.1 MHz, where nothing strong transmits, so a simple
2-resonator input filter is enough to reject it.

## Stages

1. **ESD protection**: antiparallel small-signal diodes + choke. It bleeds
   static from the antenna and is invisible at signal levels.
2. **Band-pass filter 137.9 MHz**: two coupled LC resonators. It rejects FM
   broadcast, airband, and most of all the 112.1 MHz image (target ≥30 dB).
3. **LNA**: one VHF transistor (BF998 dual-gate MOSFET or BFR93A). It sets the
   noise figure of the whole receiver, ~18 dB gain. Gate 2 of a dual-gate
   device can later also be the AGC control point.
4. **Mixer**: dual-gate MOSFET (RF on G1, LO on G2). It gives conversion
   *gain* (+10…15 dB) and needs only a few hundred mV of LO. Fallback: 4-diode
   double-balanced mixer (better linearity, −6 dB loss, needs +7 dBm LO).
5. **Local oscillator**: 25 MHz crystal Colpitts oscillator, then one
   class-C stage multiplying ×5, with the output tank tuned to 125 MHz. A
   crystal + multiplier replaces a PLL synthesizer. The stability is the same
   (the crystal sets it), and there is no programmable divider, which is the
   one block that cannot be built without ICs. We only need a single fixed
   frequency, so nothing is lost.
6. **IF filter**: 2–3 coupled LC resonators at 12.9 MHz. With practical LC
   values the realistic bandwidth is 100–200 kHz, not the ideal 40 kHz (that
   would need Q≈320). This costs ~5–7 dB of sensitivity, which is fine for v1.
7. **IF amplifier**: three tuned stages, ~25 dB each. The layout (ground
   plane, shielding between stages, per-stage supply decoupling) decides
   whether this is an amplifier or an oscillator. Simulation cannot check
   that part.
8. **Limiter**: antiparallel diodes clipping the last IF stage. It removes AM
   so the detector responds to frequency only. (This is safe for APT: the
   image information is *inside* the FM modulation and appears only after
   demodulation.)
9. **Slope detector**: the FM demodulator, and the part of the project I learn
   the most from. It is a tank detuned from the carrier on purpose, so the
   signal sits on the flank of the resonance curve. Frequency deviation →
   amplitude variation → a Schottky envelope detector recovers the audio.
10. **Audio LPF + scaling**: 3-pole low-pass (~6 kHz), DC offset and level
    matching into the ADC range, buffered by an emitter follower.

## Simulation roadmap (LTspice)

I ordered the simulations by *what they unblock*, not by build order. For
example, the detector defines the IF gain requirement and the multiplier
defines the mixer drive. I trust LTspice for topology, filters and audio. I do
**not** trust it for VHF gain figures, noise figure or stability, because
layout parasitics dominate at 137 MHz. Those get checked on the bench with the
miniVNA, an RF probe and the Pluto.

| # | File | What it proves | Status |
|---|---|---|---|
| 0 | `slope_tank_test.asc` | tank resonance sanity + schematic-generation test | ✔ passed (peak −6 dB @ 12.9 MHz, Q≈62, phase zero-crossing at resonance) |
| 1a | `sim1a_slope_scurve.asc` | detector S-curve, optimum detune, linearity window | ✔ closed (rev 5): peak 520.9 mV @ 12.95 MHz, carrier at 83 % of peak |
| 1b | `sim1b_slope_demod.asc` | actual FM→audio demodulation, recovered level + THD | ✔ closed (rev 4): ~60 mVpp of 2400 Hz, in-band THD 0.78 % |
| 1c | `sim1c_debug_dc.asc` | A/B debug: modulated vs unmodulated carrier | ✔ did its job: showed the modulation was not the problem |
| 1d | `sim1d_timestep_check.asc` | solver timestep convergence ladder | ✔ 5n/2n/1n/0.5n study; 1 ns adopted as the standard step |
| 2a | `sim2a_audio_freq.asc` (audio LPF) | anti-alias shape ahead of the ADC | ✔ closed (rev 3b): passband flat to **0.70 dB**, **45.7 dB** down at 22 kHz, 171 dB down at the IF |
| 2b | `sim2b_audio_thd.asc` (levels, bias, ESP32 interface) | DC ladder, ADC drive, distortion | ✔ closed (rev 3b): **1.02 Vpp on 1.26 V** (the ADC's linear window), in-band **THD 1.6 %** (1.45 % in situ, SIM 13), pedestal disturbed by **1.3 mV** |
| 3 | `sim3_if_filter.asc` (IF filter) | achievable bandwidth and shape at 12.9 MHz | ✔ closed: **200.5 kHz** at critical coupling (hand calculation said 201), −27.9 dB at ±500 kHz, −39.9 dB at ±1 MHz |
| 4a | `sim4a_if_gain.asc` (IF amplifier chain) | gain, bandwidth, stability margin | ✔ closed (rev 3: **four** cascode stages, **5 V**): **95.8 dB**, 164 kHz, peak exactly 12.9 MHz, stages within 1.2 dB |
| 4b | `sim4b_if_limiting.asc` (chain + limiter) | does the output stop following the input? | ✔ closed (rev 3): **+20 dB in → +1.6 dB out**, 2.51 Vpp delivered, limiting from ~22 µV |
| 5 | `sim5_multiplier_x5.asc` (×5 multiplier) | 5th-harmonic level, rejection of ×4/×6 | ✔ closed (rev 4, **5 V**): topology validated (magnetic coupling, H4 −36.7 dB, H6 −42.1 dB); absolute H5 figure superseded by the settled SIM 5b curve |
| 5b | `sim5b_multiplier_drive.asc` (multiplier drive robustness) | settled H5 vs realistic (330 Ω) drive | ✔ closed (rev 3, **5 V**): cliff unmoved, nominal H5 **1.68 V**, −20 % corner 1.02 V = 3.4× the mixer's need, **no saturation** (collector min 3.33 V) |
| 6 | `sim6_xtal_oscillator.asc` (25 MHz crystal oscillator) | startup, amplitude limiting, frequency | ✔ closed (rev 2, **5 V**): starts from the `.ic` kick, limits at **409.7 mVpp** (bit-stable between spaced windows), 25 MHz dominant |
| 6b | `sim6b_osc_buffer.asc` (oscillator buffer/driver) | drive for the multiplier, crystal isolation | ✔ closed (rev 3, **5 V**): **2.33 Vpp** into the replica load, cliff margin intact, no added clipping, oscillator untouched |
| 7 | `sim7_input_bpf.asc` (input BPF) | image rejection at 112.1 MHz | ✔ closed: **37.6 dB** image rejection, 6 MHz passband, 2.2 dB insertion loss, 50 Ω/50 Ω so it is miniVNA-measurable. **Rev 2 (Sept 2026):** tap caps 15p/100p → **8.2p/56p** (same 0.128 ratio; trimmer ~8.7 pF in the ideal netlist, ~6.5 pF on the board): 39.5 dB image rejection, 6.1 MHz passband, 2.4 dB insertion loss, so within 0.2 dB / 0.1 MHz of the rev 1 curve |
| 8 | `sim8_mixer.asc` (mixer) | conversion gain, LO drive plateau, image response | ✔ closed (rev 2, **5 V**): **22.8 dB** conversion gain, flat for LO ≥ 0.4 V, image converts within 0.04 dB of the wanted signal |
| 9 | `sim9_lna.asc` (LNA) | 50 Ω match and gain ahead of the mixer | ✔ closed (rev 2, **5 V**): **S21 15.8 dB**, Zin 38 Ω (VSWR 1.31), flat and monotonic to 1 GHz |
| 10 | `sim10_limiter_detector.asc` (integration: limiter → detector) | does the S-curve survive the real 100k/clamp source? | ✔ closed: **peak still exactly 12.95 MHz** with a physical 33k coupling resistor, so the C1 alignment target survives; carrier lands on a 1.96 mV/kHz linear flank |
| 11 | `sim11_mixer_filter_if.asc` (integration: mixer → IF filter → first IF stage) | interface gain, in-situ selectivity, tap sizing | ✔ closed: **+20.6 dB** measured to the first IF base (4 dB above the composed paper figure), −29.6 dB at ±500 kHz, tap re-sized 20 % → **13/27**, all biases untouched |
| 12 | `sim12_full_receiver.asc` (**the full receiver**) | one master schematic, every bias network on one rail (5.0 V originally; **4.6 V since Sept 2026**, dividers re-centred) | ✔ closed: `.op` verified, every node matches its block sim (cascode mid-nodes to **6 digits**), total draw **40.7 mA / 187 mW at 4.6 V** (41.6 mA / 208 mW at the original 5.0 V) |
| 13 | `sim13_fm_endtoend.asc` (**FM in, audio out**) | a true APT FM signal through IF chain → limiter → detector → audio → ADC | ✔ closed: **20 dB of input change → 0.5 dB at the detector**, 2400 Hz at the ADC; found the signal-acquisition transient and a 2× audio overdrive (fixed in SIM 2 rev 3b; Sept 2026: RE4A 150 → **270 Ω** for headroom on the real 4.6 V rail, giving THD **1.1 / 1.8 %** and **0.45 Vpp** at the ADC) |

## SIM 1 — slope detector

**Design math (final values, rev 5).** Tank: L = 2.2 µH, **C1 = 66.7 pF**.
The detector diode really adds **~1.9 pF** on top (its junction capacitance,
seen through the envelope cap acting as RF ground), so the tank lands at
**f₀ = 12.95 MHz**. That is ~55 kHz *above* the 12.9 MHz carrier on purpose:
it is the maximum-slope point of the flank for the measured loaded
**Q ≈ 80** (optimum detune = f₀/(2√2·Q)). Z₀ = √(L/C) ≈ 179 Ω. The measured
slope is ≈ 1.7 µV/Hz at the detector output with 1 V drive, so the ±17 kHz
APT deviation gives ~60 mVpp of recovered 2400 Hz audio on a ~0.23 V DC
pedestal.

Envelope detector: 1N5711-class Schottky (low junction capacitance, ~2 pF;
model included inline as `DSCH`), R = 220 kΩ, C = 47 pF → τ = 10.3 µs. That is
≫ the 77 ns carrier period (ripple ~2 mVpp) and ≪ 35 µs, so it tracks the
4.4 kHz envelope without diagonal clipping (worst-case required slew 0.7 V/ms
vs ~19 V/ms available).

**What the first run caught (why rev 2 exists).** The very first S-curve came
out monotonically falling instead of peaking at 12.95 MHz. The tank resonance
had been pushed ~200 kHz low. The cause: the detector diode's junction
capacitance (~2.2 pF) sits directly on the tank node. Behind the diode, the
envelope capacitor is almost a short at 12.9 MHz, so the tank sees the full
Cj. The fix is the same as on a real bench: **tune the tank with the detector
connected**. Here that means C1 goes 68.7 pF → 66.5 pF. Rev 2 also steps a
second measurement (`Vtank`, the true tank amplitude) next to `Vdet`, so tank
problems and detector-efficiency problems cannot be mixed up again. CE also
went 22 pF → 47 pF to cut the carrier ripple ~4×. This is exactly what the
simulation is *for*. Making this mistake on copper would have cost me an
evening of confused trimming.

**What the timestep study caught (why rev 4/5 exist).** The rev-2/3 runs used
a maxstep of 5 ns, close to the LTspice default (~15 points per 12.9 MHz
carrier cycle). The numbers looked fine but were wrong: 412 mV on the tank
where the converged answer is ~200 mV. They even agreed perfectly with the
simple R_in = R/2 textbook model, because both made the same optimistic
error. A convergence ladder (5n → 2n → 1n → 0.5n gave 412/224/204/199 mV)
settled on **maxstep = 1 ns** as the standard step. The diode current shows
why it needs such a small step: ~24 µA RMS of *displacement* current flows
through its nonlinear junction capacitance, against only ~0.3 µA of average
rectified current. At 12.9 MHz this diode is first a ~2 pF nonlinear
capacitor and only second a rectifier. I took two rules from this. First,
**never trim a design against an unconverged simulation**. An early
"measured 3.3 pF" diode contribution was a timestep artifact, and it sent one
whole retune iteration the wrong way. Second, **`.options plotwinsize=0` in
every measurement deck**, because LTspice's lossy waveform compression clips
`.meas` results on RF nodes without any warning.

**Final results (converged, rev 5):** S-curve peak **520.9 mV at
12.95 MHz** (transfer 0.52 from a 1 V source through 33 kΩ; at full drive the
detector loads the tank only lightly). The carrier sits at 83 % of peak on the
straight part of the flank. Recovered audio is **~60 mVpp** of 2400 Hz, with
**in-band THD 0.78 %**. The early detuned runs gave 4.7 %, which shows
directly why the carrier must sit on the linear part of the slope. The
requirement this hands to the IF chain (SIM 4): the limiter must deliver
**≥ 1 V amplitude** into the detector tank.

**Pass criteria**

| Criterion | Target |
|---|---|
| S-curve linear window | ±17 kHz around 12.9 MHz within ~±10% of a straight line |
| Recovered 2400 Hz | ≥ 50 mVpp |
| THD @ 2400 Hz | < 5 % **in-band**. Read LTspice's *Partial* THD figure. The *Total* figure also counts the residual 12.9 MHz ripple (first run: partial 4.5 %, total 257 %!), which the stage-10 audio LPF removes anyway |

**How to run**

- `sim1a`: Run, then *View → SPICE Error Log → right-click → Plot .step'ed
  .meas data*. This plots detected DC (`Vdet`) vs carrier frequency, which is
  the S-curve.
- `sim1b`: Run, plot `V(audio)`. You should see a 2400 Hz sine on a DC
  pedestal. THD is at the bottom of the SPICE Error Log.

## SIM 2 — audio filter and ADC scaling

**What this block is for.** The detector hands over ~60 mVpp of 2400 Hz on a
0.23 V pedestal, behind ~150 kΩ. That is the APT subcarrier, and *its
amplitude is the picture*. The ESP32 samples this audio at 44.1 kHz and
software turns the envelope into pixels. So the block has two jobs:
anti-alias filtering before that sampler, and enough gain to use the ADC's
range.

**Why active filtering.** APT occupies 320–4480 Hz (2400 Hz subcarrier ±
the 2080 Hz pixel rate) and Nyquist for 44.1 kHz is 22 kHz. Three cascaded
passive RC poles reach only ~20 dB there. Two Sallen-Key sections give a
4th-order Butterworth: **45 dB at 22 kHz** with 0.63 dB of passband ripple,
for two transistors.

**Why a Darlington, and why PNP.** The detector's 150 kΩ source impedance is
very high. A single transistor's base current through it would shift the
detector's own operating point by ~0.3 V. That moves the carrier off the
straight part of the slope and ruins SIM 1's linearity, three blocks upstream
of where the symptom would show up. Measured pedestal shift with the
Darlington: **1.7 mV**. PNP because the chain is DC-coupled end to end. A PNP
follower shifts the level *up* by one V_BE and an NPN shifts it *down*.
Alternating them keeps every stage biased inside one 5 V rail, with no
coupling capacitors and no negative supply.

**A bias subtlety.** The first hand calculation assumed 0.70 V per junction
and predicted 0.23 → 1.63 → 0.93 → 1.63 V. That was wrong, because
V_BE = V_T·ln(I_C/I_S) and **the first Darlington transistor carries only the
second one's base current**. That is about 2 µA, which gives V_BE ≈ 0.50 V
instead of 0.64 V at 0.46 mA. So the Darlington shift is +1.13 V, not +1.30 V.
Measured ladder: **0.232 → 1.364 → 0.744 → 1.412 V**, which matches the
corrected prediction to a few millivolts.

**Results:**

| | measured | target |
|---|---|---|
| passband ripple 400–4400 Hz | 0.63 dB | < 1 dB |
| rejection at 22 kHz | 45.3 dB | ≥ 30 dB |
| rejection at 12.9 MHz | 172.6 dB | — |
| output | 1.51 Vpp on 1.643 V | 1.3–1.8 Vpp at 1.65 V |
| in-band THD at 2400 Hz | 3.77 % | < 5 % |

The first run came out with 1.63 dB of passband tilt and 54 dB of rejection.
So I moved the corner from 5.4 to 6.6 kHz (C1/C2/C3/C4 → 2.7n/2.2n/8.2n/1.2n,
all E12), **trading 9 dB of surplus rejection for 1 dB of flatness**. This was
worth it. The tilt weakens the subcarrier's upper sideband compared to the
lower one, which softens the finest picture detail, and 45 dB at Nyquist is
still far more than the sampler needs.

The distortion is mostly second harmonic (H2 3.76 %, H3 0.21 %, rest below
0.005 %). It is asymmetric, which is the typical sign of r_e modulation in the
common-emitter gain stage, the same source the design notes named. `RE4B` was
set to 2.7 kΩ instead of 3.3 kΩ after a review that ran the circuit. It
centres the collector at 3.23 V instead of 3.69 V on the 6 V rail and drops
THD from 4.66 % to 3.77 % at no cost.

**Without the gain stage the ADC would see 60 mV out of 3.3 V, which is about
six effective bits.** With it, 1.5 Vpp: half the range, with headroom for a
stronger pass.

### SIM 2 rev 3 — the ESP32 module interface

The receiver feeds an **ESP32 development module**, not a bare chip. It has USB
power and a programming port, it is easy to buy, and it also works as the
debug console during alignment. That choice affects the audio chain in three
ways.

**The ADC cannot be driven by a 23.5 kΩ divider.** The ESP32's SAR ADC wants a
source below ~10 kΩ. With the old 47k/47k and CADC 470 pF, the pin charged
with τ = 11 µs against a 22.7 µs sample period. That is only two time
constants, so there is a sample-dependent error that lands directly on
picture brightness. Also, the old 1.5 Vpp on a 1.65 V pedestal peaked at
2.4 V, right against the ESP32 ADC's nonlinear region above ~2.45 V. New
divider **10 kΩ / 6.2 kΩ**: pedestal 1.26 V, swing inside 0.5–2.0 V (the
linear part), source impedance 3.8 kΩ. As a side effect, supply rejection at
the ADC improved from 70 % to 28 %. `CADC` 470 pF → 2.2 nF gives the SAR a
real charge reservoir.

**The module's 5 V pin is USB VBUS.** It carries laptop switching noise plus
the ESP32's own 250–500 mA WiFi bursts through the cable resistance: tens to
hundreds of mV, with content in the audio band. This topology has poor supply
rejection (ripple reaches the gain stage's collector straight through `RC4`),
so it now has its own rail: **RSUP 100 Ω + CSUP 100 µF**. That is a 16 Hz
corner, giving −43 dB at 2400 Hz for 0.14 V of drop at the 1.4 mA this chain
draws. On the board, put 100 nF in parallel with CSUP, and keep WiFi off
during a pass: record first, transmit afterwards.

**Rev 3b: the operating point, after the rev 3 run measured 7.5 % THD.**
The numbers show what happened. With 120 mVpp in and r_e = 86 Ω against 150 Ω
of degeneration, v_BE swung ±22 mV against a 25.8 mV V_T. The emitter current
was modulated ±85 %, so r_e itself swung between 47 and 577 Ω. H2 at 7.46 %
against H3 at 0.78 % confirmed r_e modulation rather than clipping. It helps
to look at what that actually costs. **The picture lives in the *envelope* of
the 2400 Hz subcarrier**, and H2 at 4800 Hz is outside the envelope band. So
the metric that matters is gain compression: 10.17 small-signal against 9.83
large-signal, 3.3 % at full white, which the APT calibration wedge corrects
anyway. That was usable, but the operating point had become tight (V_CE fell
to 0.46 V on negative peaks). So I changed two resistors to get both margin
and linearity: **RC4 10 kΩ → 3.3 kΩ and RE4B 2.7 kΩ → 820 Ω**. Stage current
rises 0.30 → 0.85 mA, r_e falls 86 → 30 Ω, the v_BE swing halves to 0.4 V_T,
and **in-band THD drops to 1.4–1.6 %** (1.45 % in situ in SIM 13, 1.58 %
standalone). That is five to six times better.

**A measurement mistake from the same run.** The output landed at 0.75 Vpp
when the arithmetic said 1.17. The gap was a *reading* error, not a circuit
error. The detector's 124 mVpp includes the residual 12.9 MHz carrier ripple
(the thick band you can see on the plot). The true 2400 Hz content is
~89 mVpp, and the audio chain then delivers exactly its designed 8.5×. So
always separate the wanted spectral line from the raw peak-to-peak. The
`.four` fundamental is the number to trust.

And 0.75 Vpp is the right level, not too little. Against a 3.3 V full scale it
is **931 ADC counts**, and APT needs only 64–256 grey levels. Giving up half
the amplitude for six times the linearity is the right trade when the
amplitude *is* the picture.

### SIM 2 rev 2 — back to 5 V

A bit ironic: the original `.cir` decks *were* 5 V. The `.asc` conversion
took 6 V from the rest of the receiver, and now the rail is back. Only V2
changes. The DC-coupled ladder is anchored to the detector's pedestal through
junction drops and never sees the rail. One thing I kept on purpose: **RE4B
stays 2.7 kΩ** instead of going back to the `.cir`'s 3.3 kΩ. The THD is
dominated by r_e modulation and falls with bias current, and Q4 still has
1.3 V of room downwards for a 0.76 V swing. Measured on 5 V: ladder
0.231 → 1.351 → 0.731 → 1.386 V (each 12–26 mV below the 6 V run, only
because of the smaller V_BE at the follower currents), pedestal shift down to
**1.3 mV**, Q4 collector at 2.313 V, output **1.48 Vpp on 1.643 V** (the 1.643
comes from the ESP32's 3.3 V rail and does not depend on VCC), ripple
0.69 dB, 45.6 dB at 22 kHz, in-band **THD 3.89 %** (H2 3.88, H3 0.21). That is
0.12 points more than at 6 V, which supports the RE4B choice.

## SIM 3 — the IF filter

**Circuit.** Two identical tanks (2.2 µH ∥ 69.2 pF, Z₀ = 178 Ω) at 12.9 MHz,
joined **only** by mutual inductance. There is no galvanic path at all, for
the reason SIM 5 taught me. Each tank is loaded to Q ≈ 91 by 33 kΩ. On tank 1
that is the mixer drain's own output resistance. On tank 2 it is the first IF
stage **tapped down**: a 2N3904-class base at 2 mA is only ~1.3 kΩ, so it
connects at ~20 % of the turns and 1.3 k/0.2² = 33 kΩ appears across the
tank. Coil Q_unloaded ≈ 178, modelled as Rser = 1 Ω. *(The 20 % tap figure
was replaced later, at integration. SIM 11 measured the real cascode input
at ~6.1 kΩ and re-sized the build tap to **13/27**. The 33 kΩ loading this
file assumes is still valid.)*

**Why so wide.** APT occupies ~43 kHz (Carson), but I made the passband
~200 kHz on purpose. It has to cover the Doppler that is in the recording
(±3.5 kHz), crystal tolerance and alignment error, and a slope detector needs
the whole FM spectrum undistorted. The filter's real jobs here are to limit
the noise bandwidth ahead of 75 dB of IF gain, and to keep that gain in-band
so the chain stays stable.

**Results (k stepped through all three coupling regimes):**

| k | regime | BW (−3 dB) | peak | tank 1 vs output |
|---|---|---|---|---|
| 0.005 | undercoupled | 114.5 kHz | −14.67 dB | −7.8 / −14.7 dB |
| **0.011** | **critical** | **200.5 kHz** | **−12.20 dB** | **−12.196 / −12.197 dB** |
| 0.022 | overcoupled | 373.4 kHz | −12.12 dB (2 dB dip) | −20.1 / −14.1 dB |

Two theory checks came out exact. **Bandwidth**: √2·f₀/Q predicted 201 kHz,
and the simulation gave 200.5. **Insertion loss**: (1 − Q_L/Q_U)² predicted
6.2 dB above the 6 dB a lossless matched network would show, and the measured
value was 6.2 dB. Also, at critical coupling the two tanks carry **identical
amplitude** (−12.196 vs −12.197 dB). That is the physical sign of maximum
power transfer, and here it shows up directly in the numbers. Skirts:
−27.9 dB at ±500 kHz, −39.9 dB at ±1 MHz, symmetric to 0.03 dB.

**Bench recipe.** With N = 27 turns, a link of n turns gives k ≈ (n/N)², so
**2 / 3 / 4 turns land almost exactly on the three curves above**. Wind
3 turns for critical coupling, and remove one if the response comes out
double-humped. So the simulation also gave me the winding instructions.

## SIM 4 — the IF amplifier and limiter

**What it has to deliver.** SIM 1 set the requirement: **≥ 1 V into the
detector tank**. Three tuned stages at 12.9 MHz, then a diode limiter.

**Rev 1 looked fine, but it was not.** Three single-transistor common-emitter
stages gave 87 dB at 12.9 MHz, but three measurements showed the problem:

- the base voltage rose **above** the source voltage (+10 dB). No passive
  network can do that, so energy was coming back from the collector.
- the −3 dB bandwidth collapsed to **51 kHz** against a natural ~200 kHz.
  Aligning tanks that are already close cannot narrow a response. Only
  Q-multiplication can do that. Factor 4 → feedback loop gain ≈ 0.75.
- changing one capacitor by 1.5 % moved the bandwidth by 2.5×.

So this was an amplifier three quarters of the way to oscillation, even in a
simulation with no board capacitance and no coil-to-coil coupling. The
real board would have added the rest. The cause was Miller feedback through
the 0.7 pF base-collector capacitance, multiplied by the ~33× gain at the
collector.

**Rev 2: cascode.** Each stage became two transistors. The lower one
(common emitter) drives the **emitter** of the upper one (common base), which
is an impedance of only 1/gm ≈ 26 Ω. So the lower collector barely moves. Its
voltage gain is ~1 instead of ~33, and its Miller capacitance is 1.4 pF
instead of 23 pF. The upper transistor has the voltage gain, but its base is
grounded for signal, so its own feedback capacitance lands on a bypassed bias
node instead of the input.

A **BF998 dual-gate MOSFET is exactly this**: two devices stacked in one
package, with gate 2 as the upper base. So the topology maps straight onto
that part if I prefer it on the board. Here I built it on purpose from the
transistors already in the BOM and the **same `QRF` model used everywhere
else in this project**. That way the improvement comes from the topology, not
from a hand-written model with a too-good number in it.

**Results (rev 2):**

| | rev 1 | rev 2 (cascode) |
|---|---|---|
| base voltage vs source | +4.1 dB | **−1.2 dB** |
| −3 dB bandwidth | 51 kHz | **236 kHz** |
| gain | 79.8 dB (inflated by regeneration) | **70.5 dB real** |
| gain per stage | 21.3 / 22.0 / 32.4 dB | **23.1 / 23.1 / 24.6 dB** |

The per-stage spread going from 12 dB to 1.5 dB is the clearest sign. The
stages now work independently instead of pulling on each other.

**Limiting (SIM 4b).** Input stepped over 54 dB:

| input | output |
|---|---|
| 20 µV | 0.121 Vpp |
| 100 µV | 0.604 Vpp |
| 1 mV | 2.267 Vpp |
| 10 mV | **2.502 Vpp** |

**+20 dB of input produces +0.86 dB of output.** That is the limiter doing its
job. It lets the slope detector convert frequency only, so fading and AM noise
are thrown away instead of ending up in the picture. Output 2.50 Vpp = 1.25 V
amplitude, against SIM 1's ≥ 1 V requirement. Limiting starts around 0.4 mV
at the chain input.

The same run showed three more things. The cascode mid-node sits at 1.721 V
and moves **2 mV** across the whole 54 dB input range, so the cascode is
holding. Stage 1's tank voltage scales perfectly linearly ×5, ×10, ×10, so
limiting happens only at the end of the chain, where it should. And stage 3's
emitter DC rises 0.49 → 0.75 V at maximum overdrive. It really rectifies
there, which is what hard limiting looks like. That is harmless because the
diodes define the output, but it matters for recovery behaviour.

**Bench notes.** Every tank is the same 27-turn T37-6 toroid as SIM 3, tapped
at 13 turns, tuned with 56 pF plus a 5–30 pF trimmer. The **four** upper bases
share one 8.2k/10k divider (2.56 V, bypassed), which is one track on the board
(the 22k/18k figure from rev 2 is out of date; see the rev 3 section). And the
input **must** be AC-coupled. A rev-1 bug had the 1 kΩ source resistance in
parallel with the base divider. That dropped the bias to 0.12 V and cut stage
1 off completely. A dead transistor still passes signal through its
base-collector capacitance, so it showed up as −19 dB of "gain" instead of as
an obvious failure.

As always, none of this predicts stability on copper. What it does show is
that the design no longer starts from a position 75 % of the way to
oscillation.

## SIM 5 — ×5 frequency multiplier (the LO chain)

**Final circuit (rev 3).** One transistor (generic UHF NPN, BFR93A-class,
inline model `QRF`) driven by 1 V of 25 MHz through a coupling cap. There is
no DC base bias. The RC input network self-biases the stage into class C, so
the collector current flows in narrow ~25 mA pulses that are rich in
harmonics. The collector tank (150 nH ∥ 10.8 pF, Q≈19) selects 125 MHz, and a
**second, magnetically coupled tank** (`K1 L1 L2 0.03`, near-critical
coupling, Q≈58) cleans it up. On the bench that is a link winding / two
adjacent coils, just like an old IF transformer. VCC is now 5 V (rev 4). It
was originally 6 V, chosen to keep the collector swing inside a real BFR93A's
ratings. The supply-rail section below tells that story in full.

**Final results:** H5 (125 MHz) = **4.65 V** into the 6.8 kΩ-loaded output
tank (the mixer gate needs only ~0.3 V, so a simple tap is enough). Spurious
harmonics: H4 (100 MHz) **−36.9 dB**, H6 (150 MHz) **−42.4 dB**. Supply
current ~2.1 mA average. This validates the frequency plan (25 MHz crystal
× 5). The crystal oscillator (SIM 6) now gets the requirement to deliver
**~1 V amplitude at 25 MHz**.

**Two things I learned from the revisions:**

1. *Capacitive top-coupling has a trap.* Rev 2 coupled the two tanks with a
   series 1.5 pF cap, and H4 barely improved. Below resonance the second
   tank looks inductive, and together with the coupling cap it forms a
   spurious **series resonance** (~117 MHz here). That peaks the transfer
   exactly where I needed rejection. Transformer (mutual-inductance)
   coupling has no such path: H4 improved by 18.6 dB as soon as the
   coupling became magnetic.
2. *Spur targets come from the system, not from symmetry.* H6 is the spur
   that matters. A 150 MHz LO line converts **137.1 MHz straight onto the
   12.9 MHz IF**, inside the front BPF's passband, so it needs ~40 dB from
   the LO chain alone (got 42.4). H4 converts 112.9 MHz, which the front
   BPF already rejects by ≥30 dB. So its total protection is ~67 dB, even
   though the LO-only number (36.9 dB) misses the paper target of 40. I
   accepted that on system-level grounds and wrote it down here instead of
   iterating it away.

**Post-script (from SIM 5b).** The 4.65 V H5 figure above was measured 2 µs
into the run, halfway through the self-bias charge (τ = CC·RB ≈ 10 µs), and
from an ideal 0 Ω source. Both make the result look better than it is. The
settled numbers with realistic drive are in SIM 5b below. The topology
conclusions (magnetic coupling, spur structure) do not change, and the spur
ratios are confirmed again there.

**Rev 4: 5 V.** There is no divider to recompute (the stage self-biases), so
V2 is the only electrical change. I did add a new measurement, because the
rail change moves *both* headroom edges. The flywheel top peak moves 1 V
further from the 12 V V_CEO, which is good. But the swing **minimum** moves
1 V closer to saturation, and a saturating class-C collector clips the tank
and changes the same harmonics H5 depends on. Measured: collector minimum
**0.96 V** even in this file's hard-driven ideal-source case, spurs unchanged
(H4 −36.7 dB, H6 −42.1 dB). The saturation worry came from the old 9.3 Vpp
swing figure, which was an unsettled, ideal-source number. The settled
realistic swing (SIM 5b) is 3.6 Vpp with a 3.3 V floor.

## SIM 5b — multiplier drive robustness

**Question.** SIM 5 characterized the multiplier from an ideal source at
exactly 1 V. The real driver is the SIM 6b buffer: **270 Ω output impedance,
1.9 Vpp nominal, ±20 % tolerance**. A class-C base is a difficult load. It
draws current only in narrow pulses at the positive peaks, and every pulse
through 270 Ω pulls the peak down exactly when it matters. So the question is
how H5 behaves with this real driver.

**Artifact caught first: the unsettled measurement window.** Rev 1 (4 µs run)
showed the LO still drifting 10–12 % between two measurement windows. The
input self-bias network settles with **τ = CC·RB = 10 µs**, so rev 1 *and
SIM 5 itself* had been measured in the middle of the transient. This gave a
new rule next to the timestep one: **the slowest bias loop sets the
measurement window, so prove settling with two spaced windows** (rev 2,
40 µs = 4τ: windows agree ≤1.5 %).

**The settled curve (rev 2):**

| Source ampl. | Drive at base (sagged) | H5 @ 125 MHz | Ic peak |
|---|---|---|---|
| 0.65 V | 1.26 Vpp | 0.007 V | 0.04 mA |
| 0.75 V | 1.44 Vpp | 0.16 V | 0.9 mA |
| 0.95 V (nominal) | 1.76 Vpp | 1.18 V | 8.2 mA |
| 1.15 V | 2.12 Vpp | 1.95 V | 16.4 mA |

**Finding: a conduction cliff.** The resistive sag itself is small (4–8 %).
The danger is the threshold. Self-bias keeps the base right at the edge of
conduction, so below ~1.6 Vpp of drive the collector pulses collapse
(Ic peak: 16 mA → 0.04 mA across the table). The nominal operating point sits
on the steep part: **−18 % drive costs 7× of LO.** Spurs at the settled
points stay fine: H6 (the critical one) −44/−45 dB, H4 −33/−34 dB
(covered at system level by the front BPF).

**Derived requirement (the fix, read straight off the curve).** The mixer
needs only ~0.3 V of LO. So I move the operating point one step up: the
buffer must deliver **~2.1–2.2 Vpp at the multiplier base**. Then nominal
H5 ≈ 2 V, and the −20 % corner lands exactly on the already-measured 1.76 Vpp
point: H5 = 1.18 V, still **4× the mixer's need**. This sim does not need a
re-run, because the curve already contains the new operating point and its
tolerance corner. The buffer revision implements it (SIM 6b rev 2).

### SIM 5b rev 3 — the same curve on 5 V

There is no divider to recompute (the stage self-biases), so V2 is the only
electrical change. I also changed **RSRC 270 → 330 Ω** (the rev-2 buffer's
actual collector resistor; the 270 value was out of date) and added a new
`Vt1min` measurement that watches the minimum of the collector swing for
saturation. The settled curve on 5 V:

| Source ampl. | Drive (sagged) | H5 @ 125 MHz | Collector min | H5 was (6 V) |
|---|---|---|---|---|
| 0.65 V | 1.25 Vpp | 0.006 V | 4.99 V | 0.007 V |
| 0.75 V | 1.43 Vpp | 0.13 V | 4.88 V | 0.16 V |
| 0.95 V (−20 % corner) | 1.74 Vpp | **1.02 V** | 4.03 V | 1.18 V |
| 1.15 V (nominal) | 2.11 Vpp | **1.68 V** | 3.33 V | 1.95 V |

This table answers three questions. **The cliff has not moved**: self-bias
tracks the drive, not the rail, and the collapse still sits between 1.43 and
1.74 Vpp of sagged drive. **No saturation**: the collector floor stays at
3.33 V at nominal. The worry before the run came from the unsettled
ideal-source 9.3 Vpp figure, so the spaced-windows rule helped again. **The
real price of 5 V is 14 % of H5** (1.95 → 1.68 V at the same drive). C_cb
grows at the lower V_CB and loads the tank, and the current pulses shrink a
little (16.4 → 15.2 mA peak). That is not a problem. The −20 % corner still
delivers **1.02 V against the mixer's 0.3 V need (3.4×, was 4×)**, well above
the mixer's measured 0.4 V plateau threshold. Spurs at nominal: H6
**−45.1 dB**, H4 −32.5 dB, so unchanged. Settling is proven: spaced windows
agree within 1.3 % on every step. The almost identical sagged-drive values
also show that the 330 Ω source costs almost nothing. The class-C base pulses
dominate the sag, not the resistor.

## SIM 6 — 25 MHz crystal oscillator

**Circuit.** Common-collector Colpitts, one transistor (`QRF`, the same
BFR93A-class inline model as SIM 5). The crystal is drawn as its **equivalent
circuit** instead of a library symbol, so the physics stays visible on the
schematic: motional arm L = 2.0265 mH, C = 20 fF, R = 15 Ω (series-resonant at
exactly 25.000 MHz, Q ≈ 21 000) plus 5 pF holder capacitance. The very large L
and very small C are the reason quartz works as a frequency standard.
Feedback goes through an 82 pF / 180 pF capacitive divider around the emitter
follower. Bias 11 kΩ/10 kΩ from 5 V, RE = 560 Ω (Ie ≈ 2.8 mA). Output taken
at the emitter.

**Simulating an oscillator has two quirks**, both documented in the .asc:

1. *Startup.* A simulator has no thermal noise, so an oscillator sim can sit
   at its DC operating point forever, stable and not oscillating at all.
   The `.ic V(b)=0` line pulls the base at t = 0 as a starting kick.
2. *Patience.* The envelope grows with a time constant set by the crystal's
   very high Q. Visible RF only appears after ~100 µs, and limiting takes a
   few hundred µs more. The run takes minutes. That is the crystal's
   physics, not a solver problem.

**Results.** Envelope: 55 mVpp at 200–250 µs → limited before 1 ms. The
measurement windows at 1.45–1.5 ms and 2.9–3 ms both read **410.6 mVpp**,
identical to six digits, so the amplitude is very stable. DC at the emitter
is 1.578 V, matching the hand-calculated bias. The 25 MHz fundamental is
dominant. H2 sits at −10.8 dB, which is *expected and harmless* at the
emitter node of a Colpitts. The emitter current flows in pulses, because Vbe
swings ~±100 mV and the exponential makes that very nonlinear. Frequency
purity is set by the crystal current, not at the emitter, and the next stage
is a class-C multiplier that is nonlinear on purpose anyway.

**Why the low amplitude is a good thing.** Real crystals have a maximum
drive-level rating (~0.1–0.5 mW). Overdriving speeds up aging and frequency
drift. So a good crystal oscillator runs *gently*, which is exactly what
410 mVpp is, and any level the next stage needs comes from amplifying
afterwards. That is why the classic architecture is "small oscillator +
buffer". The requirement this hands to **SIM 6b** is a buffer/driver with a
gain of ~5 (0.41 → ~2 Vpp for the class-C multiplier). It also isolates the
crystal from the multiplier's very nonlinear input.

**Pass criteria (all met)**

| Criterion | Target | Result |
|---|---|---|
| Startup | envelope grows from the kick | 55 mVpp @ 225 µs → limiting |
| Amplitude stability | Vpp constant between distant windows | 410.6 mVpp, identical @ 1.5 ms and 3 ms |
| Spectrum | 25 MHz fundamental dominant | H2 −10.8 dB (normal at the emitter node) |
| Bias under oscillation | matches hand calculation | 1.578 V vs ~1.6 V calculated |

**Rev 2: 5 V.** One resistor: R1 15k → **11k** restores the base to 2.38 V
and I_E to 2.8 mA. With the old divider at 5 V the current would have dropped
23 %. The limiting amplitude would have dropped with it, and the cliff margin
of the whole LO chain depends on that amplitude. Measured on 5 V:
**409.7 mVpp** (0.2 % below the 6 V figure), emitter DC 1.577 V, H2
unchanged. The operating point held, so the oscillation did not notice the
rail change.

### SIM 6b — buffer/driver

**Circuit.** Common-emitter stage AC-coupled to the oscillator's emitter:
bias divider 15 kΩ/5.1 kΩ, collector 270 Ω, emitter split into **47 Ω
unbypassed** (the gain is set by feedback, ≈ R_C/(r_e+47) ≈ 5, not by the
transistor's own spread) + 100 Ω bypassed. The output drives a **replica of
the multiplier's real input network** (1 nF + 10 kΩ self-bias), so the level
is measured into the load it will really see. The buffer also completes the
isolation: its ~2.2 kΩ input barely loads the oscillator node, and the
multiplier's nonlinear base-current pulses now land on the 270 Ω collector
resistor instead of the crystal loop.

**Results** (3 ms run, maxstep 1 ns): **1.904 Vpp** at the load, bit-identical
between the 1.5 ms and 3 ms windows. The 25 MHz fundamental (0.89 V) is
dominant. Oscillator amplitude 399.8 mVpp and DC 1.574 V, unchanged within
2.6 % from the buffer-less SIM 6 run. This also works as a
**timestep-convergence check** (2 ns vs 1 ns agree to ~2 %, unlike SIM 1's
early 2× artifact). One small second-order error: the collector sits at
4.88 V instead of the predicted ~4.6 V. Q2's ~40 µA base current through the
divider's 3.8 kΩ Thevenin resistance takes away ~0.15 V of bias, so Ic lands
at 4.1 mA instead of 5.2 mA and the gain at 4.9 instead of 5.2. That is within
tolerance, so I documented it instead of iterating it away.

This closed the buffer as an amplifier. SIM 5b then showed that 1.9 Vpp puts
the multiplier right on its conduction cliff, so rev 2 raises the drive one
step.

**Rev 2 (the SIM 5b fix): RC 270 → 330 Ω, RE2 100 → 68 Ω.** The gain goes
~4.9 → ~6 and the stage current 4.1 → 4.9 mA, so the larger positive swing
still clears cutoff. Results: **2.354 Vpp** into the replica load,
bit-stable between windows, collector at 4.37 V (Ic = 4.93 mA, matching the
hand calculation), H2 at 31 %. That is the same as rev 1, so the larger swing
adds no clipping. Oscillator amplitude and bias are untouched. On SIM 5b's
settled curve, the multiplier now sits at H5 ≈ 2 V nominal, and the −20 %
drive corner lands on the measured 1.76 Vpp point (H5 = 1.18 V), still 4× the
mixer's need. **The LO chain is closed end-to-end on settled
numbers: crystal 0.40 Vpp → buffer 2.35 Vpp → class-C ×5 → ~2 V of
125 MHz into a mixer that needs 0.3 V.**

**Rev 3: 5 V.** Two resistors, with both dividers recomputed to hold the
operating points: R1 15k → **11k** for the embedded oscillator and R3
15k → **12k** for the buffer. The buffer change is the important one. At
5 V the old divider would leave I_C at 3.4 mA, but the positive peak of
2.35 Vpp into the 330∥10k load needs 3.7 mA of swing. The stage would clip
through cutoff, which is exactly the defect rev 2 fixed. Measured on 5 V:
**2.333 Vpp** into the replica load (−0.9 % vs 6 V), bit-stable between
windows, collector at 3.42 V (I_C = 4.79 mA), H2 = 30.6 % (no new
clipping), oscillator untouched (396 mVpp / 1.573 V). The −20 % drive corner
now lands at 1.87 Vpp, still above the measured 1.76 Vpp point of SIM 5b's
curve. So **the LO chain stays closed on 5 V: crystal 0.41 Vpp → buffer
2.33 Vpp → class-C ×5 → 1.68 V of 125 MHz (1.0 V at the −20 % corner) into
a mixer that needs 0.3 V.**

## SIM 7 — the input filter

**Two jobs, and only one is obvious.** The obvious one is to keep FM
broadcast (88–108 MHz) and airband (118–137 MHz) out of the LNA, because both
are much stronger than any satellite. The one that decides the frequency plan
is **image rejection**. With LO = 125 MHz and IF = 12.9 MHz, the mixer
converts *both* 125 + 12.9 = 137.9 (wanted) and 125 − 12.9 = **112.1** (the
image) onto the same IF, and nothing downstream can separate them afterwards.
This filter is the only protection. That is why I chose 112.1 MHz to fall in
the quiet gap between the FM and airband allocations.

**New trick at VHF: the capacitive divider.** At 12.9 MHz I transformed the
impedance with a *coil tap* (turn 13 of 27). At 137.9 MHz the coil has only
~5 turns, and the tap would need to sit at 13 % of them. That is 0.65 of a
turn, which does not exist. So the tank capacitor is split instead: 15 pF in
series with 100 pF, with the port at the junction. Ratio 15/115 = 0.130, so
the 50 Ω port appears across the tank as 50/0.130² = 2.94 kΩ. It is the same
idea as the tap with different hardware, and it is why every VHF front end
looks like this.

L = 82 nH (Z₀ = 71 Ω), tank total 16.2 pF = 13.0 pF from the divider +
3.2 pF trimmer. With the coil's own Q ≈ 150, the loaded Q comes to 32 and the
passband to ~6 MHz. That is huge next to the 43 kHz the signal occupies, and
it is on purpose. This filter is not there to be selective. It is there to
reject a band 26 MHz away, and a narrow front end would only add loss at the
point where loss directly costs noise figure.

**Results (k stepped):**

| k | regime | passband | image rejection @112.1 | insertion loss |
|---|---|---|---|---|
| 0.015 | undercoupled | 3.5 MHz | 42.0 dB | 4.1 dB |
| **0.031** | **critical** | **6.0 MHz** | **37.6 dB** | **2.2 dB** |
| 0.062 | overcoupled | 11.2 MHz | 31.6 dB | 2.1 dB (2.3 dB dip) |

Also at critical coupling: 137.1 MHz (the other Meteor) passes within 0.03 dB
of centre, FM broadcast is 40.3 dB down and airband 33.0 dB down.

**Before the run I wrote a prediction into the file, and it turned out to be
wrong.** The note said overcoupling might give image rejection for free
through steeper skirts. It does the opposite: 31.6 dB against 37.6 dB
critical. Far from centre the attenuation is set by **loaded Q**, not by
skirt shape. Overcoupling widens the response, which is the same as lowering
the effective Q, so the whole curve moves outward. The skirts really are
steeper, but they start further out.

**Critical coupling chosen.** Undercoupling gives 4.4 dB more rejection but
costs 1.9 dB more insertion loss, and loss ahead of the LNA goes straight
into the noise figure. 37.6 dB already clears the 30 dB target. The 2.2 dB
that remains costs almost nothing in practice. At 137 MHz the galactic
background corresponds to well over 1000 K, clearly above a ~440 K receiver.
So the sky is noisier than the front end, and a couple of dB there changes
little, while the LNA gets real protection from the broadcast bands.

**This is the first block I can measure instead of only trusting the
simulation.** It is 50 Ω in and 50 Ω out, which is exactly what a miniVNA
presents. Build it, sweep it, and lay the trace over this simulation.

**Bench BOM:** L1, L2 = ~5 turns of 0.8 mm enamelled copper on a 5 mm former,
air core, trimmed by squeezing or spreading the turns. They are mounted about
one coil diameter apart with axes aligned (that spacing is what sets
k ≈ 0.03, and sliding them adjusts it). Ct1, Ct2 = 1–10 pF trimmer; 15 pF and
100 pF NP0 (rev 1 values, replaced below).

### SIM 7 rev 2 — real trimmer, real layout (September 2026)

The rev 1 numbers missed two things. First, the trimmer I can actually buy
(Murata TZC3) covers **3–10 pF**, not 1–10. Second, the board's tank loop adds
about **8.6 nH** in series with each 82 nH coil and **0.5 pF** of stray at the
hot node, even after the layout cleanup pulled it tight under the coils
(measured on the layout, `pcb/DESIGN_LOG.md`, step E1). With those in the rev 1
circuit, the trimmer value that centres the filter at 137.9 MHz is 0.7 pF.
That is below the trimmer's minimum, and with a +10 % coil no setting reaches
it at all.

The fix I chose keeps the coil and the tap ratio and changes only the divider:
**C1a/C2a 15 pF → 8.2 pF, C1b/C2b 100 pF → 56 pF.** The ratio 8.2/64.2 = 0.128
matches the rev 1 0.130, so the 50 Ω port still appears across the tank as
~3 kΩ. The loaded Q, the passband and the image rejection are unchanged. The
divider's series capacitance drops from 13.0 to 7.15 pF, and the trimmer takes
up the difference. Six alternatives were run through the same circuit with
the layout parasitics and ±10 % coils (all at critical coupling k = 0.031; IL
is the true 50 Ω-to-50 Ω insertion loss):

| option | trimmer at 137.9 (nominal / −10 % coil / +10 % coil) | IL | passband | image @112.1 |
|---|---|---|---|---|
| 82 nH, 15p/100p (rev 1 values on the real board) | 0.7 / 2.1 / **unreachable** pF | 2.2 dB | 5.4 MHz | 39.6 dB |
| 55 nH (4 turns), 15p/100p | 6.8 / 8.7 / 5.1 pF | 2.9 dB | 5.1 MHz | 42.4 dB |
| 82 nH, 10p/100p (ratio 0.091) | 4.6 / 6.1 / 3.5 pF | 4.1 dB, 137.1 MHz 3 dB down | 5.2 MHz | 44.4 dB |
| 82 nH, 10p/68p (ratio 0.128) | 5.2 / 6.6 / 4.0 pF | 2.2 dB | 5.5 MHz | 39.7 dB |
| **82 nH, 8.2p/56p (ratio 0.128), chosen** | **6.7 / 8.1 / 5.6 pF** | **2.2 dB** | **5.5 MHz** | **40.2 dB** |

The 4-turn coil gives 2 dB more image rejection, but it costs 0.7 dB more loss
in front of the LNA (its loaded Q rises, and the estimate is optimistic because
a 4-turn coil has a lower unloaded Q than the 150 assumed for all rows). It
also leaves 1.3 pF of headroom for a −10 % coil, and it changes a winding
recipe that the footprint, the keepout and the coupling spacing were all
designed around. The 10p/100p option is a different tap ratio, and you can see
it: 2 dB more loss and the other Meteor frequency 3 dB down. Between the two
splits that keep the ratio, 8.2p/56p puts the trimmer in the middle of its
range, with at least 1.9 pF to either end. It still has 1 pF of margin if the
stray copper turns out to be 1 pF instead of 0.5. In that case the 10p/68p
split would be at 3.0 pF, right at the minimum, for a +10 % coil.
`sim7_input_bpf.asc` and `sim12` now use 8.2p/56p. Their ideal-netlist trimmer
value is ~8.7 pF because the parasitics are not in the netlist. On the board,
expect **~6.7 pF**. The ideal rev 2 run at critical coupling: insertion loss
2.4 dB, passband 6.1 MHz, image rejection 39.5 dB, 137.1 MHz 0.5 dB down. That
is within 0.2 dB / 0.1 MHz of the rev 1 filter. (Its under- and over-coupled
rows now show 1–2 dB of ripple, because the trimmer is left at the
critical-coupling optimum instead of being re-tuned for each k, as the rev 1
table implicitly was. On the bench the trimmer gets turned, so only the
critical row is the design.)

## SIM 9 — the LNA

**Why a feedback amplifier and not another tuned stage.** There are two
reasons, and I only saw the first one after SIM 7. That filter was designed
against **50 Ω terminations**, and it will be aligned on the bench against
them too. Whatever follows it must really present 50 Ω, or its response and
its image rejection get distorted. A resistive feedback amplifier has an
input impedance set by *resistors*, so it holds across the band and from part
to part. The second reason comes from SIM 4: intentional negative feedback
through a resistor swamps the parasitic feedback path that made the tuned IF
stages regenerative. This is the classic EMRFD homebrew building block.

**How it works.** Two feedback paths set everything: `Rf` = 470 Ω from
collector to base (through `Cf`, so it carries only RF and leaves the DC
bias independent) and `RE1` = 2.2 Ω unbypassed in the emitter. With the
120 Ω collector load working into the 50 Ω output termination, the shunt
feedback lands the input near 50 Ω while the series feedback sets the gain.
Ie ≈ 21 mA. LNAs run at high current on purpose, for headroom against the FM
broadcast and airband energy that gets past the filter.

**Results (rev 2, 5 V):** S21 = **15.75 dB** at 137.9 MHz, input impedance
**38.3 Ω** (VSWR 1.31:1). The response is flat within 0.5 dB from 20 to
138 MHz and rolls off smoothly through 300 and 700 MHz with **no peaking
anywhere**. The measured maximum over the whole 10 MHz–1 GHz sweep sits
0.02 dB above the low-frequency plateau. That is what a purely resistive
feedback amplifier should do, and exactly what a parasitic resonance would
spoil.

### SIM 9 rev 2 — the same LNA on 5 V

One resistor: **RB1 1.2k → 910**, which restores the base to 1.9 V so I_E
stays at ~20 mA. With the old divider at 5 V, I_E would have dropped to
~15 mA. That costs about a dB of S21 and, worse, shifts the 50 Ω input match
that SIM 7's alignment depends on. The price of the lower rail is headroom,
and this stage shows it the most: the collector now sits at **2.58 V**
(measured; was ~3.5 V), leaving V_CE ≈ 1.55 V. I checked this against what is
needed. The largest signal this stage ever sees is strong local FM broadcast
*after* the filter's −40 dB, about 4 mVpp at the output. So the >300× swing
margin is still far more than enough, and dissipation drops to ~31 mW.
Measured differences against 6 V: S21 15.92 → 15.75 dB, flatness
0.4 → 0.5 dB (the lower V_CB raises C_cb by ~20 %, which is the direction the
physics predicts). Both are inside real part-to-part tolerance.

**A note on noise.** A feedback amplifier is not the lowest-noise topology
(~4–5 dB NF), and I would not trust LTspice noise figures anyway. It does not
matter much here. At 137 MHz the galactic background is higher than the
receiver's own noise, and the bench goal (decoding a replayed recording
through attenuators) does not depend on NF at all. This stage has to deliver
match, gain and stability, and it does.

Like SIM 7, this block is **50 Ω in and out, so the miniVNA can measure it
directly** against this plot.
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

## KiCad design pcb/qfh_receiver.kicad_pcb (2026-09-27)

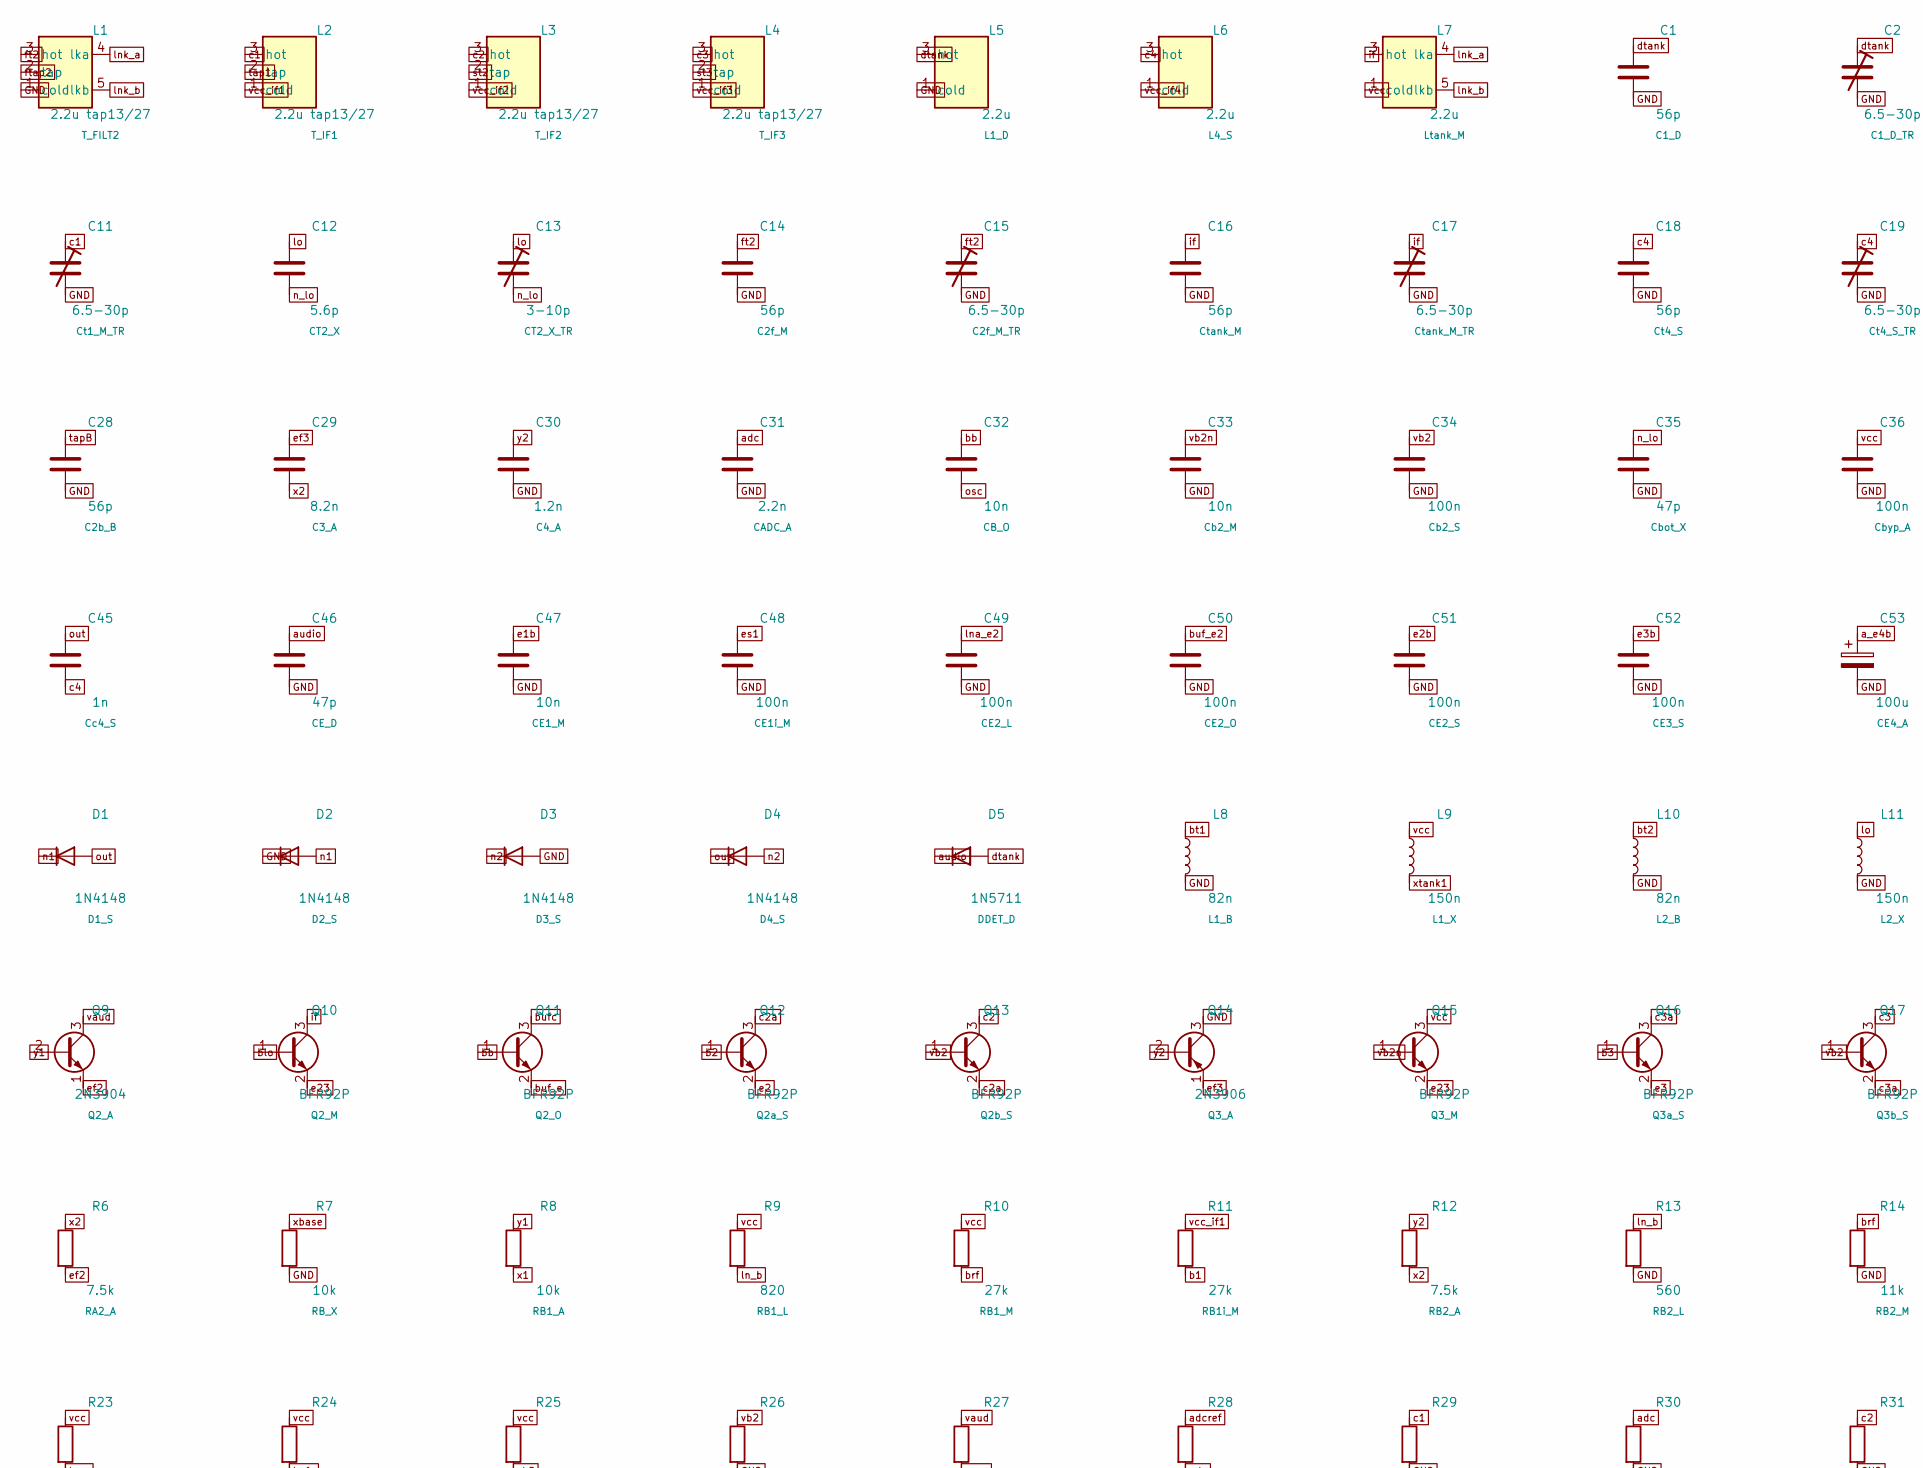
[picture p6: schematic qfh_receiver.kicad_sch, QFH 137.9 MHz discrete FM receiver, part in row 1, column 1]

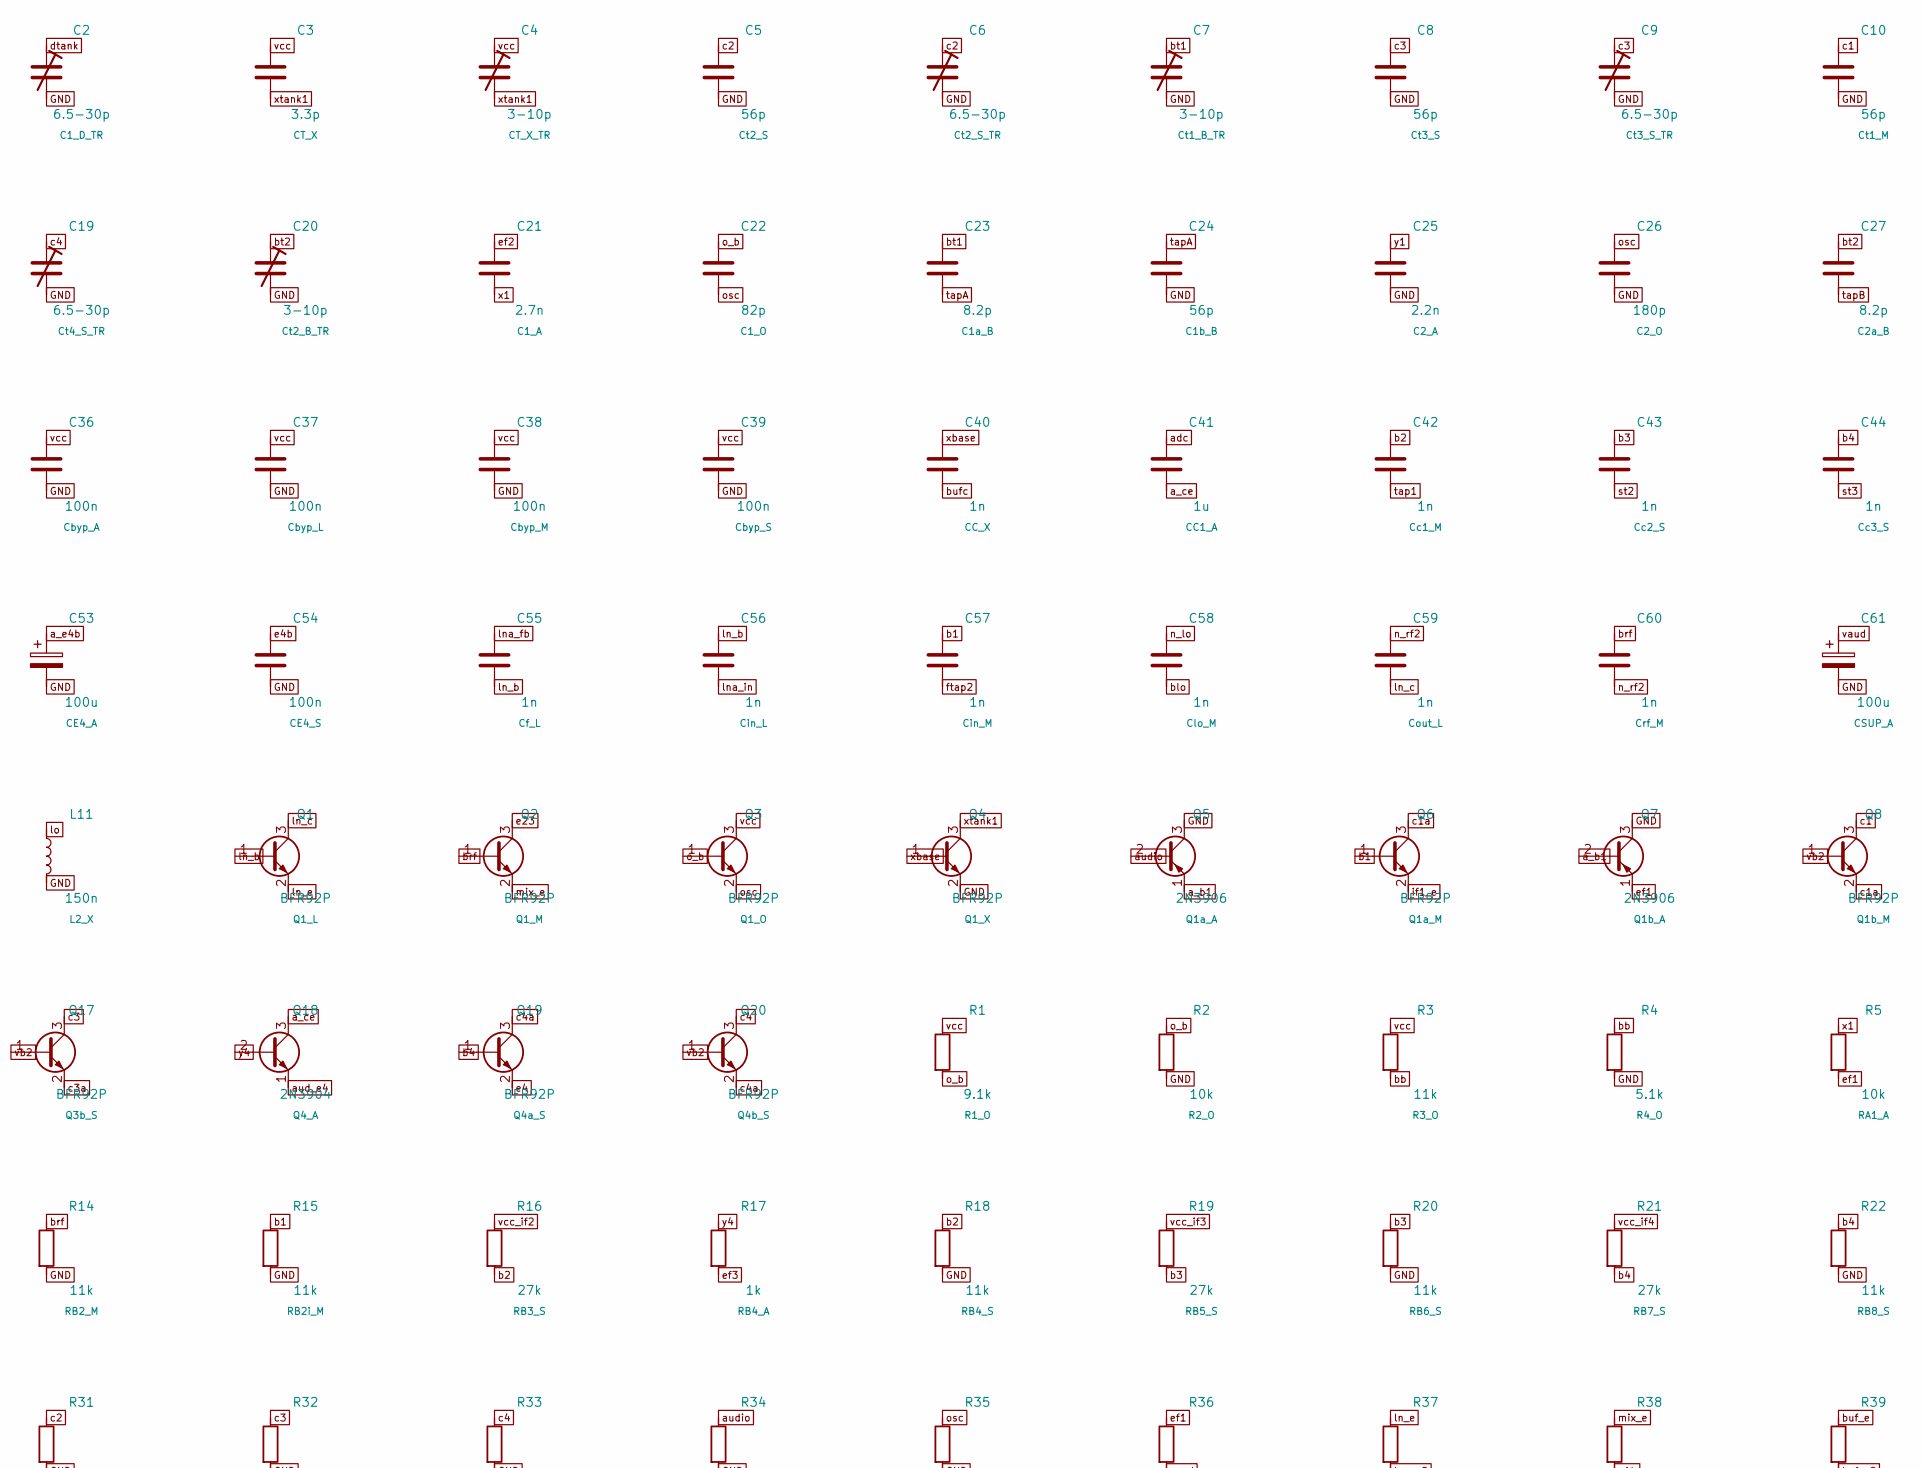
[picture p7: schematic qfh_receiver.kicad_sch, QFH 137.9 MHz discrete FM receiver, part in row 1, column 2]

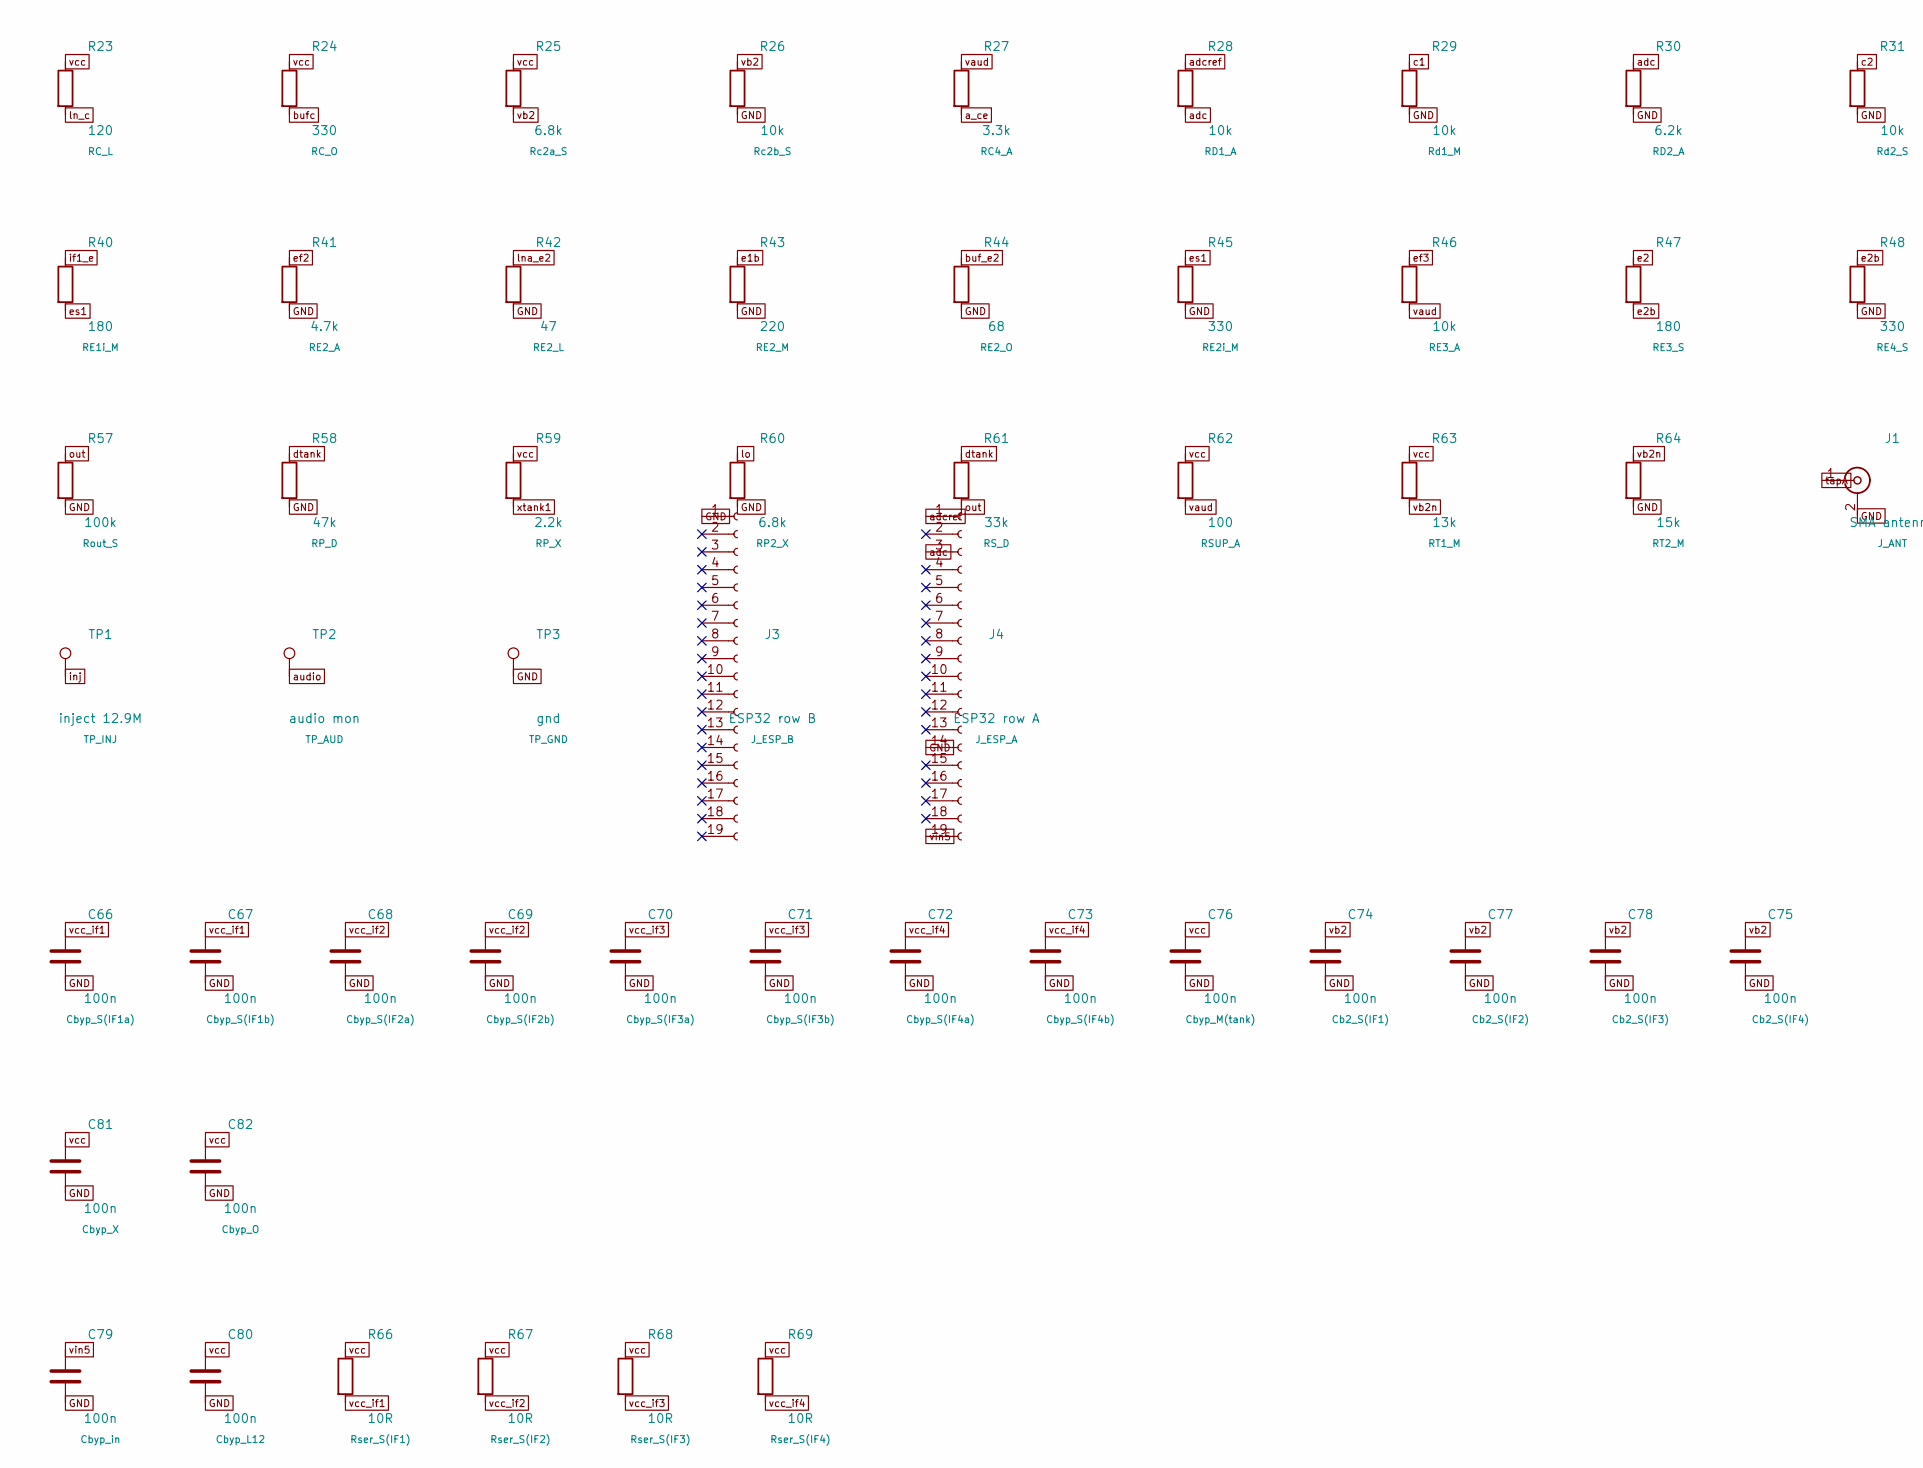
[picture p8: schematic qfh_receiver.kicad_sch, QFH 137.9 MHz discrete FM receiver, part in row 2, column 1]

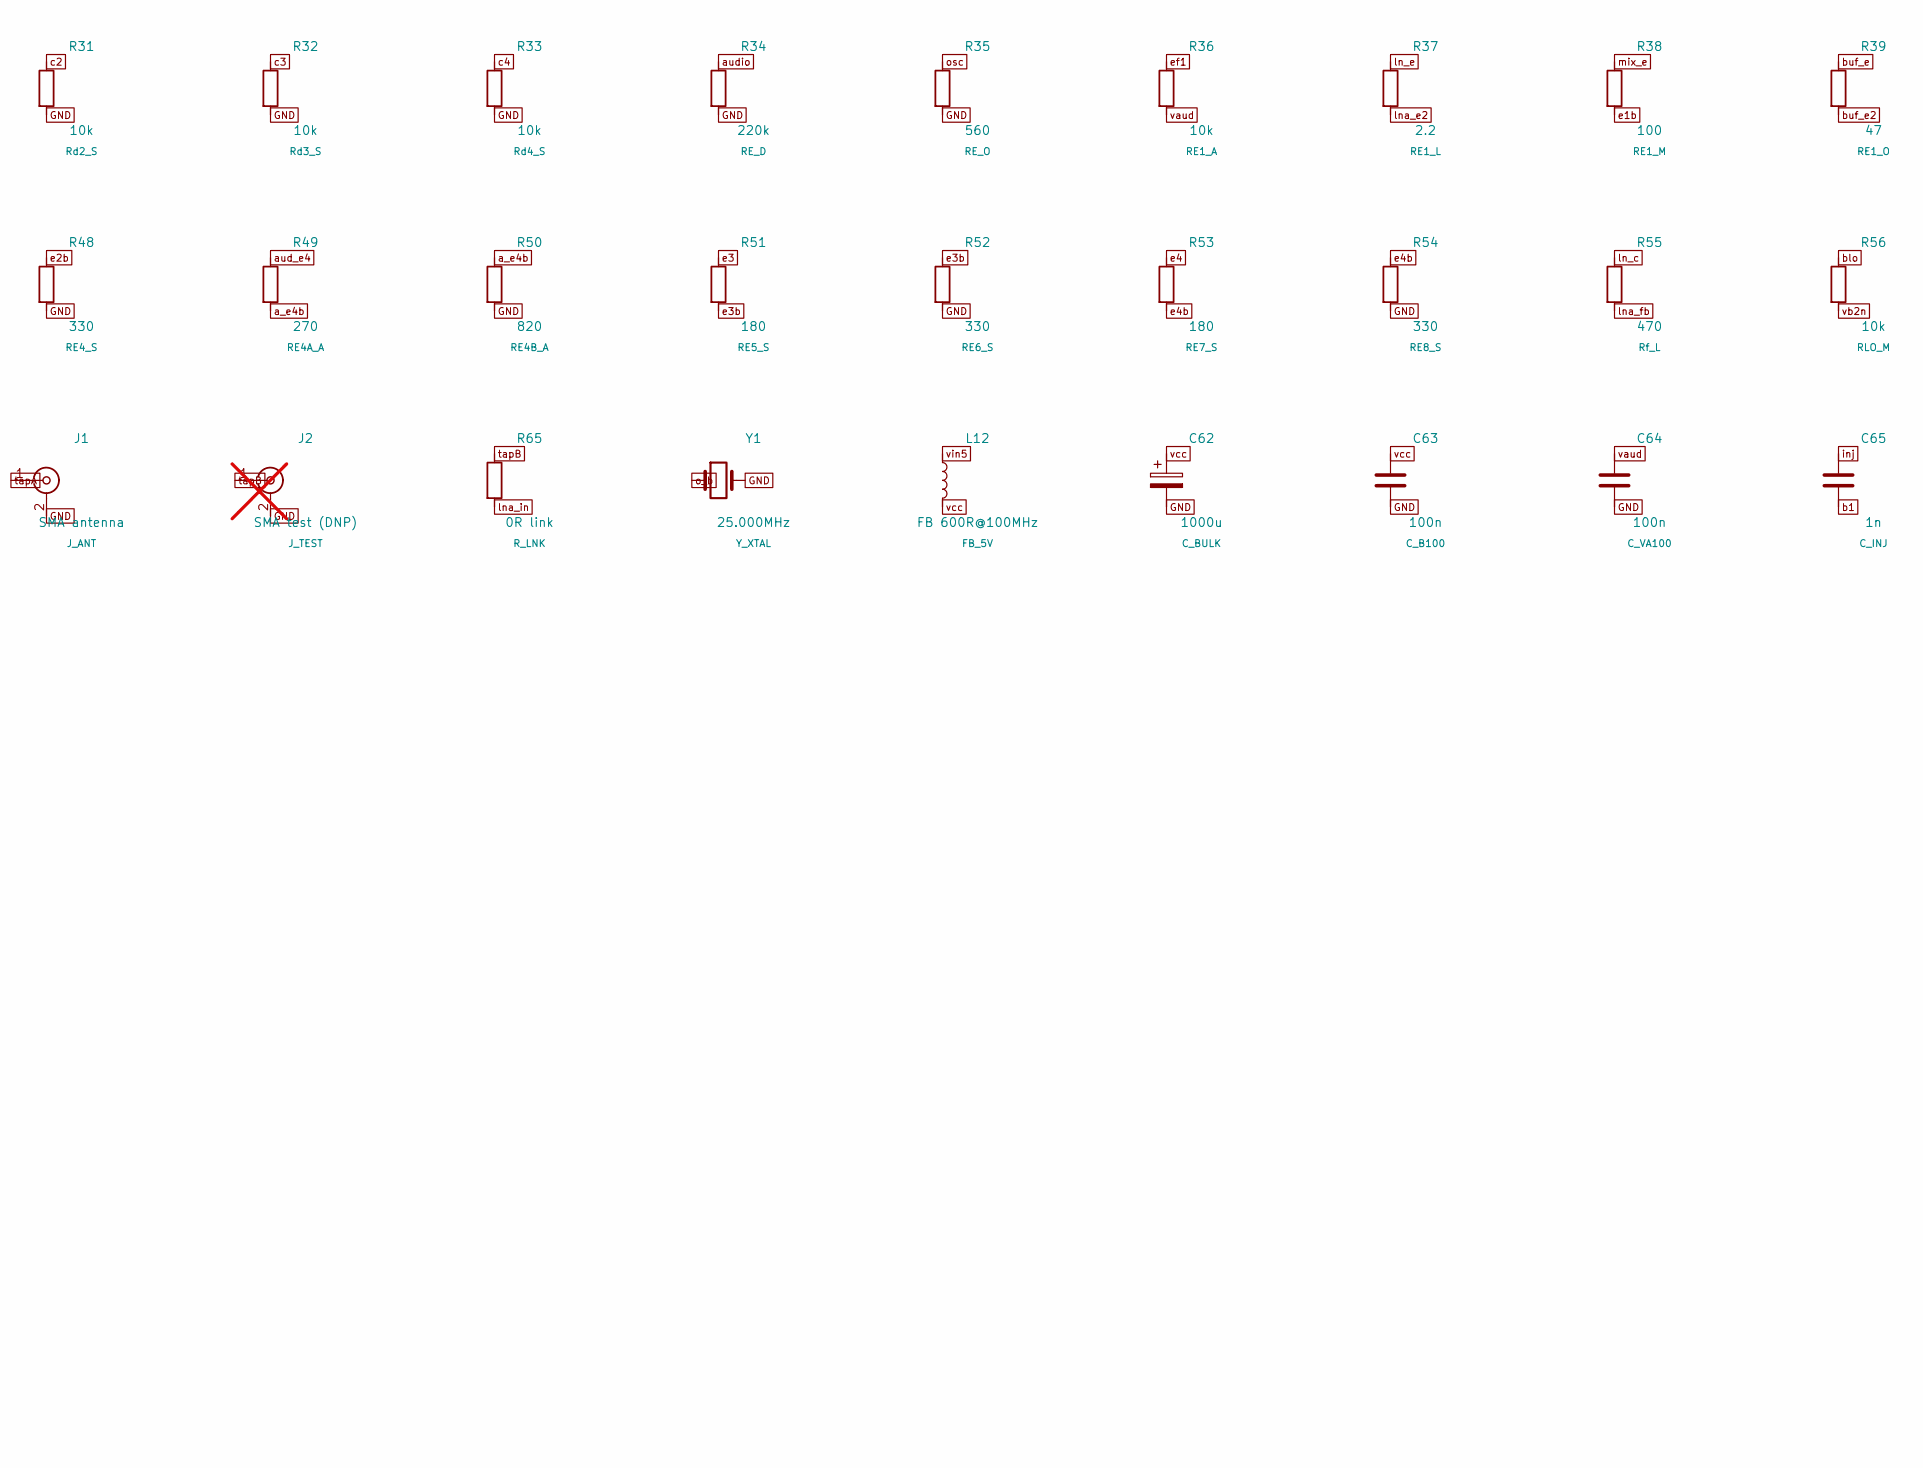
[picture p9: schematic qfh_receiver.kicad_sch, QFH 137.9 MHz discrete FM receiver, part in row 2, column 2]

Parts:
C1, C5, C8, C10, C14, C16, C18, C24, C28: 56p; C_0805_2012Metric
C2, C6, C9, C11, C15, C17, C19: 6.5-30p; C_Trimmer_Murata_TZC3; MPN TZC3P300A110R00; Farnell 2456139
C3: 3.3p; C_0805_2012Metric
C4, C7, C13, C20: 3-10p; C_Trimmer_Murata_TZC3; MPN TZC3R100A110R00; Farnell 2456140RL
C12: 5.6p; C_0805_2012Metric
C21: 2.7n; C_0805_2012Metric
C22: 82p; C_0805_2012Metric
C23, C27: 8.2p; C_0805_2012Metric
C25, C31: 2.2n; C_0805_2012Metric
C26: 180p; C_0805_2012Metric
C29: 8.2n; C_0805_2012Metric
C30: 1.2n; C_0805_2012Metric
C32, C33, C47: 10n; C_0805_2012Metric
C34, C36, C37, C38, C39, C48, C49, C50, C51, C52, C54, C63, C64, C66, C67, C68, C69, C70, C71, C72, C73, C74, C75, C76, C77, C78, C79, C80, C81, C82: 100n; C_0805_2012Metric
C35, C46: 47p; C_0805_2012Metric
C40, C42, C43, C44, C45, C55, C56, C57, C58, C59, C60, C65: 1n; C_0805_2012Metric
C41: 1u; C_0805_2012Metric
C53, C61: 100u; CP_Radial_D5.0mm_P2.50mm
C62: 1000u; CP_Radial_D8.0mm_P3.50mm
D1, D2, D3, D4: 1N4148; D_DO-35_SOD27_P2.54mm_Vertical_AnodeUp
D5: 1N5711; D_DO-35_SOD27_P2.54mm_Vertical_AnodeUp
J1: SMA antenna; SMA_Amphenol_132289_EdgeMount; MPN 132289; Farnell 2112467
J2: SMA test (DNP); SMA_Amphenol_132289_EdgeMount; MPN 132289; Farnell 2112467; not fitted
J3: ESP32 row B; PinSocket_1x19_P2.54mm_Vertical
J4: ESP32 row A; PinSocket_1x19_P2.54mm_Vertical
L1, L2, L3, L4: 2.2u tap13/27; TOROID_T37-6_UNIVERSAL
L5, L6, L7: 2.2u; TOROID_T37-6_UNIVERSAL
L8, L10: 82n; AIRCOIL_5MM
L9, L11: 150n; AIRCOIL_5MM
L12: FB 600R@100MHz; L_0805_2012Metric
Q1, Q2, Q3, Q4, Q6, Q8, Q10, Q11, Q12, Q13, Q15, Q16, Q17, Q19, Q20: BFR92P; SOT-23; MPN BFR92PE6327HTSA1
Q5, Q7, Q14: 2N3906; TO-92_Inline_Wide
Q9, Q18: 2N3904; TO-92_Inline_Wide
R1: 9.1k; R_0805_2012Metric
R2, R5, R7, R8, R26, R28, R29, R31, R32, R33, R36, R46, R56: 10k; R_0805_2012Metric
R3, R14, R15, R18, R20, R22: 11k; R_0805_2012Metric
R4: 5.1k; R_0805_2012Metric
R6, R12: 7.5k; R_0805_2012Metric
R9, R50: 820; R_0805_2012Metric
R10, R11, R16, R19, R21: 27k; R_0805_2012Metric
R13, R35: 560; R_0805_2012Metric
R17: 1k; R_0805_2012Metric
R23: 120; R_0805_2012Metric
R24, R45, R48, R52, R54: 330; R_0805_2012Metric
R25, R60: 6.8k; R_0805_2012Metric
R27: 3.3k; R_0805_2012Metric
R30: 6.2k; R_0805_2012Metric
R34: 220k; R_0805_2012Metric
R37: 2.2; R_0805_2012Metric
R38, R62: 100; R_0805_2012Metric
R39, R42: 47; R_0805_2012Metric
R40, R47, R51, R53: 180; R_0805_2012Metric
R41: 4.7k; R_0805_2012Metric
R43: 220; R_0805_2012Metric
R44: 68; R_0805_2012Metric
R49: 270; R_0805_2012Metric
R55: 470; R_0805_2012Metric
R57: 100k; R_0805_2012Metric
R58: 47k; R_0805_2012Metric
R59: 2.2k; R_0805_2012Metric
R61: 33k; R_0805_2012Metric
R63: 13k; R_0805_2012Metric
R64: 15k; R_0805_2012Metric
R65: 0R link; R_0805_2012Metric
R66, R67, R68, R69: 10R; R_0805_2012Metric
TP1: inject 12.9M; TestPoint_Pad_D2.0mm
TP2: audio mon; TestPoint_Pad_D2.0mm
TP3: gnd; TestPoint_Pad_D2.0mm
Y1: 25.000MHz; Crystal_HC49-4H_Vertical

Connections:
GND: C1.2, C2.2, C5.2, C6.2, C7.2, C8.2, C9.2, C10.2, C11.2, C14.2, C15.2, C16.2, C17.2, C18.2, C19.2, C20.2, C24.2, C25.2, C26.2, C28.2, C30.2, C31.2, C33.2, C34.2, C35.2, C36.2, C37.2, C38.2, C39.2, C46.2, C47.2, C48.2, C49.2, C50.2, C51.2, C52.2, C53.2, C54.2, C61.2, C62.2, C63.2, C64.2, C66.2, C67.2, C68.2, C69.2, C70.2, C71.2, C72.2, C73.2, C74.2, C75.2, C76.2, C77.2, C78.2, C79.2, C80.2, C81.2, C82.2, D2.1 (K), D3.2 (A), J1.2 (Ext), J2.2 (Ext), J3.1 (Pin_1_1), J4.14, L1.1 (cold), L5.1 (cold), L8.2, L10.2, L11.2, Q4.2 (E), Q5.3 (C), Q7.3 (C), Q14.3 (C), R2.2, R4.2, R7.2, R13.2, R14.2, R15.2, R18.2, R20.2, R22.2, R26.2, R29.2, R30.2, R31.2, R32.2, R33.2, R34.2, R35.2, R41.2, R42.2, R43.2, R44.2, R45.2, R48.2, R50.2, R52.2, R54.2, R57.2, R58.2, R60.2, R64.2, TP3.1 (1_1), Y1.2
a_b1: Q5.1 (E), Q7.2 (B)
a_ce: C41.2, Q18.3 (C), R27.2
a_e4b: C53.1, R49.2, R50.1
adc: C31.1, C41.1, J4.3, R28.2, R30.1
adcref: J4.1, R28.1
aud_e4: Q18.1 (E), R49.1
audio: C46.1, D5.1 (K), Q5.2 (B), R34.1, TP2.1 (1_1)
b1: C57.1, C65.2, Q6.1 (B), R11.2, R15.1
b2: C42.1, Q12.1 (B), R16.2, R18.1
b3: C43.1, Q16.1 (B), R19.2, R20.1
b4: C44.1, Q19.1 (B), R21.2, R22.1
bb: C32.1, Q11.1 (B), R3.2, R4.1
blo: C58.2, Q10.1 (B), R56.1
brf: C60.1, Q2.1 (B), R10.2, R14.1
bt1: C7.1, C23.1, L8.1
bt2: C20.1, C27.1, L10.1
buf_e: Q11.2 (E), R39.1
buf_e2: C50.1, R39.2, R44.1
bufc: C40.2, Q11.3 (C), R24.2
c1: C10.1, C11.1, L2.3 (hot), Q8.3 (C), R29.1
c1a: Q6.3 (C), Q8.2 (E)
c2: C5.1, C6.1, L3.3 (hot), Q13.3 (C), R31.1
c2a: Q12.3 (C), Q13.2 (E)
c3: C8.1, C9.1, L4.3 (hot), Q17.3 (C), R32.1
c3a: Q16.3 (C), Q17.2 (E)
c4: C18.1, C19.1, C45.2, L6.3 (hot), Q20.3 (C), R33.1
c4a: Q19.3 (C), Q20.2 (E)
dtank: C1.1, C2.1, D5.2 (A), L5.3 (hot), R58.1, R61.1
e1b: C47.1, R38.2, R43.1
e2: Q12.2 (E), R47.1
e2b: C51.1, R47.2, R48.1
e3: Q16.2 (E), R51.1
e3b: C52.1, R51.2, R52.1
e4: Q19.2 (E), R53.1
e4b: C54.1, R53.2, R54.1
e23: Q2.3 (C), Q10.2 (E), Q15.2 (E)
ef1: Q7.1 (E), R5.2, R36.1
ef2: C21.1, Q9.1 (E), R6.2, R41.1
ef3: C29.1, Q14.1 (E), R17.2, R46.1
es1: C48.1, R40.2, R45.1
ft2: C14.1, C15.1, L1.3 (hot)
ftap2: C57.2, L1.2 (tap)
if: C16.1, C17.1, L7.3 (hot), Q10.3 (C)
if1_e: Q6.2 (E), R40.1
inj: C65.1, TP1.1 (1_1)
ln_b: C55.2, C56.1, Q1.1 (B), R9.2, R13.1
ln_c: C59.2, Q1.3 (C), R23.2, R55.1
ln_e: Q1.2 (E), R37.1
lna_e2: C49.1, R37.2, R42.1
lna_fb: C55.1, R55.2
lna_in: C56.2, R65.2
lnk_a: L1.4 (lka), L7.4 (lka)
lnk_b: L1.5 (lkb), L7.5 (lkb)
lo: C12.1, C13.1, L11.1, R60.1
mix_e: Q2.2 (E), R38.1
n1: D1.1 (K), D2.2 (A)
n2: D3.1 (K), D4.2 (A)
n_lo: C12.2, C13.2, C35.1, C58.1
n_rf2: C59.1, C60.2
o_b: C22.1, Q3.1 (B), R1.2, R2.1, Y1.1
osc: C22.2, C26.1, C32.2, Q3.2 (E), R35.1
out: C45.1, D1.2 (A), D4.1 (K), R57.1, R61.2
st2: C43.2, L3.2 (tap)
st3: C44.2, L4.2 (tap)
tap1: C42.2, L2.2 (tap)
tapA: C23.2, C24.1, J1.1 (In)
tapB: C27.2, C28.1, J2.1 (In), R65.1
vaud: C61.1, C64.1, Q9.3 (C), R27.1, R36.2, R46.2, R62.2
vb2: C34.1, C74.1, C75.1, C77.1, C78.1, Q8.1 (B), Q13.1 (B), Q17.1 (B), Q20.1 (B), R25.2, R26.1
vb2n: C33.1, Q15.1 (B), R56.2, R63.2, R64.1
vcc: C3.1, C4.1, C36.1, C37.1, C38.1, C39.1, C62.1, C63.1, C76.1, C80.1, C81.1, C82.1, L7.1 (cold), L9.1, L12.2, Q3.3 (C), Q15.3 (C), R1.1, R3.1, R9.1, R10.1, R23.1, R24.1, R25.1, R59.1, R62.1, R63.1, R66.1, R67.1, R68.1, R69.1
vcc_if1: C66.1, C67.1, L2.1 (cold), R11.1, R66.2
vcc_if2: C68.1, C69.1, L3.1 (cold), R16.1, R67.2
vcc_if3: C70.1, C71.1, L4.1 (cold), R19.1, R68.2
vcc_if4: C72.1, C73.1, L6.1 (cold), R21.1, R69.2
vin5: C79.1, J4.19, L12.1
x1: C21.2, R5.1, R8.2
x2: C29.2, R6.1, R12.2
xbase: C40.1, Q4.1 (B), R7.1
xtank1: C3.2, C4.2, L9.2, Q4.3 (C), R59.2
y1: C25.1, Q9.2 (B), R8.1
y2: C30.1, Q14.2 (B), R12.1
y4: Q18.2 (B), R17.1

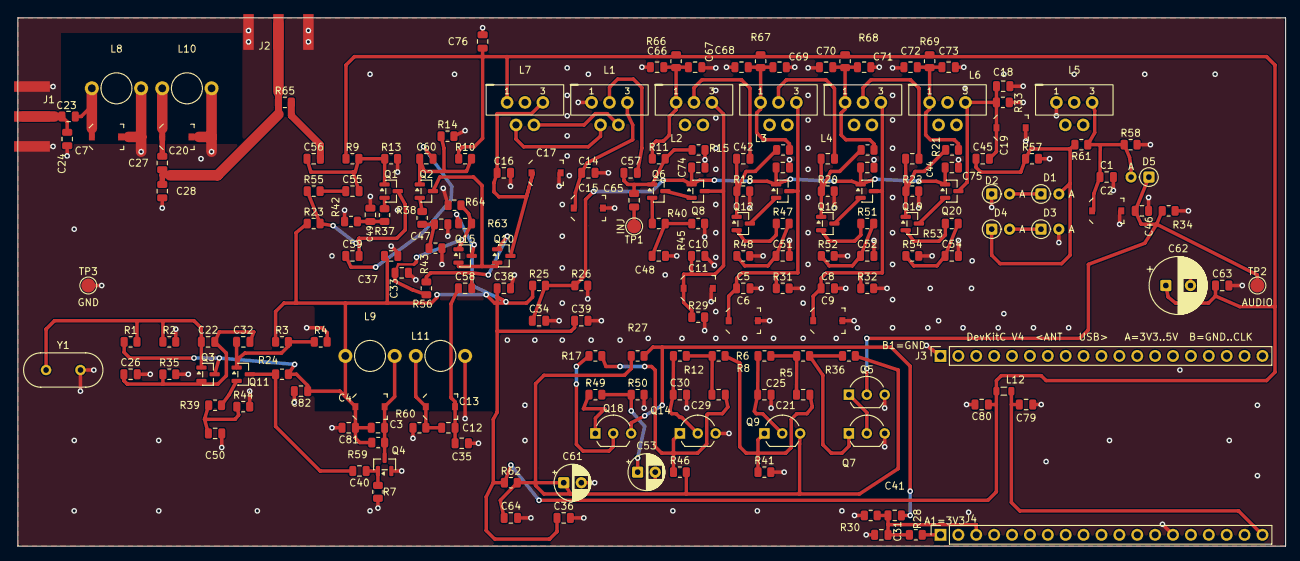
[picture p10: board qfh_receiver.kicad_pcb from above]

Board: 2 copper layers, 180.0 x 75.0 mm, 196 parts (0 on the bottom side), 84 nets.

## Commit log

2026-09-27 First version
    [pins.csv, qfh_receiver.kicad_pcb, qfh_receiver.kicad_sch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]
2026-09-27 Tidy folders: simulations/ and fabrication/
    [pins.csv, qfh_receiver_bom.csv]
